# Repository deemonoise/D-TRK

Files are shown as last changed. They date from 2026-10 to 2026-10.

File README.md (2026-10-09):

# D-TRK

A 16-track tracker with a built-in synthesizer on the **WT32-SC01 Plus** (ESP32-S3, 480×320 touchscreen).
16 patterns, song mode, Fill (every Nth / Euclid / random) for notes, volume and FX, saving to microSD, MIDI file import.
Built-in sound: FM, 808 / 909 drum machines, the SYNTH synthesizer (saw / square / triangle and wavetable), a sampler and chiptune, played through the board's built-in amplifier — each track plays either the internal synth or external MIDI.

User manual: [docs/manual.md](docs/manual.md). Русская версия: [README_ru.md](README_ru.md).
3D-printable enclosure and battery power circuit: [enclosure/](enclosure/README.md).

## Wiring

The built-in display, touch panel and microSD slot are already routed on the board. You only need to connect the controls and the MIDI output — to the board's expansion connector (Extended IO); the track buttons go to the Debug connector. Full soldering diagram (power, MIDI, buttons, headphones): [docs/wiring.md](docs/wiring.md).

| GPIO | What to connect | How |
|---|---|---|
| 10 | MIDI OUT | through a 10 Ω resistor to the Tip of the TRS jack (see diagram below) |
| 11 | Encoder, pin A | the other end — the encoder's common pin to GND |
| 12 | Encoder, pin B | |
| 13 | Encoder button | button between GPIO and GND |
| 14 | **Play** button | button between GPIO and GND |
| 21 | **Shift** button | button between GPIO and GND |
| 43 / 44 | Track buttons: SDA / SCL of the PCF8575 module | Debug connector (TXD0 / RXD0), optional, see below |
| 3.3V | MIDI OUT | through a 33 Ω resistor to the Ring of the TRS jack |
| GND | Common | encoder common pin, the other pins of the buttons, Sleeve of the TRS jack |

The inputs use the internal pull-up to 3.3 V (`INPUT_PULLUP`), so no external resistors are needed. The buttons short the pin to GND.

### Encoder

A regular mechanical EC11 with a push button (4 pulses per detent). The middle pin of the A–C–B row goes to GND, the outer ones to GPIO 11 and 12. If the value moves the wrong way when turning, swap A and B.

It is a good idea to add 10 nF capacitors from A and B to GND — they reduce contact bounce. The firmware has the PCNT hardware filter and a 5 ms software debounce for the buttons.

### Track buttons (optional)

8 MX buttons and 8 3 mm LEDs in the switch windows, via a PCF8575 expander on I2C (port 0; port 1 is used by the touch panel). There are 16 tracks; the buttons work on the visible half (1–8 or 9–16, see below). If the module does not respond at startup, the firmware runs without it.

| PCF8575 | Connection |
|---|---|
| SDA / SCL | GPIO 43 / 44 (TXD0 / RXD0 of the Debug connector) |
| VCC / GND | 3.3 V / GND (from the same connector) |
| INT | leave unconnected |
| A0–A2 | any: the firmware looks for the module at 0x20–0x27 |
| P00–P07 | buttons 1–8, other pin to GND |
| P10–P17 | LED 1–8 cathodes |

The pin mapping is set in `src/hw/pins.h` (`kTrackBtnBit`, `kTrackLedBit`): if a pin is damaged, a button can be moved to the pin of an unfitted LED (number 8–15 = P10–P17), and that LED marked as `0xFF`.

```
+3.3V ──[330 Ω]──|>|── P1x     (LED is lit when P1x = 0)
```

- 330 Ω — for red/yellow/green LEDs (≈ 4 mA). White and blue ones don't have enough headroom at 3.3 V: use 47–68 Ω, and brightness will vary from unit to unit.
- The PCF8575 pulls a pin down (up to 25 mA) but up only with a weak pull-up, so the LEDs are switched only on the cathode, as in the diagram.
- 4.7 kΩ SDA/SCL pull-ups to 3.3 V are usually already on the module — check.
- INT is not needed: the firmware polls the module every 5 ms. The detected address is printed to the USB log (`trackio: PCF8575 at 0x..`).
- If the A0–A2 pads are not bridged anywhere and the module has no resistors to GND, the address floats and may "wander" — in that case bridge the pads to GND.
- GPIO 43/44 are free because the log and flashing go through the native USB (`ARDUINO_USB_CDC_ON_BOOT=1`). At startup the ESP32 bootloader prints to TXD0 (GPIO 43) — this does not bother the module.
- The buttons and LEDs work on the visible half of the tracks — 1–8 or 9–16; the half is chosen by the cursor (move past track 8 and the second half is shown; the GRID header shows `1-8` / `9-16`). Button N selects track N of that half, Shift + N mutes the same track (the toast shows the real number, 1–16), and in GRID edit mode the buttons enter scale degrees. LED N is the same track: lit for the selected one, flashes on notes; activity in the other half is not shown. Details in the [manual](docs/manual.md#trackkeys).

### MIDI OUT (TRS type A, 3.3 V)

```
+3.3V  ──[33 Ω]── Ring   (MIDI DIN pin 4)
GPIO10 ──[10 Ω]── Tip    (MIDI DIN pin 5)
GND    ────────── Sleeve (MIDI DIN pin 2, shield)
```

- TRS **type A** pinout (MMA standard): Tip = pin 5, Ring = pin 4. Type B devices (some Arturia, Novation) need an A→B adapter, or swap Tip and Ring.
- For a 5-pin DIN jack: the same resistors on pin 4 and pin 5, GND on pin 2.
- Non-inverted UART, 31250 baud. Optionally, a 74HC14 buffer (two inverters in series) can be placed between GPIO10 and the 10 Ω resistor.
- There is no MIDI input: the device is always the master and sends clock, Start/Stop/Continue.

### Built-in peripherals (for reference)

| Block | Pins |
|---|---|
| microSD (SPI) | CS 41, MOSI 40, CLK 39, MISO 38 |
| FT6336U touch (I2C) | SDA 6, SCL 5, INT 7, RST 4 (shared with LCD) |
| ST7796 display | 8080 bus, 8-bit (internal board routing) |

GPIO 1, 2, 42 go to the built-in RS485 transceiver; only the A/B lines reach the connector. GPIO 35, 36, 37 are I2S to the built-in NS4168 amplifier (built-in sound, see below). GPIO 43/44 (Debug connector) are used by the track buttons.

## Sound

Built-in synthesizer: 32 instruments (FM — 8 machines; DRUM — 16 machines in the spirit of the TR-808 / TR-909; SYNTH — 2 oscillators BL saw / square / tri or wavetable, sub, noise, sync; SAMPLE — project samples, played from flash; CHIP — pulse, triangle, saw, noise, metal, 16 wavetables; see below), each with a filter and LFO, 16 voices, 32 kHz, mono. A track is switched in TRACK → Out: INT (default in a new project) or MIDI. Sound goes to the built-in NS4168 amplifier — the **SPK** connector on the board, no soldering needed. Master volume: MIX tab → MAIN, 0–200 % (above 100 % — up to +6 dB, peaks of loud chords are softly clipped); saved with the project and included in Render WAV. Output level of the device (headphones / speaker): PROJ → SYS → Phones, 0–100 %, a device setting stored in the board's memory.

> **WARNING: the SPK output is bridged (BTL).** Both pins of the connector carry signal, **neither of them is ground**.
> - Speaker (4–8 Ω) — directly across the two SPK pins.
> - Headphones — only through an **isolated** jack (the jack body does not touch the device enclosure or GND), with **100–220 Ω resistors in series**. Start at minimum volume.
> - **Never** connect the SPK pins to the board's GND, to the ground of other devices, or to line inputs (mixer, audio interface, amplifier, recorder) — this shorts the amplifier output and risks burning it or the connected device. A line output needs a separate DAC (see [plans](docs/plans/future-audio.md)).

### Headphone jack (optional)

A 3.5 mm stereo jack (TRS), mono signal to both ears. Connects to the SPK connector in parallel with the speaker or instead of it.

```
SPK+ ──[150 Ω]──┬── Tip    (left)
SPK+ ──[150 Ω]──┴── Ring   (right)       each ear through its own resistor
SPK− ────────────── Sleeve (common)      NOT GND! jack is isolated
```

Speaker and headphones play together. To be able to switch the speaker off, put a switch in its wire:

```
SPK+ ──[switch]── Speaker (+)
SPK− ──────────── Speaker (−)
```

- 100–220 Ω, 0.25 W resistors, one each on Tip and Ring. Below 100 Ω — loud, with high current through the headphones; higher — quieter. 150 Ω is the middle ground.
- Sleeve goes to **SPK−**, not to GND. The jack sits in a plastic body or a plastic panel (the printed enclosure works); its contacts do not touch GND, the MIDI jack body, USB or other connectors.
- This jack is for **headphones only**. A cable from it to a mixer, audio interface or powered speakers would connect SPK− to their ground: that shorts the amplifier output.
- Before first power-up — Phones (PROJ → SYS) at minimum, headphones off your ears, then bring it up.
- The jack's built-in break contact is not suitable for disconnecting the speaker: on ordinary jacks it is connected to Tip, and Tip goes through a resistor. You need a separate switch or a jack with an isolated pair of switching contacts.

The internal sound lags behind MIDI tracks by about 14 ms (constant, no jitter). Synthesizer load is shown by `CPU NN%` in the right corner of the status bar (average over 0.5 s; yellow from 60% or if at least one block in the window took longer than 4 ms to compute — this is covered by the DMA queue; red from 85% or for 2 s after an audio dropout — an emptied DMA queue, an audible click).

### Samples

- Samples belong to the project: each project has its own list (up to **128**), and an instrument (INST → Sample) chooses only from it. On the card, a project is `/projects/NAME.mtp` plus the folder `/projects/NAME/` with its samples (`<sample>.wav`, mono, 16-bit). The folder is written by Save: missing and changed WAVs are written, files of samples removed from the project are deleted. If the folder could not be written — "SAMPLES NOT SAVED", the project stays unsaved (`*`), and the next Save completes it.
- To move a project to another card or tracker, copy the `.mtp` and its folder (with a card reader or over Wi-Fi). Load and autoload pull samples that are not in flash from the project folder (with progress); if a file is not found or has changed, the sample is marked `MISSING` (silent), toast "N SAMPLES MISSING".
- Flash (the `samples` partition, ~9.9 MB, ≈ 2.5 min mono at 32 kHz, up to 128 entries) is the cache the samples play from. Identical data in different projects is stored once. When space runs out, import and loading evict other projects' samples on their own (largest first) and compact the flash; otherwise "BANK FULL". The cache does not depend on the card, and a normal reflash (USB or OTA) does not touch it. The partition came with a new partition table — after updating from an old version, flash **once over USB** (see [Build and flash](#build-and-flash)), otherwise FILE → SAMPLES shows "NO SAMPLE BANK".
- FILE → SAMPLES: the line `FREE n / m KB  CACHE k KB` (CACHE — space taken by other projects' samples), **Import WAV…**, **Compact** (compact the flash), **Clear cache** (remove from flash everything not in the current project), then the project's samples: name, length, size, red `MISSING`. Click a sample — **Rename** (also renames it in instruments; a MISSING sample cannot be renamed) or **Delete** (remove from the project; the next Save deletes the file).
- `/samples` on the card (created automatically) is the import library, subfolders allowed up to 4 levels. Import WAV…: folders first (`name/`, click to enter, `< Up (..)` to go up), then `.wav` files; hidden files (macOS `._*`) are not shown. Play on a file previews it (first 8 s, Play again stops; in this list the Play button does not start the transport). An imported sample goes into the project folder on save.
- WAV: PCM **8 / 16 / 24-bit**, mono or stereo (stereo is mixed down to mono), any sample rate: above 32 kHz it is downsampled to 32 kHz, lower rates are stored as is. **Float and 32-bit are not supported** ("UNSUPPORTED WAV").
- Import, Rename, Delete, Compact and Clear cache work only with playback stopped (writing to flash stops the sound).
- Old projects (from when samples were shared): on load the list is built from the instruments, and samples are taken from flash by their old names. Save such a project once and its folder will appear.
- `.wav` files can be uploaded over Wi-Fi to `/samples` (and subfolders, up to 4 MB) or straight into the project folder (up to 10 MB).

### FM

**FM** — 8 machines in the style of the Model:Cycles: KICK, SNARE, METAL, PERC, TONE, CHORD, CLAP, HAT. Instead of operators there are 5 macros: DECAY (length), COLOR (brightness / index), SHAPE (timbre variant; for CHORD — chord type), SWEEP and CONTOUR (pitch or index envelope). Percussion plays one-shot (note length and ADSR don't matter, a new note cuts off the previous one); TONE and CHORD hold the note (attack / sustain / release from the ADSR). TONE can be POLY; the other machines are mono per track.

P-lock: fx `DEC`, `COL`, `SHP`, `SWP`, `CON` (0–127) set a macro for the note on their step; on a step without a note — for the playing note until the next one. They work on FM, DRUM and SYNTH.

### KIT (drum track)

The **KIT** instrument type has 8 lanes: each is either its own mini-sampler (a project sample, Volume, Pitch, Decay) or a reference to any of the 32 instruments. A track with a KIT becomes a drum track: in GRID, instead of notes there are 8 squares per step; in edit mode, a pad of 8 buttons (and track buttons 1–8) toggles the lanes. Each lane is mono with choke; lanes sound together. On a MIDI track, the lanes are sent as their own notes (the lane's Note) — for an external drum machine. Fx `ACC` is a mask of lanes at full volume, the rest at 60 %. Fill (NOTE) writes to the selected lane. More in the [manual](docs/manual.md#drumtrack).

### DRUM (808 / 909)

**DRUM** — 16 "analog" machines: BD8, SD8, TOM8, CP8, RS8, CL8, CB8, HH8, CY8 (808) and BD9, SD9, TOM9, CP9, RS9, HH9, CY9 (909). The same 5 macro slots and `DEC…CON` locks, but each machine names them differently (TONE, SNAPPY, DRIVE, N.DEC, HP…); an empty slot is a grey "-". Every machine has DECAY. All machines are one-shot and mono per track: a new note cuts off the previous one (choke), note-off doesn't matter; Attack, Decay, Sustain, Release, Mode, Glide are greyed out. Note C4 is the machine's base pitch. Closed / open hat — short and long DECAY. The timbres approximate the originals (the 909 hats and cymbals are samples there, synthesis here). FM, DRUM and SYNTH with a WT oscillator together — no more than 8 voices at once (an extra one steals the oldest).

### SYNTH (oscillators and wavetable)

**SYNTH** — an "analog" synthesizer: 2 oscillators, each in **SAW**, **SQR**, **TRI** mode (alias-free, PolyBLEP) or **WT** (a wavetable of 64 frames × 256 points with mipmaps, frame position = SHAPE), plus sub (a square −1 / −2 octaves below osc 1), white noise, hard sync of osc 2 to osc 1, osc 2 semitones (±24) and its own AD envelope on SHAPE (Env>Shp ±). The volume envelope is ADSR; Mode POLY / MONO and Glide work as on CHIP. INST pages: MAIN / ENV / **OSC** / **MOD** / FILT / LFO.

- 5 macros on the same slots as FM / DRUM: **SHP1** (square PW or WT frame of osc 1), **SHP2** (the same for osc 2), **MIX** (osc 1 ↔ osc 2), **DET** (osc 2 detune, ±50 cents), **SENV** (env→SHAPE depth). Locks are fx `DEC`, `COL`, `SHP`, `SWP`, `CON` respectively; LFO dest — SHP1…SENV.
- Wavetables: 8 built-in (`*SAWSQR`, `*PWM`, `*SINSAW`, `*TRISQR`, `*FORMANT`, `*ORGAN`, `*SYNC`, `*BELL`) — built into the flash bank on first start, work without a card. Your own — **IMPORT…** in the wavetable chooser (tap / click the Table row) from `/wavetables` on the card (with subfolders up to 4 levels): WaveEdit (256-point frames, up to 64) and Serum / Vital (2048-point frames or a `clm` chunk; with more than 64 frames, they are taken evenly). One wavetable takes 96 KB of flash; up to 32 wavetables per project. A name already in use with different data gets a `-2`, `-3`… suffix.
- Save writes the project's wavetables to `/projects/NAME/wt/<name>.wav`, and Load pulls missing ones into flash from there. If a wavetable is neither in flash nor in the folder, its name in INST is red and the oscillator is silent.
- Import works only with playback stopped ("STOP PLAYBACK FIRST"). 37 factory presets (BASS, LEAD, PAD, KEYS, PLUCK, FX) on the built-in wavetables; your own go in `/presets/SYNTH/`.

### Filter and LFO

All types have these at the end of the INST list:

- **Filter** OFF / LP / BP / HP (SVF, 12 dB/oct), **Cutoff** 20 Hz…14 kHz, **Reso** 0–127, **Flt env** ±6 octaves with its own **Flt attack** / **Flt decay** (HOLD — hold), **Key track** 0–100 % (from C4). The filter comes after the whole voice; OFF is a bypass, so old projects sound as before.
- **LFO** wave / rate / depth / dest — now on all types. Targets PITCH, VOL, CUTOFF — everywhere; DECAY…CONTOUR — only FM, DRUM and SYNTH (on SYNTH — SHP1…SENV).
- Filter p-locks: fx `FLT` (cutoff) and `RES` (resonance), 0–127, on any INT instrument with the filter enabled; on a step without a note — for the track's playing voices until the next note.

### Drive, reverb, compressor

- **Drive** (INST → FILT, first row): tanh overdrive before the filter, lock `DRV`, LFO target `DRIVE`.
- **Reverb**: the instrument's Rvb send (lock `RVB`), size / decay / level in PROJ. 23 KB buffer in PSRAM.
- **Compressor** on all built-in sound (PROJ → Comp, Comp rel) with **sidechain** from a track (SC track, SC depth): set SC track to the kick and the mix "pumps".
- **ARP**: fx `ARM` sets the order (up, down, up-down, random) and the number of notes per step (1–8); ARP + CHD on the same step arpeggiates the chord.
- **4 LFOs** per instrument (INST → LFO), each with a free Hz rate or tempo sync (1/32 … 8 bars) and the phase retriggered on every note or free-running (Retrig ON / OFF).
- **Lo-fi**: fx `BIT` (bit depth) and `SRR` (sample rate) per note; **DJ filter** on the master (PROJ → FX).
- Pattern **groove** (PROJ → SONG → Groove: MPC 54–66, SHUFFLE, PUSH, LAID BACK, DRUNK, BOOM BAP, HOUSE) and track **Humanize** (TRACK → NOTE); conditions `CND PRE / NEI`, volume ramp up/down on `RAT` (`4^`, `4v`).
- **Step arp** `ARS` (INT and MIDI): the CHD notes (or ARP 0/x/y, or the note itself) across a range of 1–4 octaves play as separate notes on the track's following empty steps — every step or every N; until the next note, OFF or a pattern change. The fx list in GRID is grouped: notes and arp, timing, randomness, pitch and volume, sound, sample, sends, MIDI.
- **Velocity**: Vel>Cut (filter cutoff) and Vel>Dec (DECAY macro) in INST → ENV.

Everything is off by default: old projects and presets sound as before. Presets with the new fields are version 4; old firmware cannot open them.

### Presets

The **PRESET** button in the INST header (or Shift + long press of the encoder) → **Load** / **Save**.

- **Load:** a list for the instrument type (arrows in the header or Shift + turn — another type). At the root — `[FACTORY]` (145 factory presets: 33 CHIP, 37 FM, 38 DRUM, 37 SYNTH, by category; up to 63 rows are visible in one category or folder), then your own folders and files. The selected preset is applied to the instrument immediately and plays C4. **OK** — keep it, **CANCEL** (or a long press) — revert, **DEL** — delete your own preset.
- **Save:** **SAVE** — name on the keyboard (if it already exists, asks whether to overwrite), **+DIR** — new folder, click a file — overwrite it. The file name also becomes the instrument name.
- On the card: `/presets/CHIP|SAMPLE|FM|DRUM|SYNTH/…/NAME.mti` (204 bytes, format v3; old v1 / v2 are readable), up to 4 folder levels inside a type. A SAMPLE preset applies its sample only if it is in the project; otherwise the sample and Root stay as they were. A SYNTH preset stores wavetable names: if a wavetable is not in the project, it is imported from `/wavetables/<name>.wav` (with playback stopped); otherwise the name is red.

Details (INST tab, preset browser, DRUM machine table, SYNTH and wavetables, fx SLD/VIB/ARP/VSL/OFS/CUT, DEC/COL/SHP/SWP/CON, FLT/RES) are in the [manual](docs/manual.md#sound).

## Song and live performance

- **Song mode** (BANK): each chain entry has a pattern, a transposition of melodic tracks (±24), a number of passes (x1–x16) and a mute scene (S1–S8) that is applied when the entry starts. The chain row reads `P05 +3 x2 S1`; Shift + turn in row edit mode selects the field.
- **Mute scenes**: 8 tiles under the chain — tap recalls, long tap stores the current mutes, Shift + tap clears.
- **Per-track length** (TRACK → Pat len): the track loops its first N steps within the pattern (polymeter); in GRID the steps beyond are grey, and the boundary is marked with a line.
- **Fill**: hold Shift + Play while playing — steps with `CND FIL` play, those with `NFL` are silent; a short press is pause, as before.
- **REC** (GRID menu): while playing, the track buttons write scale degrees into the playing step of the current track (on a drum track — lanes); Shift + N erases.
- **PERF** (GRID menu): an effect while the button is held — 1 RAT 2, 2 RAT 4, 3 filter closed, 4 open, 5 delay, 6 short DECAY, 7 fade, 8 mute.

More in the [manual](docs/manual.md#song).

## Mixer and render

- **MIX** is a separate tab at the bottom, next to TRACK: 8 strips for the half of the tracks under the cursor (volume fader, delay / reverb sends, M / S) and the MAIN strip — overall volume 0–200 % (moved here from PROJ).
- Track volume from any screen: hold its button and turn the encoder (Shift ×10); not in GRID edit mode, REC or PERF.
- **FILE → Render WAV…**: a pattern or the whole song (ALL, solo tracks only, or STEMS — each track to its own file) to `/samples/render/<project>_P01.wav` / `_SONG.wav`, mono 16-bit 32 kHz, with delay / reverb / compressor and a 2 s tail. The file can be downloaded over Wi-Fi or imported back as a sample.
- **GRID → Resample track / pattern**: a pattern (the current track or all audible ones) into a new project sample `RS1`, `RS2`… — normalized to −1 dBFS, trailing silence trimmed, up to 60 s.
- Render and resampling work only when stopped, roughly in real time; cancel with a long press of the encoder or Play.

More in the [manual](docs/manual.md#render).

## Interface

- **Themes**: PROJ → SYS → Theme, 17 built-in themes (CLASSIC, AMBER, PHOSPHOR, NORD, DRACULA, SOLARIZED, GRUVBOX, MONOKAI, TOKYO, MOCHA, ROSE PINE, GAMEBOY, C64, SYNTHWAVE, OCEAN, CONTRAST, PAPER). A device setting: stored in the board's memory, does not change the project.
- **Pages** in TRACK (MAIN / NOTE / MIDI) and PROJ (SONG / FX / COMP / SYS): tap a page tab, or use the encoder on the page tabs and click (Shift+click — back); the list wraps around.
- **PERF**: the effect of each button is configured in PROJ → PERF (RAT 2/3/4/8, ROLL UP, FILTER LOW/HIGH, DELAY/REVERB MAX, CRUSH, DOWNSAMPLE, DRIVE, SHORT DECAY, FADE, MUTE); pressing shows a toast with its name.
- **Project templates** (FILE → New: EMPTY, 808 SET, 909 SET, FM SET, CHIPTUNE, MIDI 8 and your own from `/templates`, Save as template), **8 demo songs** (FILE → New → Demo songs: trance, chiptune, acid, lo-fi, synthwave, dub techno, IDM, house), **autosave** to `/projects/<name>.auto` (PROJ → SYS → Autosave, FILE → Restore autosave), **safe start** (hold Shift at power-on — no autoload), **crash log** `/projects/crashlog.txt` and the firmware version in PROJ → SYS.
- **Wi-Fi page**: tabs per section, scrollable lists with a filter.
- **MIX**: encoder — MAIN volume, Shift+turn — tracks A (1–8) / B (9–16); track volume — its button + encoder, mute — Shift+button, solo — tap. Each track has a level meter; at the bottom there is a scope with auto-gain and a level meter / CLIP.

## SD card

**FAT32** with an **MBR** partition scheme. exFAT (the standard for cards over 32 GB) and GPT are not readable — the screen will show "NO SD CARD".

Format it with any tool that offers FAT32 with an MBR partition table (for cards over 32 GB the system formatter often offers only exFAT: use a third-party FAT32 formatter). Formatting erases the card.

The firmware creates the folders `/projects`, `/midi`, `/samples`, `/wavetables` and `/presets` (with subfolders `FM`, `DRUM`, `SAMPLE`, `CHIP`, `SYNTH`) itself. Put MIDI files for import in `/midi`, WAVs for importing into projects in `/samples`, wavetables for SYNTH in `/wavetables`. A project's samples live in `/projects/NAME/`, its wavetables in `/projects/NAME/wt/` (written by the tracker on save), instrument presets in `/presets/<TYPE>/`.

## Wi-Fi

FILE → **Wi-Fi transfer…**: the tracker joins your home network (network and password are entered on screen and stored in flash) and serves the page `http://d-trk.local` (or by the IP shown on screen). On the page:

- MIDI (`/midi`, `.mid` only, up to 512 KB), projects (`/projects`, `.mtp`/`.bak`) and samples (`/samples`, `.wav` only, up to 4 MB): upload, download, rename, delete; samples from `/samples` are then imported into a project on the tracker (FILE → SAMPLES);
- in the projects section, each project has a `name/` row (marked "samples") with its WAVs (up to 10 MB, name up to 16 characters): enter, upload, download, rename, delete. To move a project, upload the `.mtp`, open its "samples" row and upload the WAVs; if the folder does not exist yet, the first WAV creates it. Renaming a `.mtp` moves the folder, deleting a project (both `.mtp` and `.bak`) deletes it — except for the project open on the tracker: its folder stays (files in it can be changed; the next Save rewrites them from flash);
- wavetables (`/wavetables`, `.wav` only, up to ~3 MB, subfolders as for samples): imported into a project on the tracker (INST → SYNTH → Table → IMPORT…). The project's wavetables are in the project folder, subfolder `wt/` (marked "wavetables");
- in the samples section — subfolders: breadcrumb navigation, "New folder", deleting an empty folder; folder name up to 32 characters (Latin letters, digits, space, `.` `_` `-`, not starting with a dot), no deeper than 4 levels. MIDI has no subfolders;
- presets (`/presets`, `.mti` only, up to 1 KB, name up to 16 characters): at the root — type folders CHIP, SAMPLE, FM, DRUM, SYNTH (cannot be deleted), files only inside them, your own subfolders up to 4 levels. An uploaded preset is checked (CRC, version) and must be in the folder of its type, otherwise it is rejected;
- firmware update with the file `.pio/build/wt32/firmware.bin`.

While this mode is open, playback is stopped. Exit with EXIT, a long press of the encoder or another tab; Wi-Fi is turned off.

**Security:** the page has no password. While the mode is open, anyone on the same network can change files on the card and flash the tracker. Do not enable it on other people's or public networks.

More in the [manual](docs/manual.md#wifi).

## Build and flash

You need [PlatformIO](https://platformio.org/).

```
pio run -e wt32 -t upload     # build and flash over USB
pio run -e wt32-ota -t upload # over Wi-Fi: FILE → Wi-Fi transfer open on the tracker
pio test -e native            # core tests on the computer
```

The partition table is custom (`partitions.csv`): two 3 MB firmware slots and a `samples` partition (~9.9 MB) for the sample flash cache. After switching to it, flash once over USB (`pio run -e wt32 -t upload`): OTA does not change the partition table. Wi-Fi settings (NVS) are kept — `nvs` and `otadata` are at the same addresses.

## Structure

| Folder | Contents |
|---|---|
| `lib/core` | hardware-independent core: model, sequencer, fx, scales, Euclid and Fill, file format, MIDI parser, synthesizer (CHIP, SAMPLE, FM, DRUM, filter), WAV parser, sample bank, project sample list, presets |
| `src/engine` | sequencer task on core 0 (timer, MIDI output) |
| `src/audio` | built-in sound: I2S to the NS4168 amplifier, audio task, sample bank in flash, WAV import |
| `src/hw` | input (encoder, buttons), MIDI UART, SD, display configuration |
| `src/ui` | UI screens |
| `src/storage` | saving and loading projects and presets |
| `src/net` | Wi-Fi, file transfer web page, OTA |
| `test` | Unity tests of the core |
| `docs` | manual and development plans |
| `enclosure` | enclosure: OpenSCAD model and STL |

## License

Copyright © 2026 deemonoise.

- **Firmware, tests, scripts and documentation** — [GNU GPL v3](LICENSE) (GPL-3.0-only). You may use, change and share them, sell devices with them included, as long as the source of the firmware you ship (with your changes) is published under the same license.
- **Hardware** — the enclosure ([enclosure/](enclosure/): OpenSCAD sources and STL) and the wiring diagrams ([docs/img](docs/img)) — [CERN-OHL-S v2](enclosure/LICENSE) (CERN-OHL-S-2.0): products made from them must make their modified design sources available under the same license.

The name **D-TRK** and its logo are not covered by these licenses: a modified firmware or a device built from this project may say it is based on D-TRK, but must not be called or sold as D-TRK without permission.

Full texts: [LICENSES/](LICENSES/). Third-party libraries (ESP-IDF, Arduino-ESP32, LovyanGFX, Unity) keep their own licenses.

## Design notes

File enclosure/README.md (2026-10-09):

# D-TRK enclosure

Русская версия: [README_ru.md](README_ru.md)

Parametric model for 3D printing: [case.scad](case.scad) (OpenSCAD 2021.01). Ready-made STLs are in [stl/](stl/).

Overall size ~98.4 × 105.4 × 31 mm. On top: the whole WT32-SC01 Plus module (glass with bezel), with Shift, Play (MX) and the EC11 encoder below it. At the back: the charging Type-C (IP5306), the MIDI OUT mini jack and the power switch.

| File | Qty | How to print |
|---|---|---|
| `stl/case_top.stl` | 1 | face down on the bed, no supports |
| `stl/case_bottom.stl` | 1 | bottom down on the bed, no supports |
| `stl/clamp2.stl` | 1 plate (4 clamps) | flat, pins up |
| `stl/knob.stl` or `stl/knob8.stl` (case with track buttons) | 1 | top down on the bed, no supports ([knob.scad](knob.scad)) |

**Version with 8 track buttons** (Shift, Play and the encoder under the screen, 2 rows × 4 MX below them, PCF8575 expander; see the [plan](../docs/plans/future-track-buttons.md)): overall size 98.4 × 145.4 × 31 mm; print `stl/case8_top.stl` and `stl/case8_bottom.stl` instead of `case_*`, the clamps are the same. The 3 mm LEDs go into the standard windows of the MX switches (you need clear keycaps or keycaps with a window); the case does not change for them. Wiring is in the [README](../README.md#track-buttons-optional).

PLA/PETG, 3 wall perimeters, 20–30 % infill.

The bottom part is a tray 4.5 mm deep (`tray_h`) with a 3 mm floor: the battery sits 4.5 mm below the joint with the top, with 6 mm clearance to the module. Along the edge runs a 1.2 × 1.5 mm centring lip (`guide_t`, `guide_h`, clearance `guide_clr` = 0.2) that fits inside the top. If the fit is tight, reduce `guide_t` or increase `guide_clr`. The top does not depend on `tray_h`: you can change the tray depth without reprinting the top.

## Measure before printing

All dimensions are variables at the start of `case.scad`. Check with calipers:

| What | Variables | Default |
|---|---|---|
| Module: width, depth, thickness | `mod_w`, `mod_d`, `mod_h` | 92 × 60 × 10.8 |
| Lip over the bezel: overlap and thickness | `lip`, `lip_t` | 1.0 and 1.2 |
| 103450 battery | `bat_w`, `bat_d`, `bat_h` | 50 × 34 × 10 |
| IP5306: board (along the wall × inwards), thickness, Type-C jack | `ip_w`, `ip_d`, `ip_pcb`, `usbc_w`, `usbc_h` | 20 × 26 × 1.2, 9.2 × 3.4 |
| Jack and switch thread | `jack_d`, `sw_d` | 6.3 (M6) |
| Bosses on the module's back: centres from the left/right edge (looking at the screen), from the long edges | `boss_x0`, `boss_x1`, `boss_y` | 10.34, 6.52, 4.3 |
| Bosses: outer ⌀ and hole ⌀ | `boss_d`, `boss_hole` | 6 and 2.5 (not measured) |

`lip` is how far the lip overlaps the module's bezel. Increase it if the bezel is wider and the window shows too much; decrease it if the lip covers the active area of the screen.

The clamps press the module by its 4 corner bosses; the `pin_d` pin (2 mm) goes into the boss hole and keeps the clamp from turning around its screw — `pin_d` must be smaller than `boss_hole`. The 10.34 offset is from the right edge looking at the board, i.e. from the left edge looking at the screen; if the module sits in the case rotated 180°, set `boss_flip = true`. The old bars (v1, 2 pcs. with tape) are `part="clamp"`.

After editing, rebuild the STLs:

```
OS=openscad   # OpenSCAD 2021.01 or newer; give the full path if it is not on PATH
$OS -o stl/case_top.stl    -D 'part="top"'    case.scad
$OS -o stl/case_bottom.stl -D 'part="bottom"' case.scad
$OS -o stl/clamp2.stl      -D 'part="clamp2"' case.scad
```

For the track-button version, add `-D trk=true` and write to `stl/case8_*.stl`. Measure the PCF8575 module: `pcf_w`, `pcf_d` (default 32 × 20).

`part="assembly"` (the default) is an assembly with component mock-ups for checking in OpenSCAD.

The most critical part is the top: print `case_top.stl` first and test-fit the module, then the rest.

## Encoder knob

[knob.scad](knob.scad): ⌀30 × 18 mm, flat top, diamond knurling (two opposing helical grooves, pitch ~2.6 mm — 36 of them on ⌀30, 30° to the axis), fits a D-shaft. The underside is recessed for the nut and threaded bushing, so the knob floats 1 mm above the panel (0.5 mm with the encoder button pressed). The shaft goes 12.5 mm into the knob.

Case with track buttons: the encoder sits on the MX grid (19 mm pitch), and a ⌀30 knob would overlap the keycap below it. For this case use `knob8.stl` — ⌀17 × 18 mm, 21 grooves: 1.5 mm clearance to the 18 mm keycap, more than 10 mm to the screen window and the right wall. The wall around the nut is ~1.4 mm (2.2 without a groove); print with 3–4 perimeters.

Measure the encoder:

| What | Variable | Default |
|---|---|---|
| Shaft from the encoder body's seating plane to the tip | `shaft_l` | 20 |
| Shaft ⌀ and size across the flat | `shaft_d`, `shaft_dd` | 6 and 4.5 |
| Flat length | `flat_l` | 10 |
| Bushing: ⌀ and height | `bush_d`, `bush_l` | 7 and 7 |
| Nut: across flats and height, washer | `nut_af`, `nut_h`, `washer_t` | 10, 2, 0.5 |
| Button travel | `push` | 0.5 |

The knob height depends on `shaft_l`. If it is tight on the shaft, increase `shaft_clr` (0.15); if it wobbles, decrease it. `part="view"` shows the knob on the panel with an encoder mock-up.

```
$OS -o stl/knob.stl knob.scad
$OS -o stl/knob8.stl -D knob_d=17 knob.scad
```

## Hardware and materials

- M3 heat-set inserts (5–6 mm long, outer ⌀ ~4.5) — 8 pcs.
- M3 × 10 DIN 912 screws (socket head cap) — 4 pcs. (bottom part, heads sunk flush).
- M3 × 6 screws — 4 pcs. (clamps).
- ~1 mm foam double-sided tape — under the battery.
- PJ-392 panel-mount mini jack (TRS 3.5 mm, M6 nut).
- MTS-102 toggle switch (M6 nut).
- IP5306 charger/power-bank module with Type-C and USB-A (desolder the USB-A).
- LiPo 103450 battery (~2000 mAh).
- 2 MX switches (10 for the track-button version), EC11 encoder with push button, keycaps.
- Track-button version: PCF8575 module, 8 × 3 mm LEDs, 8 × 330 Ω resistors.

## Power

The IP5306 module charges the LiPo from Type-C by itself and puts out a stable 5 V. Desolder the USB-A socket (otherwise it won't fit height-wise) and solder the output wires to its VBUS and GND pads.

```
LiPo + ── IP5306 B+ (BAT+)
LiPo − ── IP5306 B− (BAT−)
IP5306 VOUT (VBUS USB-A) ── switch ── board 5V
IP5306 GND               ───────────── board GND
```

The switch is on the output, not on the battery: this way charging works even with the device switched off.

IP5306 quirks:
- The output turns on by itself when a load appears (the switch is closed). If it does not, briefly press the module's button or short its pads (KEY) to GND. If there is no button and auto-start is unreliable, move the switch into the battery line, but then charge only with the switch on.
- Below ~50 mA the output shuts off after ~30 s. The board draws ~175 mA, so this is not a problem.
- The output stays on while charging (power comes from Type-C). At the moment charging is connected or disconnected the output may drop briefly and the board will reboot. Connect the charger with the device off, or after saving.
- The charge-level LEDs are on the board inside the case and are not visible from outside.

Do not connect the battery directly to the board's 3.3V or 5V.

The board's own Type-C (flashing) and the microSD slot are accessible only with the lid off. Do not flash with the switch closed: two 5 V sources on the same line.

## Assembly

1. Melt the inserts in with a soldering iron: 4 into the corner posts, 4 into the clamp posts (all in the top part).
2. Insert the module screen-down into the pocket of the top part, until it rests against the lip.
3. Put the clamps' pins into the holes of the module's corner bosses and screw the clamps to the posts with M3 screws.
4. Snap the MX switches into the panel from above. The encoder goes in from below, secured with its nut from above.
5. Fit the jack and the switch into the back-wall holes and tighten their nuts. Turn the switch so the long side of its body (7.9 mm) is vertical.
6. In the bottom part: the IP5306 into its cradle with the Type-C jack towards the back wall, the battery on tape against the ridge under the module.
7. Solder the power (see above); the controls and MIDI OUT per the table in the [root README](../README.md#wiring).
8. Check for ~5 V at the IP5306 output before connecting it to the board, then close the bottom part with 4 M3 × 10 screws.

## License

The enclosure (OpenSCAD sources and STL): © 2026 deemonoise, [CERN-OHL-S v2](LICENSE).

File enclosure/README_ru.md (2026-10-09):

# Корпус D-TRK

Параметрическая модель для 3D-печати: [case.scad](case.scad) (OpenSCAD 2021.01). Готовые STL — в [stl/](stl/).

English: [README.md](README.md)

Габарит ~98,4 × 105,4 × 31 мм. Сверху — модуль WT32-SC01 Plus целиком (стекло с рамкой), под ним Shift, Play (MX) и энкодер EC11. Сзади — Type-C зарядки (IP5306), mini jack MIDI OUT, тумблер питания.

| Файл | Кол-во | Как печатать |
|---|---|---|
| `stl/case_top.stl` | 1 | лицом на стол, без поддержек |
| `stl/case_bottom.stl` | 1 | дном на стол, без поддержек |
| `stl/clamp2.stl` | 1 стол (4 лапки) | плашмя, штырьками вверх |
| `stl/knob.stl` или `stl/knob8.stl` (корпус с кнопками дорожек) | 1 | верхом на стол, без поддержек ([knob.scad](knob.scad)) |

**Вариант с 8 кнопками дорожек** (Shift, Play, энкодер под экраном, под ними 2 ряда × 4 MX, расширитель PCF8575; см. [план](../docs/plans/future-track-buttons.md)): габарит 98,4 × 145,4 × 31 мм, вместо `case_*` печатать `stl/case8_top.stl` и `stl/case8_bottom.stl`, лапки те же. Светодиоды 3 мм ставятся в штатные окна свичей MX (нужны прозрачные колпачки или колпачки с окном), корпус под них не меняется. Схема — в [README](../README_ru.md#кнопки-дорожек-необязательно).

PLA/PETG, стенки 3 периметра, заполнение 20–30 %.

Нижняя часть — корыто глубиной 4,5 мм (`tray_h`) с дном 3 мм: аккумулятор лежит на 4,5 мм ниже стыка с верхом, зазор до модуля 6 мм. По кромке — центрирующая губа 1,2 × 1,5 мм (`guide_t`, `guide_h`, зазор `guide_clr` = 0,2), заходит внутрь верха. Если туго — уменьшить `guide_t` или увеличить `guide_clr`. Верх от `tray_h` не зависит: менять глубину корыта можно без перепечатки верха.

## Замерить перед печатью

Все размеры — переменные в начале `case.scad`. Штангенциркулем проверить:

| Что | Переменные | По умолчанию |
|---|---|---|
| Модуль: ширина, глубина, толщина | `mod_w`, `mod_d`, `mod_h` | 92 × 60 × 10,8 |
| Бортик над рамкой: нахлёст и толщина | `lip`, `lip_t` | 1,0 и 1,2 |
| Аккумулятор 103450 | `bat_w`, `bat_d`, `bat_h` | 50 × 34 × 10 |
| IP5306: плата (вдоль стенки × вглубь), толщина, гнездо Type-C | `ip_w`, `ip_d`, `ip_pcb`, `usbc_w`, `usbc_h` | 20 × 26 × 1,2, 9,2 × 3,4 |
| Резьба jack и тумблера | `jack_d`, `sw_d` | 6,3 (M6) |
| Бобышки на задней стороне модуля: центры от левого/правого края (смотря на экран), от длинных краёв | `boss_x0`, `boss_x1`, `boss_y` | 10,34, 6,52, 4,3 |
| Бобышки: наружный ⌀ и ⌀ отверстия | `boss_d`, `boss_hole` | 6 и 2,5 (не замерены) |

`lip` — насколько бортик заходит на рамку модуля. Увеличить, если рамка шире и окно открывает лишнее; уменьшить, если бортик наезжает на активную область экрана.

Лапки прижимают модуль за 4 угловые бобышки; штырёк `pin_d` (2 мм) входит в отверстие бобышки и не даёт лапке провернуться вокруг винта — `pin_d` должен быть меньше `boss_hole`. Отступ 10,34 — от правого края, смотря на плату, то есть от левого, смотря на экран; если модуль в корпусе развёрнут на 180°, поставить `boss_flip = true`. Старые планки (v1, 2 шт. со скотчем) — `part="clamp"`.

После правки — пересобрать STL:

```
OS=openscad   # OpenSCAD 2021.01 или новее; полный путь, если его нет в PATH
$OS -o stl/case_top.stl    -D 'part="top"'    case.scad
$OS -o stl/case_bottom.stl -D 'part="bottom"' case.scad
$OS -o stl/clamp2.stl      -D 'part="clamp2"' case.scad
```

Вариант с кнопками дорожек — добавить `-D trk=true` и писать в `stl/case8_*.stl`. Модуль PCF8575 замерить: `pcf_w`, `pcf_d` (по умолчанию 32 × 20).

`part="assembly"` (по умолчанию) — сборка с макетами компонентов для проверки в OpenSCAD.

Самая критичная деталь — верх: сначала напечатать `case_top.stl` и примерить модуль, потом остальное.

## Кноб энкодера

[knob.scad](knob.scad): ⌀30 × 18 мм, верх плоский, алмазная накатка (две встречные винтовые канавки, шаг ~2,6 мм — 36 шт. на ⌀30, 30° к оси), посадка на D-вал. Снизу выборка под гайку и резьбовую втулку, поэтому кноб висит над панелью на 1 мм (при нажатии на кнопку энкодера — 0,5 мм). Вал заходит в кноб на 12,5 мм.

Корпус с кнопками дорожек: энкодер стоит в сетке MX (шаг 19), ⌀30 наезжает на колпачок под ним. Для него `knob8.stl` — ⌀17 × 18 мм, 21 канавка: до колпачка 18 мм остаётся 1,5 мм, до окна экрана и правой стенки — больше 10 мм. Стенка вокруг гайки ~1,4 мм (без канавки 2,2), печатать с 3–4 периметрами.

Замерить энкодер:

| Что | Переменная | По умолчанию |
|---|---|---|
| Вал от опорной плоскости корпуса энкодера до конца | `shaft_l` | 20 |
| ⌀ вала и размер по лыске | `shaft_d`, `shaft_dd` | 6 и 4,5 |
| Длина лыски | `flat_l` | 10 |
| Втулка: ⌀ и высота | `bush_d`, `bush_l` | 7 и 7 |
| Гайка: под ключ и высота, шайба | `nut_af`, `nut_h`, `washer_t` | 10, 2, 0,5 |
| Ход кнопки | `push` | 0,5 |

От `shaft_l` зависит высота кноба. Туго садится на вал — увеличить `shaft_clr` (0,15), болтается — уменьшить. `part="view"` — кноб на панели с макетом энкодера.

```
$OS -o stl/knob.stl knob.scad
$OS -o stl/knob8.stl -D knob_d=17 knob.scad
```

## Крепёж и материалы

- Вплавляемые гайки M3 (длина 5–6 мм, внешний ⌀ ~4,5) — 8 шт.
- Винты M3 × 10 DIN 912 (цилиндрическая голова под шестигранник) — 4 шт. (нижняя часть, головы утоплены заподлицо).
- Винты M3 × 6 — 4 шт. (лапки).
- Пористый двусторонний скотч ~1 мм — под аккумулятор.
- Mini jack панельный PJ-392 (TRS 3,5 мм, гайка M6).
- Тумблер MTS-102 (гайка M6).
- Модуль зарядки/повербанка на IP5306 с Type-C и USB-A (USB-A выпаять).
- Аккумулятор LiPo 103450 (~2000 мАч).
- 2 переключателя MX (вариант с кнопками дорожек — 10), энкодер EC11 с кнопкой, колпачки.
- Вариант с кнопками дорожек: модуль PCF8575, 8 светодиодов 3 мм, 8 резисторов 330 Ом.

## Питание

Модуль IP5306 сам заряжает LiPo от Type-C и выдаёт стабильные 5 В. Гнездо USB-A выпаять (иначе не влезет по высоте), провода выхода паять на его площадки VBUS и GND.

```
LiPo + ── IP5306 B+ (BAT+)
LiPo − ── IP5306 B− (BAT−)
IP5306 VOUT (VBUS USB-A) ── тумблер ── 5V платы
IP5306 GND               ───────────── GND платы
```

Тумблер стоит на выходе, а не на аккумуляторе: так зарядка работает и при выключенном устройстве.

Особенности IP5306:
- Выход включается сам, когда появляется нагрузка (замкнули тумблер). Если не включился — коротко нажать кнопку модуля или замкнуть её площадки (KEY) на GND. Если кнопки нет, а автостарт капризничает — перенести тумблер в цепь аккумулятора, но тогда заряжать только во включённом положении.
- При токе меньше ~50 мА выход отключается через ~30 с. Плата берёт ~175 мА, это не мешает.
- Во время зарядки выход работает (питание идёт от Type-C). В момент подключения или отключения зарядки выход может кратко пропасть — плата перезагрузится. Подключать зарядку лучше на выключенном устройстве или после сохранения.
- Светодиоды уровня заряда — на плате внутри корпуса, снаружи не видны.

Аккумулятор напрямую на 3.3V или 5V платы не подключать.

Type-C самой платы (прошивка) и слот microSD доступны только со снятой крышкой. Не прошивать с замкнутым тумблером: два источника 5 В на одной линии.

## Сборка

1. Вплавить гайки паяльником: 4 в угловые стойки, 4 в стойки лапок (все в верхней части).
2. Вставить модуль экраном вниз в карман верхней части, до упора в бортик.
3. Поставить лапки штырьками в отверстия угловых бобышек модуля и прикрутить винтами M3 к стойкам.
4. Защёлкнуть MX-переключатели в панель сверху. Энкодер — снизу, закрепить гайкой сверху.
5. Jack и тумблер — в отверстия задней стенки, затянуть гайками. Тумблер повернуть длинной стороной корпуса (7,9 мм) вертикально.
6. В нижнюю часть: IP5306 в ложемент гнездом Type-C к задней стенке, аккумулятор на скотч в бортик под модулем.
7. Распаять питание (см. выше), органы управления и MIDI OUT — по таблице в [корневом README](../README_ru.md#подключение).
8. Проверить ~5 В на выходе IP5306 до подключения к плате, затем закрыть нижнюю часть 4 винтами M3 × 10.

## Лицензия

Корпус (исходники OpenSCAD и STL): © 2026 deemonoise, [CERN-OHL-S v2](LICENSE).

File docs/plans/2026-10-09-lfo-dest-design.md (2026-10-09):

# Больше LFO dest + LFO на LFO — дизайн

Сейчас у 4 LFO 9 целей: PITCH, 5 макро (DECAY..CONTOUR / SHP1..SENV), VOL, CUTOFF, DRIVE. Нужно —
почти любой параметр синта и модуляция одного LFO другим (rate, depth, retrig).

## Подход
Расширяем `LfoDest`: новые цели дописываются в конец enum (перед Count), диспетчер в `Synth::control`
растёт. Формат файлов не меняется (dest — байт, кодек отсекает `>= Count`; старая прошивка прочтёт
новые dest как PITCH — только при откате). Универсальная матрица (смещение поля + диапазон) отвергнута:
параметры читаются во многих местах с учётом locks, понадобилась бы копия `Instrument` на голос.

Модулируются только непрерывные параметры, слышимые посреди ноты. ADSR-времена, sample start, glide —
нет (читаются на note-on).

## Цели (после DRIVE, по порядку)
| Dest | Типы | Полная глубина (depth ±63 ≈ ±1) |
|---|---|---|
| RESO | все | ±64 к 0..127 (после RES lock), clamp |
| FENV | все | ±64 к fenv (-64..63), clamp |
| DLY | все | ±64 к delay send (после DLY lock) |
| RVB | все | ±64 к reverb send (после RVB lock) |
| BIT | все | ±64 к crush bits (после BIT lock) |
| SRR | все | ±64 к crush rate (после SRR lock) |
| FINE | все | ±1 полутон |
| DUTY | CHIP | ±49 % ширины импульса |
| SUB | SYNTH | ±64 к synSub |
| NOISE | SYNTH | ±64 к synNoise |
| SEMI2 | SYNTH | ±24 полутона к osc 2 |
| L1..L4 RATE | все | частота цели × 2^(±4) (FREE и TEMPO) |
| L1..L4 DEPTH | все | глубина цели × clamp(1 + l, 0, 2), как VOL |
| L1..L4 RTRG | все | цикл источника (фаза через 1) сбрасывает фазу цели в 0 и даёт новое RND; важно лишь depth ≠ 0 |

Чужие типу цели энкодер Dest пропускает: `lfoDestStep(dest, d, type)` вместо флага `macros`
(DECAY..CONTOUR — FM / DRUM / SYNTH, DUTY — CHIP, SUB / NOISE / SEMI2 — SYNTH). LFO не выбирает
L-цели самого себя для RTRG (бессмысленно); RATE / DEPTH на себя — можно. `instrSetType` переводит
невалидный для нового типа dest в PITCH (обобщение нынешнего правила для макро).

## LFO на LFO
Голос хранит выходы своих LFO с прошлого control tick (`lfoOut[kLfos]`, -1..1 × depth/64). Rate- и
depth-модуляции считаются из них: задержка 1 мс, зато порядок не важен — циклы и самомодуляция по RATE
работают. Несколько источников на одну цель суммируются (RATE — сумма в октавах, DEPTH — сумма в
множителе до clamp). RTRG: флаги wrap источников этого tick применяются к целям.

Retrig OFF (общая фаза инструмента, `instLfoPhase_`):
- DEPTH-модуляция применяется к выходу — работает всегда.
- RATE и RTRG общей цели — только от общих (Retrig OFF) источников; считаются в `advanceInstLfos` по
  хранимым выходам инструмента (`instLfoOut_`). Per-voice источники для общей цели игнорируются (у
  голосов разные фазы).

## UI
Строка Dest та же. Имена: `RESO FENV DLY RVB BIT SRR FINE DUTY SUB NOISE SEMI2 L1 RATE .. L4 RATE
L1 DEPTH .. L4 DEPTH L1 RTRG .. L4 RTRG`; у SYNTH макро-имена свои (SHP1..SENV).

## Проверка
native: каждая новая цель двигает своё значение; L RATE меняет скорость цели; L DEPTH при -1 глушит
цель; RTRG сбрасывает фазу на wrap источника; общая цель игнорирует per-voice RATE / RTRG и принимает
общий; `lfoDestStep` пропускает чужие типу цели; `instrSetType` сбрасывает невалидный dest в PITCH;
кодек — round-trip новых dest. Мануал: таблица целей LFO, абзац про LFO на LFO. Железо: L2 RTRG от
медленного SAW, L1 RATE от второго LFO, DLY / RVB «качаются».

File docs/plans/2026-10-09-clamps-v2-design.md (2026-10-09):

# Клэмпы v2 — дизайн

## Цель
Заменить 2 длинные планки на 4 лапки, которые прижимают модуль WT32-SC01 Plus
за угловые цилиндрические бобышки на задней стороне. Верх корпуса не перепечатывать.

## Геометрия бобышек
- Центры: 6,52 мм от одного короткого края, 10,34 мм от другого (шаг 75,14),
  4,3 мм от длинных краёв (шаг 51,39).
- Торец бобышки — задняя плоскость модуля целиком: z = `mod_zb`.
- Диаметры не измерены: `boss_d = 6`, `boss_hole = 2.5` (переменные).
- Сторона 10,34 (Type-C модуля) в корпусе не задана: флаг `boss_flip` меняет отступы местами.

## Решение
- 4 лапки на существующих стойках (`clamp_xs × clamp_ys`), один винт M3 на лапку.
- Лапка = `hull` круга `post_r` вокруг винта и круга `boss_d/2` над бобышкой, толщина `clamp_t`.
- Сверху над бобышкой площадка высотой `foam_t` (вместо скотча) и штырёк `pin_d = 2`,
  `pin_h = 1.5` в отверстие бобышки — центрирует и не даёт лапке провернуться.
- `part = "clamp2"` — 4 лапки на одном столе, штырём вверх. Assembly показывает лапки
  вместо планок. Старый `part = "clamp"` остаётся.

## Документация
`stl/clamp2.stl`; README.md / README_ru.md — таблица печати, крепёж (скотч не нужен),
шаг сборки, команда рендера.

## Проверка
Рендер assembly и STL без ошибок; лапки не пересекаются с модулем и стенками.

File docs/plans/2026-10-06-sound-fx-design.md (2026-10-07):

# Sound fx: drive, reverb, master compressor, ARP modes, velocity — design

Block 4 of the roadmap agreed on 2026-10-06 (after 16 tracks, KIT drum track, song + live). Executed
**after** the SYNTH / wavetable work lands: it touches `synth.cpp`, `synth_voice.h`, `model.h`,
`inst_screen.cpp`, which that agent edits now.

## Goal

Make the INT mix sound finished without external gear: saturation per instrument, a reverb send next
to the delay, a master compressor that can duck to a drum track, a real arpeggiator and velocity that
shapes the sound, not only the level. Old projects and presets sound exactly as before.

## Model

- `LockBit`: `kLockFlt = 5, kLockRes, kLockDly, kLockDrv, kLockRvb, kLocks = 10`; `lockMask` in
  `Voice` and `Synth::TrackRt` becomes `uint16_t` (`static_assert(kLocks <= 16)`).
- `Fx`: `DRV` (drive lock 0..127), `RVB` (reverb send lock 0..127), `ARM` (arp mode, see below)
  appended before `Count`. All three synth-only (`fxSynthOnly`).
- `Instrument`: `drive` 0..127 (0 = bypass), `rsend` 0..127 (reverb send, 0 = none), `velCut`
  -64..63 (velocity → cutoff), `velMac` -64..63 (velocity → DECAY macro, FM / DRUM / SYNTH). All
  default 0.
- `LfoDest::Drive` appended before `Count`; UI name "DRIVE", available on every type.
- `Project`: `rvbSize = 60`, `rvbDamp = 70`, `rvbLevel = 80`; `compAmt = 0` (bypass), `compRel = 50`,
  `scTrack = 0` (off, 1..16 = track), `scDepth = 64`. All 0..127 except `scTrack` 0..kTracks.

## File format

- Instruments: the `FMIN` record (16 bytes, written for every instrument) has bytes 10..15 reserved
  (0): `b[10] = drive`, `b[11] = rsend`, `b[12] = velCut`, `b[13] = velMac` (signed as uint8). Old
  files read 0 = the new defaults; nothing else moves. Presets share the record (`inst_codec`):
  `kPresetVersion` 3 → 4 (newer readers accept older files, older firmware refuses the new ones).
- `AUDI`: 6 → 13 bytes, appended `rvbSize, rvbDamp, rvbLevel, compAmt, compRel, scTrack, scDepth`.
  `readAudi` reads what the chunk holds (6 = old file → defaults for the rest), clamps every value.
  `storage.cpp` snapshot copies the new fields.

## DSP

All at `kSynthRate` = 32 kHz, blocks of 128, control every 32 samples. Signal chain of a voice:
engine → **drive** → filter → (mix, delay send, reverb send, sidechain bus). Block end: delay return,
reverb return, **compressor**, master volume, soft clip.

### Drive (per voice, `synth_drive.h`)

`y = tanh(g x) / tanh(g)`, `g = 1 + drive / 127 * 7` (1..8). A 257-entry table of `tanh` over
[-8, 8] (`kDriveTab[i] = tanh(-8 + i / 16)`), linear interpolation, input clamped to ±8; `1 / tanh(g)`
is computed per control update, not per sample. Drive 0 (after lock and LFO) skips the stage: output
bit-exact to today. Cost ≈ 8 flops / sample / driven voice (~2 % with 16 voices all driven).
Applied in `renderVoice` to `dst` before the filter (the filtered path already renders into `flt[]`;
the unfiltered path renders into a scratch too when driven).

### Reverb (`synth_reverb.h/.cpp`, `mt::Reverb`)

Freeverb-lite, mono. 4 parallel feedback combs, base lengths 1116, 1188, 1277, 1356, actual length
`base * (0.5 + 0.5 * size / 127)` (clamped ≥ 1), feedback `0.70 + 0.28 * size / 127`, one-pole damping
in the loop `d = damp / 127 * 0.4` (`store = out * (1 - d) + store * d`); then 2 series allpasses 556,
441 with g = 0.5. Buffers: **float**, handed in by the caller (`setBuffer(float*, n)`), needed
`1116 + 1188 + 1277 + 1356 + 556 + 441 = 5934` floats = 23.2 KB (PSRAM on the device; no buffer =
silent). Float over int16: no scaling / conversion per tap, same memory traffic class, well under
64 KB. Rendered once per block from the `rsend_` bus: `mix += wet * (rvbLevel / 127 * 0.5)`. Cost per
sample ≈ 4 × 7 + 2 × 5 = 38 flops + 12 buffer accesses ≈ 3–5 % on one core (PSRAM latency dominates;
rings are read sequentially, the 32 KB cache holds them). Delay output does not feed the reverb.
`Synth::reset()` clears the buffer; a size change moves the write index (no glide).

### Compressor (`synth_comp.h`, `mt::Compressor`)

Peak detector on `|key|` with one-pole attack (1 ms) / release (`20 ms × 50^(compRel / 127)` =
20..1000 ms). Key = mix, plus `sc * scDepth / 127 * 4` when `scTrack` is set (`sc_` bus = the summed
voices of that track; the sidechain signal is weighted 4× so a drum track at normal level ducks hard
at depth 127). Threshold `T = -6 dB - 24 dB × compAmt / 127` (linear `exp2(dB / 6.02)`), ratio 4:1,
makeup `+(6 + 24 × compAmt / 127) / 2 / 2 dB` (half the threshold drop, then halved again for
headroom). Gain in dB `= -(envdB - TdB) × 0.75` above threshold, 0 below; computed **once per 8
samples** with `log2f` / `exp2f` and applied per sample (held, no ramp: 8 samples = 0.25 ms, inaudible
at these release times). `compAmt == 0` bypasses the stage bit-exactly. Cost < 1 %.

## Fx

- `DRV` 0..127, default 64: like FLT — on a step with a note the drive of its note-ons, else of the
  track's sounding voices. `RVB` 0..127, default 64: same for the reverb send.
- `ARM` "ARP MODE": `val = mode << 4 | rate`, mode 0 UP, 1 DOWN, 2 UPDOWN, 3 RANDOM, rate 1..8 notes
  per step; default `0x03` (UP, 3 = today's behaviour). Shown `U3`, `D4`, `B2`, `R8`. `fxStep` cycles
  the rate 1..8 then the mode. ARM alone does nothing; it shapes the next `ARP` of the step (same step
  or later steps while the ARP holds: ARM is stored in `TrackRt::arm` and reset with the ARP on a new
  step with a note).
- ARP today (`synth.cpp:516`): three pitches per step, offsets `0, x, y`, each a third of the step.
  With ARM: `n = rate` slots per step, offsets taken from the list `{0, x, y}` (or the chord, below):
  UP cycles forward, DOWN backward, UPDOWN forward then backward without repeating the ends, RANDOM
  picks per slot with the voice RNG. `ARP 00` keeps meaning off.
- **ARP + CHD** on the same step: the sequencer (`step_expand`) emits only the root note-on and a
  synth fx `kSynthArpChord = 0xF1 chord` before it (INT tracks only; MIDI tracks keep playing the full
  chord, they have no ARP). The synth stores the chord's intervals (`chordNotes` from `scale.h`, up to
  4 notes) in `TrackRt::arpNotes[4]` / `arpN` and the ARP cycles those instead of `{0, x, y}`; the
  ARP value is ignored except `00` = off (then the step is expanded as a normal chord).

## Velocity

- `velCut`: cutoff offset in octaves `= velCut / 64 × (vel - 64) / 64 × 6` (vel 64 = no change;
  +63 at vel 127 ≈ +6 octaves, like `fenv` at full depth). Added in `controlFilter` from
  `v.gain × 127` (the note's velocity, VSL excluded: use the velocity stored at note-on, `v.vel`).
- `velMac`: DECAY macro offset `= velMac × (vel - 64) / 64` in macro units (±63), clamped 0..127,
  applied where the macro value is read (`macros()` / the lock fallback) for FM, DRUM, SYNTH voices.
  Both 0 by default, so old projects are unchanged.

## UI

- INST MAIN (9 rows, fills `kListRows`): `… Glide, Send, Rvb send`. FILT page gets `Drive` as its
  first row (pre-filter in the chain; 8 rows). ENV page: `Attack, Decay, Sustain, Release, Vel>Cut,
  Vel>Dec` (`Vel>Dec` grey on CHIP / SAMPLE). LFO Dest gains `DRIVE` for every type.
- PROJ after `Dly level`: `Reverb` (size), `Rvb damp`, `Rvb level`, `Comp` (0 = OFF), `Comp rel`,
  `SC track` (OFF, T1..T16), `SC depth`.
- `fx_info`: `DRV "DRIVE"`, `RVB "REVERB SEND"`, `ARM "ARP MODE"`; `fxFormat(ARM)` = letter + rate.

## CPU

Estimates above: drive ≤ 2 % (all 16 voices driven), reverb 3–5 %, compressor < 1 %. The plan ends
with a bench (`AUDIO_BENCH_FX`) that reads the status-bar CPU figure with and without reverb /
compressor on the 16-voice DRUM bench; the executor writes the measured numbers here.

Measured: **not yet** (2026-10-06, no device in that session). Build `pio run -e wt32-fxbench -t upload`
(drive 100 + reverb send 100 on every bench instrument, reverb level 100, compressor 100 keyed by
track 1), read the status-bar CPU after 10 s, then set PROJ -> Rvb level 0 and Comp OFF and read it
again; fill in: DRUM bench baseline __ %, + drive + reverb __ %, + compressor __ %. Host-side, the
unit tests show drive 0 / Rvb send 0 / Comp OFF are bit-exact bypasses.

## Tests (native)

- Drive: table monotonic, `drive(x, 0) == x` bit-exact, drive 127 saturates (|y| ≤ 1, y(1) ≈ 1).
- Reverb: impulse → non-zero tail that decays below -60 dB within 3 s at size 60; silent without a
  buffer; size 127 tail longer than size 0; level 0 leaves the mix bit-exact.
- Compressor: gain 1 for a -20 dB sine at `compAmt 64`; a 0 dB sine reduced by the expected dB ± 1 dB
  after 50 ms; a loud `scTrack` voice ducks a quiet voice on another track; `compAmt 0` bit-exact.
- ARM: UP / DOWN / UPDOWN orders over one step at rate 4; RANDOM stays within the set; `ARP` without
  `ARM` unchanged (existing `test_synth` ARP tests pass untouched); ARP + CHD cycles the chord
  intervals and the sequencer emits one note-on; MIDI tracks still get the full chord.
- Velocity: vel 127 vs 64 moves the cutoff by `velCut / 64 × 6` octaves (check `flt` cutoff via a
  test hook or the rendered spectrum peak); velMac shifts the DECAY macro.
- Formats: project and preset round trips for every new field; a 6-byte AUDI and an old FMIN record
  give the defaults; out-of-range values clamp; `fxNextCmd` wraps `ARM → None`.

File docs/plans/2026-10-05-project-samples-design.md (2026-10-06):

# Сэмплы как часть проекта

## Задача

Сейчас флеш-банк — общий пул устройства: при загрузке любого проекта видны все когда-либо
импортированные сэмплы, а проект на SD не самодостаточен. Нужно: проект владеет своими сэмплами,
его можно перенести (SD / Wi-Fi) на другое устройство, и сэмплы подтянутся сами.

## Модель

- Флеш-банк — анонимный кэш по содержимому. Имя записи банка = CRC32 данных (int16 после
  конвертации), 8 hex-символов в существующем `name[16]`. Формат таблицы не меняется (v1, 128
  слотов). Одинаковые данные в разных проектах — одна запись; одноимённые разные сэмплы разных
  проектов не конфликтуют.
- `Project::samples[128]`: `{name[17], crc, frames}` + счётчик. `name` — видимое имя, на него
  ссылается `Instrument.sample`; уникально без учёта регистра в пределах проекта.
- `.mtp`: новый chunk `SMPL`. Файл без него читается (миграция ниже).
- Резолв: `SampleSource::find(name)` → элемент `live.samples` → `bank.find(hex crc)`, frames
  сверяются (см. «Конкурентность»).
- SD: `/projects/NAME.mtp` + `/projects/NAME/<sample>.wav` — mono, 16 bit, частота банка (на
  устройстве заливается без даунсемплинга). В WAV свой chunk `mtcr` с CRC данных; без него (файл с
  ПК) CRC считается по содержимому.
- `/samples/` остаётся библиотекой для импорта.

## Потоки

**Импорт WAV** (FILE → SAMPLES → Import): конвертация в банк как сейчас, CRC на лету. Если запись
с таким CRC уже есть — новая удаляется, берётся существующая. Запись переименовывается в hex CRC,
в `live.samples` добавляется элемент. SD не трогается — всё пишет save (работает и для нового
проекта без имени).

**Нехватка места** (импорт и загрузка): удалять записи банка, которых нет в `live.samples`, от
больших к меньшим, пока не влезет; если мешает фрагментация — `compact()`; иначе `BANK FULL`.

**Сохранение** (`storage::save`): `.mtp` как сейчас (tmp → проверка → .bak), затем синхронизация
`/projects/NAME/`: для каждого сэмпла списка без файла или с файлом другого CRC — записать WAV из
флеша (`data()`, mmap); файлы не из списка — удалить. Save as в новое имя пишет папку целиком.
Сэмпл missing (нет в банке) файл не перезаписывает и не удаляет.

**Загрузка** (`storage::load`, autoload): прочитать `.mtp`, остановить движок; для каждого сэмпла
— есть запись `crc` в банке → готово, иначе импорт из `/projects/NAME/<name>.wav` (с проверкой CRC).
Прогресс-бар: файл, байты. Нет файла / битый / CRC не совпал → missing (тишина), в конце тост
`N SAMPLES MISSING`; элемент остаётся в списке.

**Удаление сэмпла** — из списка проекта; банк не трогается, файл удалит следующий save.

**Rename** — только в проекте (+ ссылки инструментов), флеш не трогается.

## UI

- FILE → SAMPLES: список `live.samples` (имя, длина, метка `MISSING`); Import, Rename, Delete;
  строка `BANK: X KB free / cache Y`; Compact; `Clear cache` — удалить из банка всё, что не в
  текущем проекте.
- INST: выбор сэмпла только из `live.samples`.
- Импорт / rename / delete ставят dirty.

## Wi-Fi

Разрешены пути `/projects/<name>/<file>.wav` (upload / download / delete); на странице папка
проекта раскрывается рядом с `.mtp`. Перенос проекта — `.mtp` + WAV по одному. Zip не делаем.

## Миграция

`.mtp` без `SMPL`: список строится из `Instrument.sample` всех инструментов. Имя ищется сначала в
банке по старому имени — найденная запись переименовывается в hex CRC (CRC по данным во флеше), а
пара `имя crc frames` дописывается в `/projects/legacy.idx`; затем в `legacy.idx` (сэмпл уже
мигрировал из другого старого проекта). Не найдено — missing. Первый save пишет папку. Старые
записи, ни на что не сославшиеся, — обычный кэш (уйдут при вытеснении или `Clear cache`).

## Конкурентность

Синт ищет сэмпл только на note-on: имя → линейный поиск в `live.samples` → `bank.find(key)`.
Список меняется (импорт, rename, delete, загрузка) только при остановленном движке, как и банк
сейчас, — гонок нет, отдельная таблица резолва не нужна.

## Тесты (native, lib/core)

- `project_io`: round-trip `SMPL`; старый файл без chunk.
- Синхронизация списка с банком на RAM-флеше: попадание в кэш, импорт, вытеснение, дедуп по CRC,
  missing.
- CRC32 по кускам = CRC целиком.
- Резолв имя → индекс после rename / remove / compact.

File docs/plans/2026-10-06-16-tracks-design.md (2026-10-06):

# 16 tracks — design

## Goal

Double the track count from 8 to 16: one track per MIDI channel and per instrument, room for drums
without starving the melodic parts. Everything else (patterns, chain, fx, undo) keeps working; old
project files load as tracks 1–8 with tracks 9–16 at their defaults.

This is block 1 of the roadmap agreed on 2026-10-06 (blocks: 16 tracks; drum track / KIT; song + live;
sound; mixer + render). The drum track (block 2) builds on it.

## Model

- `kTracks = 16`. `Project::reset()`: track i gets channel i and instrument i (`model.cpp:51`) — the 16
  tracks, 16 MIDI channels and 16 instruments map one to one.
- `Pattern::steps[kTracks][kMaxSteps]`: 16 x 128 x 14 bytes = 28 KB, the project ≈ 460 KB (PSRAM,
  `main.cpp:36`).
- `Undo::kDepth` 32 → 8: snapshots are whole patterns, 8 x 28 KB ≈ 230 KB. Measure free PSRAM after the
  SYNTH / wavetable work lands (its mip tables may live there) before implementing; if short, drop to 4.

## File format

- `TRKS`, `TOUT` already carry a count byte: an 8-track file fills tracks 1–8, 9–16 keep the defaults
  (`readRecords` loops to `count`). Written files carry 16.
- `PATN`: the header stays 4 bytes (pattern, length, resolution, swing). Today the step size is derived
  from the body size assuming `kTracks` tracks (`project_io.cpp:241`); with 16 tracks an 8-track body no
  longer matches. The reader tries, in order, (tracks, step bytes) = (16, 14), (8, 14), (8, 6): the
  body sizes differ for any length (8 x 14 = 16 x 7 and 7 is not a step size), so the match is unique.
  Tracks beyond the file's count stay cleared. Writer: 16 tracks, 14-byte steps, as now.
- Files written by this firmware do not load on older firmware (PATN size mismatch → BadValue), same as
  earlier format bumps.
- MIDI import maps up to 16 MIDI tracks / channels (was 8); `import_dialog` lists 16 target tracks.

## Sequencer and synth

- All per-track loops and arrays are sized by `kTracks`. `kSynthTracks = kTracks + 1` (preview track
  = 16). Lookahead and tick cost double on core 0; it was far from the limit.
- Voices stay 16 (FM + DRUM ≤ 8), oldest-voice stealing as now. After measuring `CPU %` with 16 INT
  tracks decide separately whether to go to 24.

## GRID

- Overview shows 8 track columns (`kColW` 56 px). New state `half_` (0 = tracks 1–8, 1 = 9–16).
  The cursor moving to a track in the other half (encoder with Shift, track button, track name tap,
  `App` track change) switches `half_` and redraws. No other way to switch halves.
- Column headers show `T9…T16`; the status bar track field is two digits (`T12`).
- Detail view: one track, unchanged.
- Selection and Paste: the "not past track 8" clamps become 16 (`edit_ops`). A selection may span the
  halves; only the visible columns are drawn, the model is the full 16 columns.
- Track name tap: mute, Shift — solo, for the visible half.

## Track buttons

- Button N acts on track `half_ * 8 + N`: select (cursor), Shift + N mute, note entry in edit mode as
  now. The LED mask is built from the visible half (selected / mute). Switching the half (by scrolling)
  refreshes the LEDs. `trackio` stays an 8-button driver; the mapping lives in `App`.

## Other screens

- TRACK, INST (instrument assignment), BANK (Copy-to / Clear / Length act on whole patterns), Euclid and
  Transpose dialogs: track number is `kTracks`-bounded and printed with two digits where needed.

## Tests (native)

- `test_model`: `kTracks == 16`, reset defaults (channel i, instrument i for all 16).
- `test_project_io`: an 8-track file (both 6- and 14-byte steps) loads into tracks 1–8 with 9–16 at
  defaults; a 16-track round trip is bit-exact; a PATN body of a wrong size is `BadValue`.
- `test_midi_import` (or the existing import test): 12 channels land on 12 tracks.
- `test_expand` / `edit_ops`: paste reaching track 16, clamped at 16; selection spanning tracks 6–11.
- `test_sequencer`: notes on track 15 are scheduled; `test_synth`: preview track index 16.
- Euclid on track 15.

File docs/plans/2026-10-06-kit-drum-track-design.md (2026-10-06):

# KIT drum track — design

## Goal

A drum track: one track, eight lanes (kick, snare, hats…), an x-o-x grid instead of notes. Variant A of
the roadmap (block 2, after 16 tracks): a new instrument type **KIT** holds eight lanes; each lane is its
own mini sampler (a project sample, volume, pitch, decay) or, optionally, points at one of the 16
instruments. A track whose instrument is a KIT stores lane masks in its steps with no change to the
`Step` layout, so copy / paste / clear / selection / undo work unchanged. On MIDI tracks the lanes go
out as fixed notes (external drum machines); on INT tracks each lane plays mono with choke.

## Model

- `InstrType::Kit` appended before `Count`; `kTypeOrder` (UI order) gets Kit last.
- `constexpr int kKitLanes = 8;`

```cpp
// A KIT lane. instr == kNoInstr: a mini sampler on the project sample `sample` (empty / missing name =
// silent) played at its original pitch (root = note) + pitch semitones, vol, decay (0 = whole sample,
// else envTimeMs(decay) then silence). instr < kInstruments: the lane plays that instrument at `note`.
struct KitLane {
  char sample[kSampleNameMax + 1] = {0};
  uint8_t instr = kNoInstr;  // 0xFF
  uint8_t vol = 100;         // 0..127
  int8_t pitch = 0;          // -24..24 semitones
  uint8_t decay = 0;         // envTimeMs, 0 = play to the end
  uint8_t note = 60;         // MIDI note of the lane: unique in the kit, sent on MIDI tracks
};
```

  `constexpr uint8_t kNoInstr = 0xFF;` moves to `model.h` (it is `Synth::kNoInstr` today; keep the alias).
  `Instrument::kit[kKitLanes]` (8 x 22 = 176 bytes; `Instrument` grows from ~150 to ~330 bytes, x16 ≈ 5
  KB in the project — fine). `kitSetDefaults(m)`: every lane `KitLane()` with `note = 60 + k`. A KIT does
  not sound by itself: its Vol / ADSR / filter / LFO are unused; its `send` (and the reverb send once
  block 4 adds one) is the whole kit's delay send.
- `Project::trackIsDrum(t)`: `instruments[tracks[t].instr].type == Kit`, any `TrackOut`; `kitOf(t)`
  returns that instrument or `nullptr`.
- Drum-track step encoding, `Step` unchanged:
  - `note`: `kNoteEmpty` = empty step, `kNoteOff` = note off (releases every lane), else 0..127 = the
    step's velocity for all its lanes (0 = the track's `defVel`). `hasNote()` is still `note < 128`.
  - `vel`: 8-bit lane mask, bit k = lane k+1 hits. A note step with mask 0 plays nothing (fx still run).
  - A melodic track's steps never carry bit 7 in `vel`. Changing a track's instrument between KIT and
    non-KIT reinterprets its steps; accepted (the manual says so).
- `Fx::ACC` ("ACCENT") appended before `Count`, value 0..255 = lane mask: lanes in the mask play at
  the step velocity, the others at 60 %. Drum tracks only: `fxDrumOnly(Fx)`; elsewhere the slot is kept
  but ignored (drawn dim, like synth fx on MIDI tracks). `fxFormat` prints two hex digits.
- Every other fx applies to the step as a whole, i.e. to all its lanes' notes (RAT ratchets every lane,
  NDG nudges them, DEC / FLT / DLY lock every lane's voice, CND / PRB gate the step). CHD, NRN, STR, TIE,
  ARP, SLD, VIB, SLC are meaningless on a drum track and ignored by `expandStep` there.
- Lane note uniqueness: the UI step functions skip notes other lanes hold. Assigning a SAMPLE-type
  instrument to a lane sets the lane's `note` to that instrument's `root` (the sample keeps its pitch; if
  taken, the next free note up); other types leave `note` alone.
- Project sample rename (`projSampleRename`) renames the name in every KIT lane too, as it does in
  instruments' `sample`. Sample delete leaves the lane name (silent, like a MISSING instrument sample).

## File format

- `KITS` chunk: count byte, then 16 records of `kKitRecSize = kKitLanes * 22 = 176` bytes: per lane
  `sample[17]`, `instr`, `vol`, `pitch`, `decay`, `note`. Reader clamps: `instr` ≥ 16 → `kNoInstr`, `vol`
  → 0..127, `pitch` → -24..24, `note` ≥ 128 → 60 + k, the name NUL-terminated and validated like
  instrument sample names (`fixInstrument`). Older files: no chunk → `Instrument()` defaults (no
  instrument is Kit in them). Written after `SYNI`.
- `INST`: `type` byte already stored; `inst_codec` accepts the new value (`< InstrType::Count`).
- `PATN`: `readPatn` keeps the `vel` byte as is (no 0..127 clamp). Where the CRC chunk ends the file
  (after `fixInstrument`), `loadProject` masks `vel &= 0x7F` on every step of every non-drum track: the
  track's type is known only after `INST` / `TRKS` / `KITS`. Writer unchanged.
- Presets: no KIT presets in this block. `preset_browser` skips the Kit type when cycling types; Save
  on a KIT instrument toasts `NO KIT PRESETS`; `inst_codec` never packs a Kit.

## Expansion / sequencer

- `ExpandCtx` gets `const Instrument* kit = nullptr` (the track's KIT, or null). `Sequencer::expand`
  fills it from `p_.kitOf(track)`.
- `expandStep`, after the control events, on `kit != nullptr`: skips the melodic path. Lanes =
  `s.vel`; accent mask = `ACC` slot value or 0xFF. Base velocity = `s.note ? s.note : t.defVel`, plus
  VRN, clamped 1..127. For every set lane k: a NoteOn with `note = kit->kit[k].note`, `vel = accent ?
  base : base * 3 / 5` (min 1) at `nudge + sub * i` per ratchet i, followed by its NoteOff after
  `gateUs` (drums ignore it; MIDI drum machines want it). Lanes with no source still go out on MIDI
  (the synth is what is silent). TIE is ignored (`out.tie = false`). OFF works as on melodic tracks.
- `kMaxStepEvents` = 8 ratchets x 8 lanes x 2 + kFxSlots = 134 (was 72 + kFxSlots); `ExpandOut` grows by
  ~370 bytes (static in the sequencer, fine).
- MIDI tracks: the NoteOns go out on the track's channel (or CHN) — a GM drum map is lane notes 36, 38,
  42, 46, … set per lane in INST.

## Synth

- A voice refers to its instrument by index (`Voice::instr`, read as `p_.instruments[v.instr]` in
  `noteOn` and `control`). A sampler lane has no instrument of its own, so `Voice` gets a scratch
  `Instrument laneInst` and a flag `lane` (true = use `laneInst`); `Synth::instrOf(const Voice&)` returns
  `v.lane ? v.laneInst : p_.instruments[v.instr]` and replaces the two lookups. 16 voices x ~330 bytes
  ≈ 5.3 KB more internal RAM for `Synth` (it already holds the 16 voices; check the heap log).
- `Synth::noteOn(track, note, vel)`: `ii = trackInstr(track)`; if `instruments[ii].type == Kit`: find
  lane k with `kit[k].note == note` (first match); none → return. Then:
  - INST mode (`kit[k].instr < kInstruments`): `ii = kit[k].instr`, `m = instruments[ii]`; a Kit there
    → return (no nesting). Heavy (FM / DRUM) lanes count against `kFmVoiceMax` as usual.
  - SAMPLE mode: `laneInst = Instrument()` with `type = Sample`, `sample = lane.sample`, `root =
    lane.note`, `transpose = lane.pitch`, `start 0`, `end 0xFFFF`, `loop Off`, `sliceCount 0`, `reverse
    false`, `attack 0`, `decay = lane.decay ? lane.decay : 0`, `sustain = lane.decay ? 0 : 127`,
    `release` = the value whose `envTimeMs` ≈ 10 ms, `fltMode Off`, `lfoDepth 0`, `vol = lane.vol`,
    `send = kit.send`, `mono = true`. Built in a local, then the chosen voice's `laneInst` is copied from
    it and `v.lane = true`, `v.instr = ii` (the KIT's index, for the lock / p-lock lookups that key on
    the track). The sample is looked up by name in the bank as for a SAMPLE instrument; not found (empty
    or missing) → return (silent lane). Live lane edits apply on the next hit.
  - Voice choice (both modes): the lane is mono with choke regardless of `m.mono`: a sounding voice
    with `x.track == track && x.note == note` is reused (`legato = true`; the drum / FM / DRUM choke
    paths retrigger click-free; for sample / CHIP lanes `overlap` is forced false so the sample
    restarts), else `allocVoice(voices_, track, false, …, heavy, kKitLanes)` — a new last parameter
    `polyMax` (default `kPolyPerTrack`) so eight lanes can sound on one track. Sampler lanes count as
    SAMPLE voices (no heavy cap). The "a sample chokes the track's earlier samples" rule is skipped for
    lanes (they are independent).
  - `v.note = note` (the lane note) so note-offs and the next hit find the voice.
- `noteOff(track, note)` and `releaseTrack` work unchanged. Voices started from a lane keep playing
  from `laneInst` even if the lane is edited meanwhile.
- Preview (`audio::preview(instr, kPreviewNote = 60)`) on a KIT: the lane whose note is 60 — lane 1 by
  default. GRID lane toggles preview the toggled lane's note.

## GRID

- `GridScreen` helpers `drumAt(tr)` / `drum()` (= `trackIsDrum`), `padShown()`.
- Overview cell of a drum track (56 px column): no note name; 8 squares of 5 x 5 px at `x + 2 + k * 6`,
  `y + 5`, filled `kText` when bit k is set (dim when the track is not audible), outlined `kDim`
  otherwise; no velocity bar on drum tracks; `kNoteOff` draws `OFF` as now; the fx dot moves to `y + 1`.
- Detail view, drum track: the NOTE field draws the squares the same way with a `kEditCursor` frame on
  `lane_` while editing; the VEL field shows the step velocity from `note` (`...` for 0) and editing VEL
  edits `note` 1..127 (Shift x10); encoder turn on NOTE moves `lane_` 0..7, Shift + turn toggles the
  lane under the cursor.
- Lane pad replaces the mini keyboard on drum tracks (`edit_ && curField_ == kNote && drum()`): 8
  buttons `kScreenW / 8 = 60` px wide, `kKbH` high, label = first 4 chars of the lane's sample name
  (SAMPLE mode) or instrument name (INST mode), `-` when the lane has no sample; lit (`kPlayBg`) when the
  step has the lane. Tap toggles the lane: `vel ^= 1 << k`; an empty step gets `note = 0`; a mask that
  becomes 0 stays a note step (Clear step removes it). Writes through `writeStep` (undo), previews.
- Track buttons 1–8 in edit mode on a drum track toggle lanes 1–8 (no `enterDegree`); the cursor does
  not advance. Outside edit: select / mute as now.
- "Note OFF" menu items write `kNoteOff` as now. Copy / Paste between drum and melodic tracks is
  byte-wise and allowed (the manual warns).
- `editTurn` on NOTE for an empty drum step: creates `note = 0`, `vel = 1 << lane_`.

## INST

- Type list: `… / KIT` (last). KIT pages: MAIN (Name, Type, Send) and one scrolling LANES list
  (`ParamList` scrolls with `setVisibleRows(kListRows)`): per lane a header-like row `L<k> Src`
  (`SAMPLE` / `INST`), then in SAMPLE mode `Sample` (project sample picker — the same `Sample` row the
  SAMPLE type uses, with its `warn` for a missing name), `Vol`, `Pitch`, `Decay`, `Note`; in INST mode
  `Instr` (INS1..16, red when it is a KIT), `Note`. Rows of the other mode are hidden by rebuilding the
  list on a `Src` change (the `Param` array holds every row; a `dim`/skip set rebuilds via
  `syncParams`-like refresh). ENV, FILT, LFO pages are not shown for KIT.
- Choosing a SAMPLE-type instrument in `Instr` sets the lane's `Note` to that instrument's `root` (or
  the next free note up).
- PRESET button on a KIT: toast `NO KIT PRESETS`, the browser does not open; in the Load browser the
  type arrows skip KIT.

## Euclid / Transpose / Import

- Euclid dialog on a drum track: a `Lane` row (1–8) replaces Fill / Range / Seed; `applyEuclid` with
  `lane >= 0` writes hits as `vel |= 1 << lane`, `note = 0` when the step was empty (replace mode first
  clears the lane bit on every step of the track, not the other lanes); accents set `note = accentVel`
  only when `note` is still 0. `EuclidParams::lane` (int8, -1 = melodic).
- Transpose (dialog and menu): drum tracks are skipped; a selection spanning both kinds transposes
  the melodic tracks only; a drum-only selection or track toasts `DRUM TRACK` and does nothing.
- MIDI import onto a drum track: a note maps to the lane with that `note`; no lane → dropped (counted
  in `notesDropped`); several notes on one step OR into the mask; the step velocity is the first note's.
  The import dialog marks drum targets `T5*`.

## Tests (native)

- `test_model`: Kit defaults from `kitSetDefaults` (all lanes SAMPLE mode, empty name, vol 100, notes
  60..67); `trackIsDrum` / `kitOf`; `kTypeOrder` covers Kit; `sizeof(KitLane) == 22`.
- `test_project_io`: `KITS` round trip with a SAMPLE-mode lane (name, vol, pitch, decay) and an
  INST-mode lane; an older file (no `KITS`) loads defaults; garbage `instr` / `pitch` / `note` clamped;
  a drum track's `vel` 0xA5 survives the load, a melodic track's becomes 0x25.
- `test_sample_set`: `projSampleRename` renames the name in KIT lanes as well as instruments.
- `test_fx_info`: `ACC` name, range 0..255, hex format, `fxDrumOnly`.
- `test_expand`: mask → NoteOns with lane notes (every set lane, source or not), default / step
  velocity, `ACC` 60 %, RAT x 8 lanes = 128 events ≤ `kMaxStepEvents`, TIE ignored, OFF cuts.
- `test_synth`: a SAMPLE-mode lane builds the expected scratch instrument (`root = note`, `transpose =
  pitch`, `vol`, decay 0 → sustain 127, decay n → decay n / sustain 0, `send` = the kit's) and plays
  from the bank; a lane whose sample is missing is silent; an INST-mode lane plays the referenced
  instrument (voice `instr` = it); a second hit on a lane reuses its voice (choke); 8 lanes sound at once
  on one track; an unknown note is silent.
- `test_euclid`: lane writes only its bit; replace clears only its bit.
- `test_edit`: copy / paste of a drum step is byte-exact (`vel` 0xA5 kept); transpose skips drum tracks.
- `test_import`: notes → lanes by lane note, unknown note dropped.

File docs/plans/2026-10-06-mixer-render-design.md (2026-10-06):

# Mixer view, offline render (Render WAV, Resample) — design

## Goal

See and mix all tracks on one screen, and bounce the internal synth offline: a pattern or the whole
song to a WAV on the card, or a pattern straight into a project sample (resampling). Block 5 of the
roadmap of 2026-10-06; assumes blocks 1–4: `kTracks = 16`, KIT drum tracks, chain repeats /
transpose, master compressor / reverb / delay inside `Synth::render`.

## MIXER

Block 5 also adds the hold-button-and-turn volume gesture (below). A second view of the TRACK screen (as GRID has Overview / Detail): `TrackScreen::mixer_`.
Toggle: Shift + encoder click on TRACK (GRID toggles its view the same way, `grid_screen.cpp:257`),
Shift + tap on the TRACK tab (`App::onTouch`, tab row: a Shift-tap on the active TRACK tab calls
`track_.toggleMixer()` instead of `setTab`), and a `Mixer` / `Settings` item in a TRACK context menu
(long press). Settled by `mixer_` only; the parameter list is untouched.

Eight strips of the half holding the cursor (`firstTrack() = curTrack / 8 * 8`, exactly GRID's
rule; moving the cursor to the other half switches the strips) and a master strip at the right.
Strip = 52 px (`kStripW`, 8 x 52 = 416, left margin 8), master = 48 px (`kMasterW`) at x = 432,
separated by a 1 px `kDim` line. Top to bottom:

- name (8 chars), colours as GRID: solo = `kCursor`, audible = `kText`, muted = `kDim`; the selected
  strip has a `kCursor` frame;
- fader: `kFaderH` = 120 px tall, 12 px wide, filled from the bottom to `vol / 127`; value printed
  under it (`vol`); on a MIDI track the fader is drawn in `kDim`, the value field says `MIDI`, edits
  are ignored (velocity scaling is out of scope);
- `S nn` / `R nn`: delay send and reverb send (`Instrument::send`, `Instrument::rsend`) of the
  track's instrument, read-only here (edit in INST);
- `M` and `S` buttons (24 x 16), filled when on.

Master strip: label `MAIN`, the same fader for `Project::masterVol` 0..200 % (the device setting:
written to NVS by `App::saveVolumeIdle` as today; above 100 the fill turns `kCursor`), value `nn%`
under it, no sends, no M / S. The strip is "selected" when the cursor is on it: the master is
position 8 of the mixer cursor (`mixSel_` 0..7 = strips, 8 = master; track buttons and `setCurTrack`
land on 0..7). PROJ loses its `Volume` row (`proj_screen.cpp`): the mixer is the only place to set it;
the manual's PROJ / Volume text moves to the MIXER section.

Touch: Tap on the name selects the track (`App::setCurTrack`); Tap on `M` / `S` toggles
`TrackCfg::mute` / `solo`; `Drag` on a fader sets `vol` from the touch y (top = 127, bottom = 0;
`TouchEvent::y` of the current point, not dy, so the fader follows the finger; on the master the
drag sets `masterVol` 0..200). Encoder: turn = vol ±1 of the selected strip (Shift ±10; on the master
±1 / ±10 %), Shift + turn moves the mixer cursor across the 9 positions, Shift + click toggles the
view, click toggles mute (nothing on the master), long press = the context menu. Every write under `engine::lockProject()` + `markDirty()`; `vol` changes go to the
synth the same way the TRACK list does today (check how `kVol` edits are published — mirror it).
`wantsRedraw`: on mute / solo / vol / curTrack change (compare a small signature), not on play
position.

## Hold a track button + turn: track volume anywhere

Holding track button N (of the visible half) and turning the encoder changes that track's `vol`
±1 (Shift ±10) on every screen, with a toast `TRK5 VOL 100`; the turn is consumed (the screen under
it does not see it). The press itself still selects the track (Shift: mute) as before, so the gesture
adds to the existing behaviour. Not active while GRID is in edit mode (buttons enter notes / lanes)
or PERF is on (block 3); on a MIDI track the toast says `TRK5 MIDI` and nothing changes. Needs the
`TrackRelease` input event that block 3 adds (`trackio.cpp`); `App` keeps `heldTrackBtn_` (-1 = none)
and a `heldTurned_` flag so a press-and-release without a turn behaves exactly as today. Writes under
the project lock, published to the synth like the TRACK list's `kVol` edit, `markDirty()`.

## Offline render (core)

`lib/core/src/render.h/.cpp`, `mt::OfflineRender`. Works on the live `Project` (no copy: 460 KB) with
a `Sequencer` of its own (the live one runs on core 0 under the project mutex) and the live `Synth`
object handed in by the caller (see Memory).

```cpp
struct RenderSpec {
  enum class Mode : uint8_t { Pattern, Song } mode = Mode::Pattern;
  uint8_t pattern = 0;          // Mode::Pattern
  uint16_t tracksMask = 0xFFFF; // bit = track sounds (others muted for the render)
  uint32_t tailBlocks = 0;      // blocks after the end (delay / reverb ring-out), 2 s = 500
};
class OfflineRender {
 public:
  OfflineRender(Project& p, Synth& synth, const RenderSpec& spec);  // start() at t = 0
  bool renderBlock(int16_t out[Synth::kBlock]);  // false when done (nothing written)
  uint32_t blocksTotal() const;  // body + tail, known up front (progress)
  uint32_t blocksDone() const;
  int16_t peak() const;          // |max| so far
  uint32_t clips() const;        // samples at +-32767
};
```

- Time: block n starts at `blockT = n * kBlockUs` (4000 µs, 128 samples at 32 kHz); virtual clock, no
  `nowUs()`. The sequencer is driven with `seq.process(blockT + kBlockUs, sink)` once per block before
  the synth renders it — the live engine calls `process` at least `kLagUs` (6 ms) ahead of the block
  it renders, so every event of the block is scheduled by then. The sink drops MIDI (`send` = no-op);
  `synth(t, track, b, len)` calls `synth.event(eventOffset(t, blockT), track, b, len)` — the same
  `eventOffset` as `audio.cpp::drain` (late = 0, future = kept in a small FIFO for the next blocks; the
  FIFO is drained at the start of each block exactly like `drain`). Result: playback timing, minus the
  14 ms output latency.
- Length: analytic. `passUs(p, idx) = len * ticksPerStep(res) * 625000 / bpm`.
  `Mode::Pattern`: body = `passUs(pattern)`. `Mode::Song`: Σ over the chain of
  `passUs(chain[i]) * repeats(i)` (block 3's repeat count; 1 if the field is absent). `bodyBlocks =
  ceil(bodyUs / kBlockUs)`. After `bodyUs` the sink lets only note-offs / `OFF`-type messages through
  (held notes release, the next pass's lookahead note-ons never sound); notes nudged / swung past the
  pass end are cut — the same thing a live pattern switch does.
- Project mode flags: `Mode::Pattern` needs `songMode = false` and the pattern selected,
  `Mode::Song` needs `songMode = true`. The caller sets them on the live project before constructing
  the render and restores them afterwards (playback is stopped, the project is locked, the dirty flag
  is not touched: `OfflineRender::Guard` RAII in `render.h` does save / set / restore).
- `tracksMask`: new `Sequencer::setTrackMask(uint16_t)` (default `0xFFFF`) and a private
  `audible(tr) = p_.trackAudible(tr) && (mask_ >> tr & 1)` replacing the three `p_.trackAudible(tr)`
  calls in `sequencer.cpp` (`:378, :385, :498`). Per instance: the live sequencer is unaffected, no
  project copy, no mute flags written.
- Determinism: `seq.seed(0x5EED)` so two passes of the same render (resample measures first, writes
  second) are identical.
- CND first-pass rules: `start()` resets `loop_`, the pattern plays once as pass 1 — as live.

## Render WAV (FILE)

FILE menu gets `Render WAV...` (after `Import MIDI...`). Dialog (a `ParamList`, like the Euclid
dialog): `Source` = `PATTERN nn` (turn through 1..16, default = the current pattern) / `SONG` (only if
`chainLen > 0`); `Tracks` = `ALL` / `SOLOED` (`SOLOED` only if a solo is on: mask = the solo tracks);
`OK` / `CANCEL`. Needs playback stopped (`STOP FIRST` toast otherwise) and the card mounted.

Output: `/projects/<name>/render.wav` (SONG) or `/projects/<name>/pNN.wav` (NN = pattern 01..16),
mono 16-bit 32 kHz; the folder is the project's sample folder (created if absent, the project need not
be saved). If the file exists: confirm menu `OVERWRITE render.wav?`. Written via `.tmp` + rename like
`exportWav` (`bank.cpp`); the header (`wavHeader`, with the `mtcr` crc) is written last: the file is
opened, `kWavHeaderBytes` zeros written, blocks appended (`sampleCrc` running), then `seek(0)` and the
real header. Progress `RENDER nn%` through `App::showProgress`, cancel by long press (file deleted).
Done: toast `12.3s  PEAK -2.1dB` (peak = `20*log10(peak/32767)`; `CLIP n` appended when clips > 0).

## Resample (GRID)

Context menu items `Resample track` and `Resample pattern` (after `Euclid...`). Playback must be
stopped (`STOP FIRST`). Render = current pattern, `tailBlocks = 0`, `tracksMask` = the current
track, or the pattern's audible tracks (`trackAudible`), `Mode::Pattern`.

Two passes over the same deterministic render:
1. measure: peak, `lastLoud` = index of the last sample with |x| > -60 dBFS (33), frames = max(lastLoud
   + 1 rounded up to a block, 1 block);
2. write: `bankMakeRoom(frames)`, `bank.begin(kImportName, frames, 32000, 60)`, render again, each
   block scaled by `gain = 0.891 * 32767 / peak` (−1 dBFS; silence → gain 1) and written with
   `bank.write`, crc running; then the same rename-to-key / duplicate handling as `importToCache`
   (`bank.cpp:448-470`) — factor that tail into `finishImport(crc, frames)` and call it from both.

Project list: `projSampleSet(p, name, crc, frames)` with `name = nextResampleName(p)` = `RS1`, `RS2`…
(first n whose name is not in the list, case-insensitive). Toast `RS3 2.1s`. Cap:
`kResampleMaxFrames = 60 * 32000` — a pattern longer than 60 s stops there (`SAMPLE CAP` toast,
the sample is still added). The sample goes into the project's folder on the next Save like any
import. The user assigns it in INST → Sample.

## Memory & audio task

- The live `Synth` is reused: `audio::pauseForFlash()` parks the audio task (it already
  `synth->reset()`s and flushes the queues, `audio.cpp:park`), `audio::liveSynth()` (new accessor,
  valid only while parked) is passed to `OfflineRender`; afterwards `synth->reset()` again and
  `resumeAfterFlash()`. The delay line (256 KB PSRAM), the reverb and the compressor state are the
  live ones — reset clears them. `bank.cpp::FlashWork` already pairs pause / resume: expose it as
  `audio::Paused` (RAII) in `audio.h` and use it for both renders and the bank write.
- The render's `Sequencer` (`sizeof` ≈ heap of scheduled events + 32-step history; print it once in
  the boot log) lives in PSRAM, allocated for the render and freed after.
- Rendering runs on the UI core inside the FILE / GRID action, with the project locked
  (`engine::lockProject()`); the UI redraws only the progress. Speed: the synth at 50 % CPU renders
  2x realtime; a 60 s resample ≈ 60 s wall time for two passes — the progress bar covers both
  (`blocksTotal * 2`).
- The sequencer / synth `Project` references are the live project: nothing is copied.

## Errors

- Not stopped: `STOP FIRST`. No card: `NO SD CARD`. Folder / file open fails: `WRITE FAILED`; write
  short (card full): `DISK FULL`; the `.tmp` is removed in both cases.
- Resample: `BANK FULL` (`bankMakeRoom` false), `WRITE FAILED` (bank write), `SAMPLE CAP` (60 s cut).
- `pauseForFlash()` false (audio task did not park in 500 ms): `AUDIO BUSY`, nothing rendered.
- Cancel (long press during progress): file / bank entry removed, toast `CANCELLED`.

## Tests (native)

- `test_render`: pattern of 16 steps, one note at step 4 on track 0, INT CHIP: the first non-zero
  sample lands in the block of `4 * stepUs` (± 1 block), zero before; `tailBlocks = 0` →
  `blocksTotal == ceil(passUs / 4000)`; a note on track 1 with `tracksMask = 1` renders silence;
  `Mode::Song` with chain {0, 1, 0} (lengths 16 / 32, repeats 1 / 2 / 1) → `blocksTotal` = the sum;
  two renders are sample-identical (determinism); `peak()` and `clips()` on a loud block.
- `test_render` helpers: `normalizePeak(buf, n, peak)` → max |x| = 29204 (−1 dBFS), `trimTail` → last
  index above the threshold, never below one block; `nextResampleName` → `RS1`, then `RS2` when `rs1`
  exists.
- `test_wav`: a header written by `wavHeader(frames = 1000)` then 1000 int16 frames parses back with
  `wavParse` (frames, rate, root, crc).
- `test_sequencer`: `setTrackMask(1 << 3)` — only track 3's notes are scheduled; the default mask is
  all ones.

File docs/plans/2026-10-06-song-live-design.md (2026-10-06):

# Song structure and live performance — design

## Goal

Block 3 of the roadmap (after 16 tracks and the drum track). Two halves:

- **Song (A):** chain items carry transpose, repeat count and a mute scene; a track may have its own
  length inside a pattern (polymeter).
- **Live (B):** fill (conditional steps while a button is held), mute scenes, live recording from the
  track buttons, punch-in effects held on the track buttons.

Assumes block 1 (`kTracks = 16`, `App::trackKey(n)` maps button n onto the visible half) and block 2
(`Project::trackIsDrum(t)`; drum tracks are never transposed).

## Model

- `Project::chainTr[kChainMax]` int8 −24..24 (default 0), `chainRep[kChainMax]` uint8 1..16 (default 1),
  `chainScene[kChainMax]` uint8 0 = none, 1..8 (default 0). Parallel to `chain[]`; insert / delete rows
  move all four arrays together (`edit_ops` helper `chainInsert` / `chainDelete`).
- `Project::scenes[8]` uint16: bit t = track t muted; `kSceneEmpty = 0xFFFF` (all 16 muted is not a
  useful scene, so it marks "empty").
- `Pattern::trackLen[kTracks]` uint8: 0 = the pattern length, else 1..`length`. `sizeof(Pattern)` grows by
  16 (storage.cpp static_assert). Copied with the pattern (undo, Copy-to); `Clipboard` and Copy track
  ignore it. `Pattern::clear()` zeroes it; `isEmpty()` ignores it.
- CND gains two values: `kCndFill = 0x01` (FIL: only while fill is held) and `kCndNoFill = 0x02` (NFL:
  only while it is not). Both have a low nibble < 2, which no A:B value has (b = 2..8), and 0 stays FST.
- `ExpandCtx::fill` bool.
- Transient perf fx (not saved): `enum class PerfFx : uint8_t { None, Rat2, Rat4, FltLow, FltHigh,
  DlyMax, DecShort, Fade, Mute }` = buttons 1..8.

## File format

- `CHN2`: count, then per item `pattern, transpose (int8), repeat, scene` (4 bytes). Written instead of
  relying on the chain bytes inside `PROJ` (those are still written for old firmware; the loader applies
  `CHN2` after `PROJ` when present, else tr 0 / rep 1 / scene 0). Values clamped on load.
- `TLEN`: pattern index + 16 bytes, one chunk per stored pattern, written after its `PATN`; values
  clamped to 0..length. Old files: all 0.
- `SCNS`: 8 × uint16 LE. Old files: all `kSceneEmpty`.

## Sequencer

- Steps are expanded from a **working copy** of the step: `Step s = pat.steps[tr][idx]` then
  `adjustStep(s, tr)` adds the chain transpose to the note of a melodic track (clamped 0..127, `kNoteOff`
  / empty untouched) and writes the perf fx of the track into a slot (the first `None` slot, else slot
  `kFxSlots - 1`). `expandStep` is unchanged apart from the fill flag.
- Polymeter: `idx = pat.trackLen[tr] ? pos_ % pat.trackLen[tr] : pos_`. The pass counter (`loop_`, CND,
  the status bar) keeps following the pattern length.
- Repeat: `rep_` counts passes of the current item. `endOfPass()` in song mode: `if (++rep_ <
  chainRep[songPos_])` stay (like a repeated entry: ties and CND continue); else `rep_ = 0`, advance.
  `Sched` stores `rep` / `prevRep` so `rewind()` restores it. `chainEdited()` clamps `rep_`.
- Scene: when an item starts (`endOfPass` picks `next`, and `start()` at chain[0]) and `chainScene` is
  set, `applyScene()` writes `tracks[t].mute` from `scenes[scene - 1]` (skipped for an empty scene). Muted
  tracks get `pushOff` at that step so nothing hangs.
- Fill: `setFill(bool)`; `ExpandCtx::fill = fill_`. Steps already scheduled are not re-decided (≤ lookahead,
  ~1 step late at most).
- Perf: `perfOn(track, fx)` / `perfOff(track)` set `perf_[track]`. `Mute` makes the track inaudible in
  `scheduleStep` (and `pushOff` once); the others map to fx: Rat2 → `RAT 2`, Rat4 → `RAT 4`, FltLow →
  `FLT 30`, FltHigh → `FLT 120`, DlyMax → `DLY 127`, DecShort → `DEC 20`, Fade → `VSL -16`. On MIDI tracks
  only Rat2 / Rat4 / Fade (velocity) / Mute act; the synth-only fx are skipped (`fxSynthOnly`).
- Record position: `uint8_t phase256(uint64_t now) const` = position inside the heard step; `Status`
  carries it. `recordStepFor(pos, phase, len)` (pure, `lib/core/src/record.h`) = `phase < 128 ? pos :
  (pos + 1) % len`.

## UI

**BANK (chain).** Row text `P05 +3 x2 S1` (fields omitted when default). Encoder: click toggles row
edit as now; in row edit, **Shift + turn** moves between the fields pattern / transpose / repeat /
scene (the active field is drawn in `kCursor`), turn edits the field. Touch: tap the field. Row menu
unchanged. Under the chain list a row of 8 scene tiles `S1..S8` (filled = stored): tap = recall, long
press = store the current mutes, Shift + tap = clear. Recall / store go under the project lock and mark
dirty.

**GRID.** Context menu gains `Rec: ON/OFF` and `Perf: ON/OFF` (mutually exclusive with each other and
with edit mode: turning one on turns the others off). The title bar shows `REC` (red) or `PERF`
(yellow). Overview cells past a track's `trackLen` are drawn in `kDim` with a 1-px line at the boundary;
Detail draws the same line.

**TRACK.** New param `Pat len` (OFF / 1..length) editing `trackLen[curTrack]` of the edit pattern,
under the lock, with an undo snapshot. BANK `Length` clamps every `trackLen` to the new length.

**Status bar.** `FILL` while fill is held (replaces the `L` counter field while held).

## Controls

- **Fill:** Shift + Play is taken (pause / resume, `app.cpp:74`), so fill = **hold Shift + Play while
  playing**: fill starts on the press; on release, a hold shorter than `kLongPressMs` is a normal
  Shift + Play (pause), a longer one just ends the fill. `input` gains `PlayRelease`.
- **Track buttons** gain `TrackRelease` events (`trackio` already debounces a state mask; emit on 1→0).
- **REC armed and playing:** button N (no Shift) writes degree N (edit-mode octave logic) into the
  current track at `recordStepFor(...)`; Shift + N clears that step's note. One undo snapshot per pass
  (taken when `loopCount()` changes). Track selection while armed: tap the track name.
- **PERF on and playing:** `TrackPress` N → `perfOn(curTrack, N)`, `TrackRelease` N → `perfOff`. Shift +
  N keeps muting.

## Tests (native)

- `test_project_io`: `CHN2` / `TLEN` / `SCNS` round trips; old file → tr 0, rep 1, scene 0, trackLen 0,
  scenes empty; garbage clamped.
- `test_sequencer`: transpose applies to a melodic MIDI and INT track and not to a drum track; an item
  with rep 3 plays 3 passes before the next; `rewind` across the advance restores `rep_`; polymeter: a
  track with trackLen 3 in a 16-step pattern plays its step 0 at positions 0, 3, 6…; a scene item sets
  the mutes; fill on/off with FIL / NFL steps; perf Rat2 doubles the NoteOns, Mute silences, perfOff
  restores; `phase256` at the step start = 0, mid-step = 128.
- `test_expand`: `cndPasses` for FIL / NFL / FST / A:B; `fx_info` CND order and names.
- `test_edit`: `chainInsert` / `chainDelete` move all four arrays.
- `test_record`: `recordStepFor` rounding and wrap.

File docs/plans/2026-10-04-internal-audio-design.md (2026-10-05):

# Встроенный звук: chiptune и сэмплер — дизайн

Дата: 2026-10-04. Основа — [future-audio.md](future-audio.md) (вариант 1: звук на самом S3). Здесь — принятые решения.

## Решения

| Вопрос | Решение |
|---|---|
| Вывод | только встроенный усилитель NS4168 (разъём SPK), моно, без пайки |
| Движки v1 | chiptune + сэмплер |
| Привязка инструмента | на дорожку (`TrackCfg`), смена посреди паттерна — PGM |
| Полифония | общий пул 16 голосов; режим MONO / POLY (до 4) в инструменте |
| Сэмплы | банк в отдельном разделе flash (~9,9 МБ), импорт WAV с SD |
| Частота | 32 000 Гц; сэмплы хранятся с родной частотой ≤ 32 кГц |
| Эффекты | SLD, VIB, ARP, VSL, OFS, CUT |
| Волны chip | pulse, triangle, saw, noise, metal + 16 wavetable в прошивке |

## 1. Путь звука

- NS4168 на I2S0, GPIO 35/36/37 (BCLK / LRCK / DOUT — сверить со схемой платы на этапе 1). 32 кГц, 16 бит, одинаковый сигнал в L и R.
- Мост: оба вывода SPK под сигналом, ни один не GND. Наушники — только изолированное гнездо, через 100–220 Ом последовательно; не соединять с GND платы и с входами других устройств.
- Аудио-задача на ядре 0, приоритет ниже движка секвенсора. Блок 128 сэмплов (4 мс), DMA, буферы во внутренней RAM.
- Микшер: голоса × громкость инструмента × громкость дорожки × общая громкость, soft clip, моно.
- Громкость по умолчанию 40 %.

### Связь с секвенсором

- `Sequencer` отдаёт события в `MidiSink`. Маршрутизатор в `engine`: дорожка `Out::Midi` — в UART как сейчас; `Out::Int` — событие голоса с меткой времени (мкс таймера движка) в очередь синта.
- Секвенсор для INT-дорожек вместо MIDI-байтов шлёт `SynthEvent` (note on/off, параметры эффектов, PBN, PGM). Номер дорожки уже есть в `SchedEvent::track`.
- Синт ставит событие в блок с точностью до сэмпла: `offset = (t − tBlockStart) · 32000 / 1e6 + 1 блок`. Задержка постоянная ~8 мс, без джиттера. MIDI-дорожки её не имеют (компенсация — позже, если понадобится).

### Ядро (`lib/core`, native-тесты) и железо (`src/audio`)

- `lib/core`: генераторы, сэмплерный голос (линейная интерполяция, фиксированная точка 16.16 или 32.32), ADSR, распределитель голосов, эффекты, рендер блока, парсер WAV, аллокатор банка (над абстрактным интерфейсом flash).
- `src/audio`: I2S, задача, `esp_partition_mmap` банка, импорт с SD.

## 2. Инструменты и проект

16 инструментов в проекте.

Общие поля: имя (8), тип CHIP / SAMPLE, громкость, транспонирование (±24), подстройка (±50 центов), ADSR, MONO / POLY, время SLD по умолчанию (портаменто в MONO).

- CHIP: волна (pulse, triangle, saw, noise, metal, wt1–wt16), скважность pulse, PWM-свип (скорость, глубина).
- SAMPLE: имя сэмпла (16), корневая нота, start, end, loop (off / forward / ping-pong), loop start, reverse.

`TrackCfg`: `out` (MIDI / INT), `instr` 0..15, `vol` 0..127. Для INT: PGM меняет инструмент дорожки, CHN игнорируется.

`Project`: `masterVol`, `preview` (предпрослушка в GRID).

Файл: формат уже чанковый, неизвестные чанки пропускаются. Новые чанки `INST` (инструменты), `TOUT` (out/instr/vol дорожек), `AUDI` (masterVol, preview). Версия остаётся 1. Старые проекты — все дорожки MIDI.

Сэмпл не найден в банке: голос молчит, имя в INST красное. Ссылка по имени — после повторного импорта снова работает.

## 3. Банк сэмплов

Разделы (16 МБ): nvs, otadata — на прежних адресах (настройки Wi-Fi сохраняются); app0 / app1 по 3 МБ (OTA работает); `samples` ~9,9 МБ (~2,5 мин при 32 кГц). Новую таблицу заливать один раз по USB.

Формат раздела:
- сектор 0–1: заголовок (magic, версия) + таблица 128 записей: имя (16), смещение, длина в сэмплах, частота, корневая нота, loop по умолчанию, флаг занятости;
- данные: моно int16, начало каждого сэмпла выровнено по 4 КБ;
- выделение — первая подходящая дыра; удаление освобождает; «уплотнить» сдвигает данные к началу.

Чтение — `esp_partition_mmap` всего раздела (лимит окна MMU на S3 проверить на этапе 1).

Импорт WAV: PCM 8/16/24 бит, моно/стерео (сведение), любая частота; выше 32 кГц — понижение до 32 кГц, ниже — как есть. Только при остановленном воспроизведении (запись во flash останавливает кэш). Источник — `/samples` на SD; Wi-Fi-страница получает загрузку `.wav` до 4 МБ в `/samples`.

UI: вкладка FILE, раздел SAMPLES — список (имя, длительность, размер), полоса свободного места, «импорт из /samples», «удалить» (с подтверждением, если сэмпл используется), «уплотнить».

## 4. Интерфейс и эффекты

- Вкладки: GRID, TRACK, BANK, INST, PROJ, FILE (по 80 px).
- INST: выбор инструмента 1–16 и типа, список параметров (`ParamList`), для SAMPLE — вид волны с маркерами start / end / loop (двигаются энкодером), PREVIEW (C4).
- TRACK: поля OUT, INSTR, VOL; CHN / PRG / CCA / CCB серые на INT.
- GRID: на INT-дорожке ввод ноты (энкодер, кнопки дорожек) сразу звучит, если `preview` включён.
- PROJ: общая громкость, предпрослушка.

| fx | Значение | Действие |
|---|---|---|
| `SLD` | 1–255 | глайд от прошлой ноты дорожки к ноте шага (без ноты — к последней); время ≈ значение × 4 мс |
| `VIB` | `xy` | вибрато: x — скорость, y — глубина до ±1 тона |
| `ARP` | `xy` | нота, +x, +y по кругу, 3 переключения на шаг |
| `VSL` | −64…63 | изменение громкости за шаг, плавно |
| `OFS` | 0–255 | старт сэмпла с доли `value/256` длины (только SAMPLE) |
| `CUT` | 1–N | оборвать ноту через N тиков, без release |

На MIDI-дорожках новые fx игнорируются и показываются серыми. RAT, GAT, CHD, PRB, TIE, NDG, STR, CND — на обоих выходах; PBN — питч голоса (±2 полутона); PGM — инструмент; CCA, CCB, VRN, NRN, CHN — только MIDI. LED дорожек вспыхивают и на INT.

## 5. Этапы

1. Аудио-путь: таблица разделов, I2S, задача, тон, замер тактов, `mmap`, проверка щелчков при перерисовке.
2. Chiptune: голоса, ADSR, распределитель, wavetable, маршрутизатор, TRACK, чанки, вкладка INST (CHIP).
3. Эффекты на INT, предпрослушка.
4. Банк: формат, импорт WAV, FILE → SAMPLES.
5. Сэмплер: голос SAMPLE, loop, reverse, OFS, вид волны; загрузка `.wav` через Wi-Fi.
6. Документация: README, руководство, предупреждение про мост SPK.

## Тесты

Native (Unity): частота и форма генераторов, ADSR, распределитель (кража, mono legato), каждый fx, маршрутизатор (MIDI-дорожка не попадает в синт), чанки и совместимость со старыми файлами, парсер WAV (8/16/24 бит, стерео, лишние чанки), аллокатор банка (дыры, уплотнение — flash в RAM), рендер блока (событие на нужном сэмпле).

## Риски

- Реальная стоимость голоса: при нехватке CPU — меньше голосов или ниже частота. Решается замером на этапе 1.
  - Этап 1: замер ещё не сделан — нужен прибор. Как снять: добавить `-DAUDIO_BENCH` в `build_flags` `[env:wt32]`, прошить, в Serial раз в секунду `audio bench: render N us (peak M) / 4000 us` (16 голосов: float-фаза, линейная интерполяция из раздела `samples`, огибающая). Если 16 голосов > 60 % — пул 12 (`kVoices`). Без бенча нагрузка видна в PROJ (`CPU NN%`).
  - `mmap` всего раздела `samples` (~9,9 МБ): результат (`audio: samples mmap ok` / ошибка) печатается в Serial при старте — тоже ждёт прибора. При ошибке — окна по 4 МБ по требованию.
- Внутренний звук отстаёт от MIDI на ~8 мс.
- Во время импорта звука и воспроизведения нет.

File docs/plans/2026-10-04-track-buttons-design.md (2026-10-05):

# Кнопки дорожек со светодиодами — дизайн

Дата: 2026-10-04. Основа — [future-track-buttons.md](future-track-buttons.md); здесь — что добавлено и уточнено.

## Железо

- PCF8575 на `Wire` (I2C-порт 0; порт 1 занят тачем LovyanGFX): SDA GPIO 43, SCL GPIO 44 (TXD0/RXD0 разъёма Debug; GPIO 1/2/42 оказались заняты встроенным RS485), без INT — опрос каждые 5 мс, 400 кГц, адрес — первый ответивший из 0x20–0x27.
- P00–P07 — кнопки 1–8 на GND, читаются как 0.
- P10–P17 — светодиоды 1–8: 3,3 В → 330 Ом → анод, катод → P1x. Активный низкий: 0 = горит. PCF уверенно тянет вниз (до 25 мА), вверх — только слабая подтяжка, поэтому включение только по катоду. ~4 мА × 8 = 32 мА — в пределах чипа.
- LED 3 мм в штатном окне корпуса свича MX, колпачки прозрачные или с окном. Корпус не меняется.

## Прошивка

### Драйвер `src/hw/trackio.{h,cpp}`

- Задача FreeRTOS — единственный владелец `Wire`. Цикл 5 мс: при флаге INT или каждые 20 мс читает 2 байта; антидребезг 5 мс; на нажатие кладёт `InputEvent{TrackPress, delta = N, shift}` в очередь ввода `src/hw/input.cpp`.
- `hw::trackLeds(uint8_t mask)` (бит = горит) — атомарно; задача пишет порт при изменении: младший байт всегда 0xFF (кнопки остаются входами), старший — `~mask`.
- Нет ответа по I2C при старте — задача не запускается, остальное работает.

### Логика в `lib/core` (native-тесты)

- `scale.h`: `degreeNote(button, root, type, octave)` — кнопка 0..7 → MIDI-нота. Кнопки 1–7 — ступени I–VII, 8 — I + октава; лады короче 7 ступеней продолжаются в следующую октаву; Chromatic → мажор от тоники. Октава 4 = C4 = 60. Клип 0..127.
- `track_leds.h`: `trackLedMask(selected, flash)`. Активность — `Sequencer::takeActivity()` (дорожка в `SchedEvent::track`).

### Поведение

- Вне edit: N — выбрать дорожку N (общий курсор GRID/TRACK); Shift + N — mute дорожки N (на любом экране).
- В edit: N — ступень, Shift + N — ступень октавой выше. Запись в шаг под курсором с undo (как у энкодера), курсор на шаг вниз. Октава: нота под курсором → последняя введённая на этой дорожке → 4.
- OFF — как раньше, через контекстное меню.

### Светодиоды

- Движок на каждом note-on звучащей дорожки ставит бит в атомарной маске активности; UI забирает её (`engine::takeActivity()`) и держит вспышку 50 мс.
- Обычная дорожка: горит во время вспышки.
- Выбранная (курсор): горит постоянно, на вспышке гаснет (инверсия вместо тусклого ШИМ — ШИМ через I2C требует ~1 кГц записей).
- Заглушённая: не вспыхивает; выбранная заглушённая просто горит.

## Документация

README — пины и схема LED; `docs/manual.html` — раздел про кнопки; `enclosure/README.md` — LED в свичах; `future-track-buttons.md` — пометка «реализовано».

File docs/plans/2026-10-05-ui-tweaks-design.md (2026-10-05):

# UI tweaks: wrap-around, encoder selection, Transpose dialog, FX repeat

## 1. Wrap-around navigation
Selection in lists wraps (values still clamp):
- `Menu::move` — past the last item to the first, skipping disabled items.
- `ParamList` row selection (TRACK, INST, PROJ, Euclid, Import).
- `FileScreen` file list (`listSel_`) and sample list (`sampleMove`).
Name-edit text cursor stays clamped. GRID / BANK / keyboard / Wi-Fi / track & instrument switch already wrap.

## 2. Encoder selection (GRID)
- Step menu gets "Select": anchor = current cell.
- While a selection is on, every cursor move (turn, Shift+turn over tracks/fields) moves the selection end.
  Shift+tap uses the same state.
- Click while a selection is on drops it (no edit mode).
- Long press: selection menu — Copy sel, Paste, Clear sel, Note OFF sel, Transpose..., Undo, Clear selection.
- Copy drops the selection (move the cursor, Paste at the cursor). Clear / Note OFF / Transpose keep it.

## 3. Transpose dialog
`TransposeDialog` modelled on `EuclidDialog`: header CANCEL / OK, rows Amount, Mode, OK, Cancel.
- Scale: Amount ±2 octaves in degrees (`2 * scaleDegrees`), Shift = one octave of degrees.
- Chromatic: ±24 semitones, Shift = 12.
- Mode switch clamps Amount. OK applies to the selection, else the whole track, one undo step.
  Cancel / long press close without changes. Amount and Mode kept in RAM.
- Transpose +1 / -1 / +12 / -12 menu items removed.
- core: `scaleDegrees(ScaleType)` (notes per octave) with a unit test.

## 4. FX repeat
`lastFx_[track][slot]` (cmd + val) updated on every FX / VAL edit with cmd != None.
On an empty slot the first FX or VAL turn writes the remembered FX with its value; nothing remembered = old behaviour.

## Verification
`pio test -e native`, `pio run`. Manual updated.

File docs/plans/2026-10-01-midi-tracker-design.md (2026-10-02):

# MIDI-трекер на WT32-SC01 Plus — дизайн

Дата: 2026-10-01

## Цель

MIDI-секвенсор с трекерным интерфейсом на WT32-SC01 Plus: 8 MIDI-дорожек, длина паттерна 4–128 шагов (по умолчанию 16, общая для всех дорожек), MIDI OUT (миниджек TRS type A), энкодер, кнопки Play/Stop и Shift, тач. Сохранение/загрузка проектов на SD, импорт MIDI-файлов, генератор Euclidean-ритмов с ладом.

Решения, принятые на брейншторме:

- синхронизация: только мастер (внутренний темп, MIDI Clock + Start/Stop/Continue на выход), MIDI IN нет;
- банк из 16 паттернов с квантованным переключением, формат файла с заделом под song mode (chain);
- разрешение шага и swing задаются на паттерн; nudge — модификатор шага;
- дорожки монофонические, аккорды через модификатор `CHD`;
- импорт MIDI с полным экраном маппинга;
- глобальный лад проекта со scale lock;
- UI: LovyanGFX + собственный рендер (без LVGL).

## 1. Железо и распиновка

Плата: ESP32-S3 (WT32-S3-WROVER-N16R2: 16MB flash, 2MB PSRAM), дисплей 3.5" 480×320 ST7796 (шина 8080, 8 бит), тач FT6336U (I2C), microSD (SPI).

Разъём Extended IO (5V, GND, IO10–14, IO21):

| GPIO | Функция | Реализация |
|---|---|---|
| 10 | MIDI OUT | UART1 TX, 31250 бод |
| 11 | Энкодер A | PCNT (аппаратная квадратура) |
| 12 | Энкодер B | PCNT |
| 13 | Кнопка энкодера | вход, pull-up, дебаунс 5 мс |
| 14 | Play/Stop | вход, pull-up |
| 21 | Shift | вход, pull-up |

Кнопки замыкают на GND. Энкодер EC11, желательны конденсаторы 10 нФ на A/B.

MIDI OUT, TRS type A, 3.3 В:

```
+3.3V  ──[33 Ω]── Ring   (MIDI pin 4, source)
GPIO10 ──[10 Ω]── Tip    (MIDI pin 5, sink)
GND    ────────── Sleeve (MIDI pin 2, экран)
```

UART без инверсии. Опционально буфер 74HC14 (два инвертора последовательно).

Встроенная периферия: SD — CS 41, MOSI 40, CLK 39, MISO 38; тач — SDA 6, SCL 5, INT 7, RST 4 (общий с LCD).

Резерв: RS485 (GPIO 1, 2, 42), I2S-усилитель (GPIO 35, 36, 37) — например, под метроном.

## 2. Модель данных

**Шаг** (6 байт):
- `note`: 0–127, пусто, или `OFF` (явный note-off, обрывает `TIE`);
- `vel`: 1–127 или пусто (дефолт дорожки);
- `fx1`, `fx2`: команда (1 байт) + значение (1 байт).

**Паттерн** (×16): длина 4–128 (по умолчанию 16), разрешение (1/4, 1/8, 1/16, 1/32, 1/8T, 1/16T), swing 50–75%, 8 дорожек × 128 шагов. Весь банк ≈ 96 КБ в PSRAM.

**Дорожка** (на проект): имя, MIDI-канал 1–16, дефолтные velocity и gate, номера CC для слотов A/B, опциональный Program Change при старте, mute/solo (сохраняются).

**Проект**: имя, BPM 20–300, лад (тоника + тип: major, minor, dorian, phrygian, lydian, mixolydian, locrian, harmonic minor, melodic minor, pentatonic major/minor, blues, chromatic), 16 паттернов, chain[64] (зарезервировано под song mode).

**Модификаторы шага** (2 слота):

| Код | Значение | Действие |
|---|---|---|
| `CHN` | 1–16 | канал только для этого шага |
| `RAT` | 2–8 | ratchet: N повторов внутри шага |
| `PRB` | 0–100% | вероятность срабатывания |
| `GAT` | 1–800% | длина ноты в % шага |
| `TIE` | — | легато до следующей ноты, без ретригера |
| `NDG` | −50..+50% | микросдвиг во времени |
| `CHD` | тип | аккорд от ноты в ладу (triad, 7th, sus2, sus4, power, octave…) |
| `STR` | 1–50% | strum: разнос нот аккорда во времени |
| `CND` | A:B, `FST` | условие: играть на A-м проходе из B; `FST` — только первый проход |
| `VRN` | 0–64 | случайный разброс velocity ± |
| `NRN` | 1–7 | случайная нота ± N ступеней лада |
| `CCA`/`CCB` | 0–127 | CC (номер задан в дорожке) |
| `PBN` | −64..+63 | pitch bend |
| `PGM` | 0–127 | program change |

## 3. Движок секвенсора (ядро 0)

**Тайминг** — планировщик событий с абсолютным временем в мкс:
- в начале шага N просчитывается шаг N+1 целиком (lookahead нужен для отрицательного `NDG`): ноты, ratchet, strum, аккорды, note-off по gate, CC/PB/PGM;
- события кладутся в min-heap по времени;
- `gptimer` ставит alarm на ближайшее событие, ISR будит задачу с наивысшим приоритетом, она пишет байты в UART1;
- целевой джиттер < 100 мкс независимо от UI и SD.

**MIDI Clock** 24 PPQN — отдельный поток событий в том же планировщике.

**Транспорт:**
- Play: старт/стоп. Старт — `Start` (0xFA), clock с начала паттерна; стоп — `Stop` (0xFC), note-off всех нот, сброс в начало;
- Shift+Play: пауза/продолжение. Пауза — `Stop` + note-off; продолжение — `Song Position Pointer` + `Continue` (0xFB).

**Swing**: каждый чётный шаг задерживается на `(swing − 50) / 50 × длина шага`.

**Note-off**: таблица активных нот [канал][нота]; повтор той же ноты закрывает предыдущую; на стоп и смену паттерна закрываются все (`TIE` не переживает смену паттерна).

**Смена паттерна**: в очередь, применяется в конце прохода. Счётчик проходов на паттерн — для `CND`.

**Live-правки**: BPM, длина, swing применяются сразу (уменьшение длины заворачивает плейхед). Запись шага из UI — под коротким spinlock.

**Mute/solo** проверяются при просчёте шага; звучащие ноты не обрываются.

Running status не используется.

## 4. Интерфейс и управление

Экран 480×320, горизонтально.
- Верхняя строка: проект (`*` если не сохранён), паттерн (`P03→P05` при очереди), BPM, длина/разрешение, состояние транспорта, счётчик проходов.
- Нижняя строка: вкладки `GRID | TRACK | BANK | PROJ | FILE`, индикатор Shift.
- Сетка: 17 строк по 16 px, номера шагов, подсветка плейхеда, режим follow.

Виды сетки:
- **Overview** — 8 дорожек: нота, полоска velocity, маркеры наличия fx;
- **Detail** — 2 дорожки: `нота vel fx1 fx2`.

Энкодер:
- навигация: поворот — вверх/вниз; Shift+поворот — влево/вправо;
- нажатие — правка поля: поворот меняет значение (нота по ладу), Shift+поворот — грубо (октава / ×10); нажатие — выход;
- долгое нажатие (0.5 с) — контекстное меню (copy/paste/clear шага или дорожки, Euclid, транспонирование, настройки дорожки);
- Shift+нажатие — Overview ↔ Detail;
- Shift+долгое нажатие — undo (кольцевой буфер ~32 правок).

Тач:
- тап по ячейке — курсор; повторный тап — правка (значение энкодером);
- при правке ноты — мини-клавиатура на октаву с подсветкой нот лада;
- свайп — прокрутка;
- тап по заголовку дорожки — mute, Shift+тап — solo;
- Shift+тап по ячейке — выделение диапазона для блочных copy/paste/clear/transpose;
- тап по BPM/длине/swing в верхней строке — правка энкодером.

BANK: сетка 4×4. Тап — в очередь, Shift+тап — сразу, долгий тап — меню (copy в…, clear, длина/разрешение).

Play/Stop срабатывает по нажатию.

Остальные экраны — списки параметров: TRACK, PROJ, FILE, диалоги Euclid и импорта MIDI.

## 5. Хранение, импорт MIDI, Euclid

Структура SD:

```
/projects/*.mtp   проекты
/midi/*.mid       файлы для импорта
/last.txt         последний проект (грузится при старте)
```

Формат `.mtp` — бинарный чанковый: заголовок `MTRK` + версия; чанки `PROJ`, `TRKS`, `PATN` (только непустые паттерны, только `length` шагов), `CHAN`. Неизвестные чанки пропускаются. CRC32 в конце.

Запись: снапшот в PSRAM → `name.tmp` → проверка CRC → старый в `name.bak` → rename. Сохранение работает во время воспроизведения. Автосейва нет.

FILE: Save, Save As (экранная клавиатура), Load (подтверждение при несохранённом), New, Import MIDI.

Импорт MIDI (SMF 0/1, PPQ-деление; SMPTE → ошибка):
1. парсинг в PSRAM (лимит ~1 МБ), группировка нот по источнику (трек + канал);
2. экран маппинга: источник (имя, канал, число нот, диапазон) → дорожка 1–8 или skip; транспонирование ±24; смещение начала в тактах; разрешение квантования; моно-редукция (верхняя / нижняя / первая); опции «канал источника», «темп из файла», «сохранять микротайминг» (→ `NDG`);
3. длительность → `GAT`, если отличается от дефолта дорожки;
4. длинный материал режется на паттерны подряд от выбранного (до P16).

Euclid (на дорожку): hits, length (≤ длины паттерна, повторяется), rotation; заполнение нот root / up / down / up-down / random в ладу; базовая октава, диапазон; velocity + акцент; seed; replace или merge (только пустые шаги). Превью в сетке до OK, undo.

## 6. Структура кода, ошибки, тесты

Платформа: pioarduino (Arduino-ESP32 3.x / ESP-IDF 5, нужен `gptimer`). Плата `esp32-s3-devkitc-1` с переопределением под 16MB flash и PSRAM `qio_qspi`. Библиотеки: LovyanGFX, SD (SPI), PCNT из IDF.

```
lib/core/      model, scale, euclid, step_expand, project_io, smf_parser  (без железа)
src/hw/        display, touch, input, midi_uart, sdcard
src/engine/    scheduler, transport, clock
src/ui/        экраны и виджеты
src/main.cpp   инициализация, задачи по ядрам
```

Ядро 0 — движок; ядро 1 — UI, тач, энкодер, SD. Обмен: очередь команд UI → движок, снапшот состояния движок → UI.

Ошибки:
- нет SD — сообщение, секвенсор работает, FILE недоступен;
- битый CRC — ошибка и предложение загрузить `.bak`;
- ошибка записи — старый файл цел (запись через `.tmp`);
- неподдерживаемый/слишком большой MIDI-файл — сообщение, проект не меняется;
- лимит событий на шаг; лишние note-on отбрасываются, note-off — никогда;
- all notes off на стоп и смену паттерна;
- watchdog задач.

Тесты:
- `env:native` + Unity для `lib/core`: Euclid против эталонов (E(3,8), E(5,8)…), привязка к ладу, развёртка шага (ratchet, swing, nudge, strum, `PRB`/`NRN` с фиксированным seed, `CND`), round-trip и forward-compat формата, парсер SMF;
- на железе: MIDI-монитор на Mac через USB-MIDI, проверка джиттера; debug-режим дублирует MIDI-байты в USB-serial.

## Этапы

1. Железо: экран, тач, энкодер, кнопки, MIDI out «hello note».
2. Модель, движок, транспорт, MIDI clock, простая сетка.
3. Полный редактор: Overview/Detail, правка, модификаторы, undo, copy/paste.
4. Сохранение/загрузка.
5. Euclid и лад.
6. Импорт MIDI.
7. Song mode (позже).

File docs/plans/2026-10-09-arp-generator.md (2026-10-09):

# FILL: генератор арпеджио (ARP) — план реализации

> **For Claude:** REQUIRED SUB-SKILL: Use superpowers:executing-plans to implement this plan task-by-task.

**Goal:** В Fill-диалоге режим ARP: арп в духе Access Virus записывается нотами (note/vel + GAT,
TIE, SLD, NDG, RAT, PRB, CHD) на дорожку Dest; ~40 factory-паттернов, свои паттерны через Capture.

**Architecture:** Чистое ядро `lib/core/src/arp_gen.{h,cpp}` (паттерн, текстовый формат, factory,
`applyArp`, `captureArp`) с native-тестами `test/test_arp`. Хранение user-паттернов — текстовые
файлы `/presets/ARP/NAME.arp` (`src/storage/arp_store.*`). UI — первая строка `Type: FILL / ARP`
в `FillDialog`, общий preview/OK/Cancel/undo. Дизайн: `docs/plans/2026-10-09-arp-generator-design.md`.

**Tech Stack:** C++17, PlatformIO (`native` для тестов, `wt32` прошивка), Unity, LovyanGFX.

Команды:
- тесты ядра: `pio test -e native -f test_arp` (все: `pio test -e native`)
- прошивка: `pio run -e wt32`

---

## Формат паттерна (справка для всех задач)

Токены через пробел/перевод строки, один токен = шаг (до 32):
- первый символ: `x` нота, `X` акцент, `o` ghost, `.` пауза, `-` продление (tie)
- модификаторы ноты (любой порядок): `s` short, `l` long, `~` slide, `r` repeat (та же высота),
  `p` root (нижняя нота аккорда), `^` +12, `v` −12 (`r^` = та же нота октавой выше)
- неизвестный первый символ — токен пропускается.

Запись в Dest: GHOST = Vel Lo, NORM = середина, ACC = Vel Hi; GAT: NORM = Gate %, SHORT = Gate/2
(не меньше 5), LONG = 100 %, всё × Rate; slide: SLD на ноте + GAT 100×Rate+10 % у предыдущей
ноты; tie: TIE на предыдущей ноте, OFF на первой паузе после; свинг: NDG = Swing/2 на нечётных
шагах арпа; Ghost PRB < 100 — PRB на ghost-нотах; Roll % — RAT 2..4.

---

### Task 1: Паттерн и текстовый формат

**Files:**
- Create: `lib/core/src/arp_gen.h`
- Create: `lib/core/src/arp_gen.cpp`
- Test: `test/test_arp/test_arp.cpp`

**Step 1: Failing test**

```cpp
#include <string.h>
#include <unity.h>
#include "arp_gen.h"
#include "model.h"

using namespace mt;

void setUp() {}
void tearDown() {}

void test_parse_tokens() {
  ArpPattern p;
  TEST_ASSERT_TRUE(parseArpPattern("Xs~ xl o xr^ xpv . - ?z x", p));
  TEST_ASSERT_EQUAL(8, p.len);  // "?z" skipped
  TEST_ASSERT_EQUAL(ArpKind::Note, p.steps[0].kind);
  TEST_ASSERT_EQUAL(ArpAcc::Accent, p.steps[0].acc);
  TEST_ASSERT_EQUAL(ArpLen::Short, p.steps[0].len);
  TEST_ASSERT_TRUE(p.steps[0].slide);
  TEST_ASSERT_EQUAL(ArpLen::Long, p.steps[1].len);
  TEST_ASSERT_EQUAL(ArpAcc::Ghost, p.steps[2].acc);
  TEST_ASSERT_EQUAL(ArpPitch::Repeat, p.steps[3].pitch);
  TEST_ASSERT_EQUAL(1, p.steps[3].oct);
  TEST_ASSERT_EQUAL(ArpPitch::Root, p.steps[4].pitch);
  TEST_ASSERT_EQUAL(-1, p.steps[4].oct);
  TEST_ASSERT_EQUAL(ArpKind::Rest, p.steps[5].kind);
  TEST_ASSERT_EQUAL(ArpKind::Tie, p.steps[6].kind);
  TEST_ASSERT_FALSE(parseArpPattern("  ", p));
}

void test_format_round_trip() {
  ArpPattern p, q;
  TEST_ASSERT_TRUE(parseArpPattern("Xs~ xl o xr^ xpv . -", p));
  char buf[256];
  TEST_ASSERT_TRUE(formatArpPattern(p, buf, sizeof(buf)));
  TEST_ASSERT_EQUAL_STRING("Xs~ xl o xr^ xpv . -", buf);
  TEST_ASSERT_TRUE(parseArpPattern(buf, q));
  TEST_ASSERT_EQUAL(0, memcmp(&p, &q, sizeof(p)));
  TEST_ASSERT_FALSE(formatArpPattern(p, buf, 4));
}

void test_parse_caps_at_32() {
  char text[200] = "";
  for (int i = 0; i < 40; ++i) strcat(text, "x ");
  ArpPattern p;
  TEST_ASSERT_TRUE(parseArpPattern(text, p));
  TEST_ASSERT_EQUAL(kArpPatMax, p.len);
}

int main() {
  UNITY_BEGIN();
  RUN_TEST(test_parse_tokens);
  RUN_TEST(test_format_round_trip);
  RUN_TEST(test_parse_caps_at_32);
  return UNITY_END();
}
```

`memcmp` по `ArpPattern` требует, чтобы `ArpStep` не имел мусора в паддинге и неиспользуемые шаги
были одинаковы: `parseArpPattern` сначала делает `out = ArpPattern{}`.

**Step 2:** `pio test -e native -f test_arp` — FAIL (нет `arp_gen.h`).

**Step 3: Implementation**

`lib/core/src/arp_gen.h`:

```cpp
#pragma once
#include <stdint.h>
#include "edit_ops.h"
#include "model.h"
#include "scale.h"

namespace mt {

// Arp generator of FILL: a rhythm pattern (factory or user) run over held notes, written as notes
// and fx on one track. Text form of a pattern, one token per step: 'x' note, 'X' accent, 'o' ghost,
// '.' rest, '-' tie (the previous note holds); after a note: 's' short, 'l' long, '~' slide,
// 'r' repeat the previous note, 'p' the lowest held note, '^' +12, 'v' -12.
constexpr int kArpPatMax = 32;

enum class ArpKind : uint8_t { Rest, Note, Tie };
enum class ArpAcc : uint8_t { Ghost, Norm, Accent };
enum class ArpLen : uint8_t { Short, Norm, Long };
enum class ArpPitch : uint8_t { Next, Repeat, Root };

struct ArpStep {
  ArpKind kind = ArpKind::Rest;
  ArpAcc acc = ArpAcc::Norm;
  ArpLen len = ArpLen::Norm;
  ArpPitch pitch = ArpPitch::Next;
  int8_t oct = 0;  // -1, 0, +1
  bool slide = false;
};

struct ArpPattern {
  uint8_t len = 0;
  ArpStep steps[kArpPatMax];
};

// False when the text has no step. Steps past kArpPatMax are ignored.
bool parseArpPattern(const char* text, ArpPattern& out);
// Canonical text (tokens joined by ' '). False when cap is too small.
bool formatArpPattern(const ArpPattern& p, char* out, int cap);

}  // namespace mt
```

`lib/core/src/arp_gen.cpp`:

```cpp
#include "arp_gen.h"

namespace mt {
namespace {

bool blank(char c) { return c == ' ' || c == '\t' || c == '\n' || c == '\r' || c == ','; }

}  // namespace

bool parseArpPattern(const char* text, ArpPattern& out) {
  out = ArpPattern{};
  const char* p = text;
  while (*p && out.len < kArpPatMax) {
    while (*p && blank(*p)) ++p;
    if (!*p) break;
    ArpStep a;
    const char c = *p++;
    switch (c) {
      case 'x': a.kind = ArpKind::Note; break;
      case 'X': a.kind = ArpKind::Note; a.acc = ArpAcc::Accent; break;
      case 'o': a.kind = ArpKind::Note; a.acc = ArpAcc::Ghost; break;
      case '.': break;
      case '-': a.kind = ArpKind::Tie; break;
      default:
        while (*p && !blank(*p)) ++p;
        continue;
    }
    for (; *p && !blank(*p); ++p) {
      switch (*p) {
        case 's': a.len = ArpLen::Short; break;
        case 'l': a.len = ArpLen::Long; break;
        case '~': a.slide = true; break;
        case 'r': a.pitch = ArpPitch::Repeat; break;
        case 'p': a.pitch = ArpPitch::Root; break;
        case '^': a.oct = 1; break;
        case 'v': a.oct = -1; break;
        default: break;
      }
    }
    out.steps[out.len++] = a;
  }
  return out.len > 0;
}

bool formatArpPattern(const ArpPattern& p, char* out, int cap) {
  int n = 0;
  auto put = [&](char c) {
    if (n + 1 >= cap) return false;
    out[n++] = c;
    return true;
  };
  for (int i = 0; i < p.len && i < kArpPatMax; ++i) {
    const ArpStep& a = p.steps[i];
    if (i > 0 && !put(' ')) return false;
    if (a.kind == ArpKind::Rest) {
      if (!put('.')) return false;
      continue;
    }
    if (a.kind == ArpKind::Tie) {
      if (!put('-')) return false;
      continue;
    }
    if (!put(a.acc == ArpAcc::Accent ? 'X' : (a.acc == ArpAcc::Ghost ? 'o' : 'x'))) return false;
    if (a.len == ArpLen::Short && !put('s')) return false;
    if (a.len == ArpLen::Long && !put('l')) return false;
    if (a.slide && !put('~')) return false;
    if (a.pitch == ArpPitch::Repeat && !put('r')) return false;
    if (a.pitch == ArpPitch::Root && !put('p')) return false;
    if (a.oct > 0 && !put('^')) return false;
    if (a.oct < 0 && !put('v')) return false;
  }
  if (cap < 1) return false;
  out[n] = '\0';
  return true;
}

}  // namespace mt
```

Порядок модификаторов при форматировании: длина, slide, высота, октава — тест ждёт `Xs~`,
`xr^`, `xpv`.

**Step 4:** `pio test -e native -f test_arp` — PASS.

**Step 5:**
```bash
git add lib/core/src/arp_gen.h lib/core/src/arp_gen.cpp test/test_arp/test_arp.cpp
git commit -m "feat(arp): arp pattern model and text format"
```

---
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

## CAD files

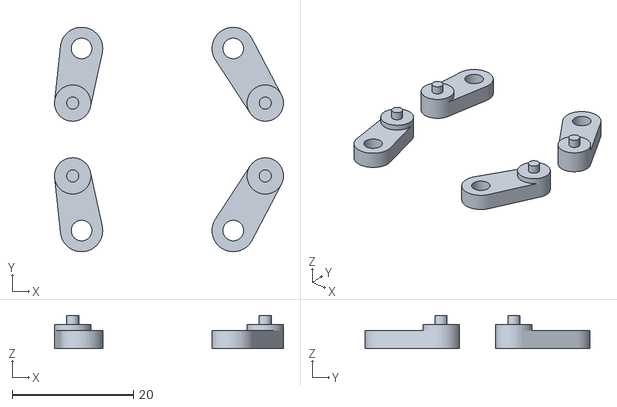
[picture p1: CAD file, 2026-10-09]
enclosure/stl/clamp2.stl
37.7 x 37.0 x 5.50

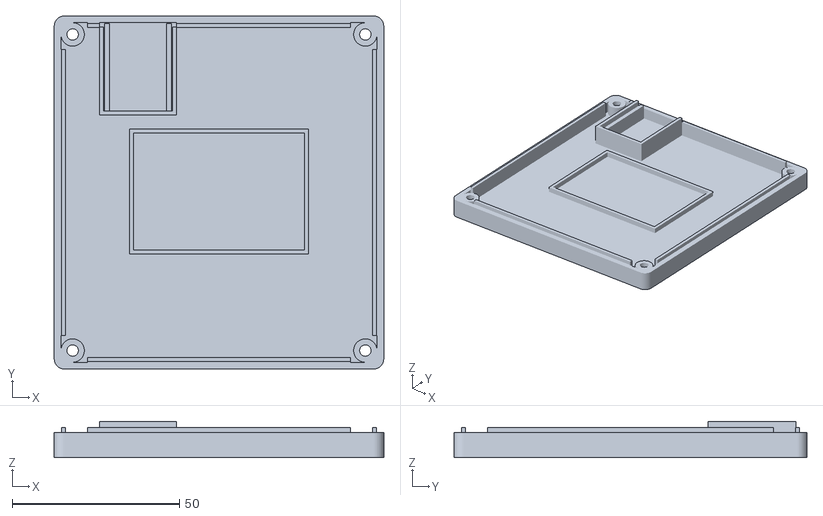
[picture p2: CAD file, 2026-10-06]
enclosure/stl/case_bottom.stl
98.4 x 105.4 x 10.8

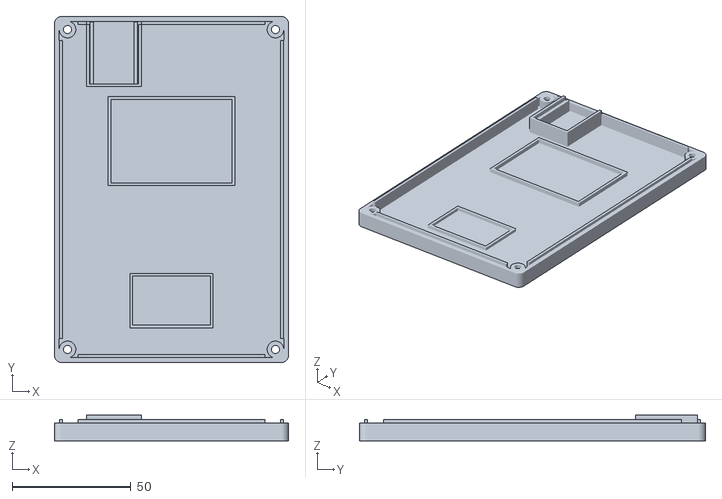
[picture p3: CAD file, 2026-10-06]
enclosure/stl/case8_bottom.stl
98.4 x 145.4 x 10.8

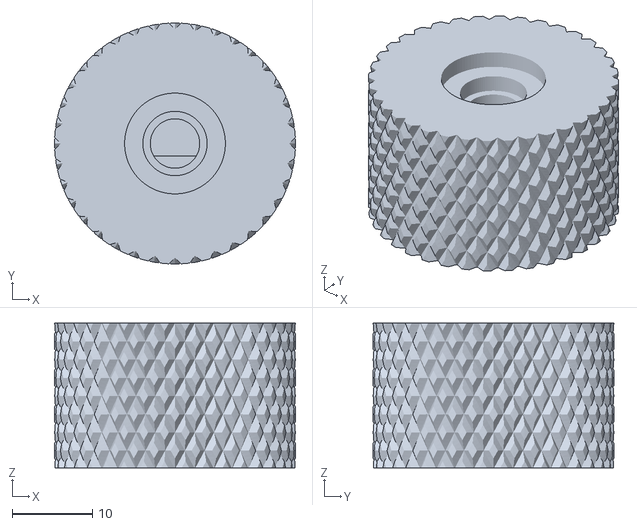
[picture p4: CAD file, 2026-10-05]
enclosure/stl/knob.stl
30.0 x 30.0 x 18.0

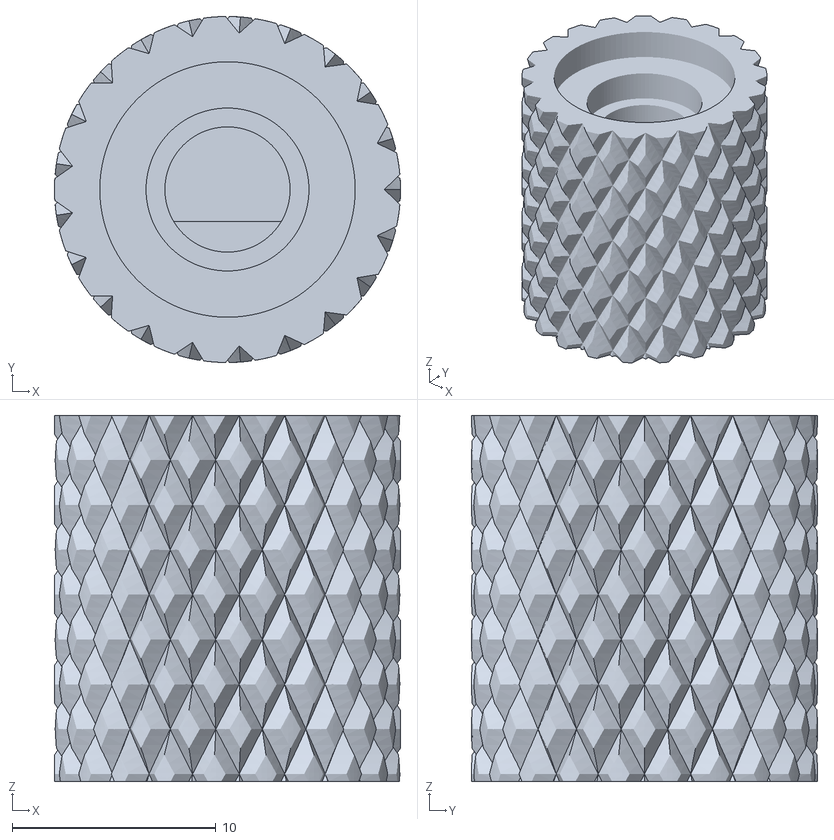
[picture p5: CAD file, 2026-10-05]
enclosure/stl/knob8.stl
17.0 x 17.0 x 18.0

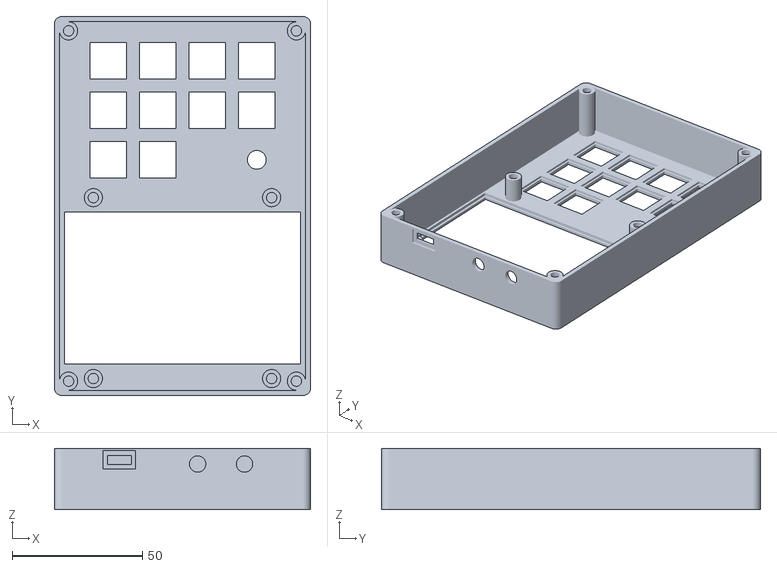
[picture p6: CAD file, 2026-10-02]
enclosure/stl/case8_top.stl
98.4 x 145.4 x 23.5

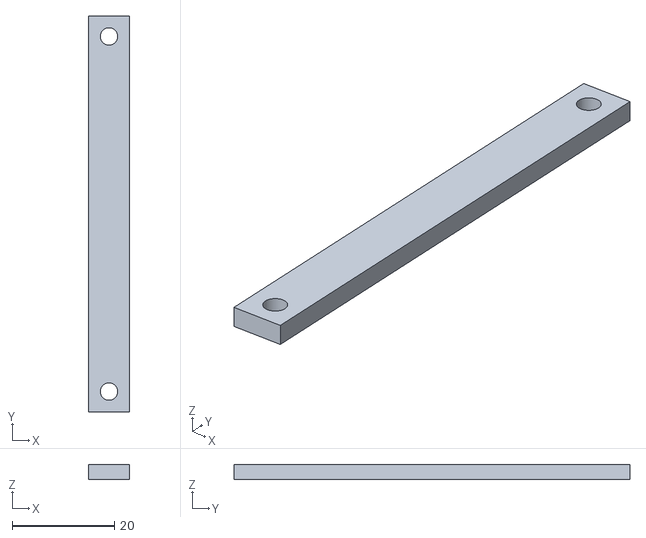
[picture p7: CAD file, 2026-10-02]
enclosure/stl/clamp.stl
8.00 x 77.4 x 3.00

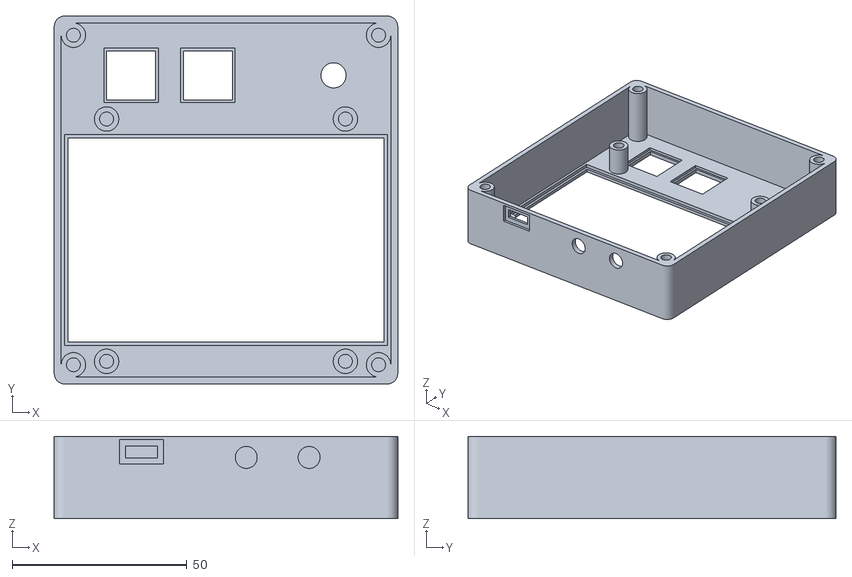
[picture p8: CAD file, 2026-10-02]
enclosure/stl/case_top.stl
98.4 x 105.4 x 23.5

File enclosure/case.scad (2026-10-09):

// SPDX-FileCopyrightText: 2026 deemonoise
// SPDX-License-Identifier: CERN-OHL-S-2.0
// Source location: https://github.com/deemonoise/D-TRK
// Корпус D-TRK (WT32-SC01 Plus). Все размеры в мм.
// Деталь: part = "top" | "bottom" | "clamp" | "clamp2" | "assembly"
// Рендер: openscad -o case_top.stl -D 'part="top"' case.scad
// Вариант с 8 кнопками дорожек: -D 'trk=true'

part = "assembly";
trk  = false;     // блок 8 кнопок дорожек (2 ряда × 4 MX) + расширитель PCF8575

$fn = 48;

// ---------- Замерить перед печатью ----------
// Модуль WT32-SC01 Plus (стекло + рамка + плата)
mod_w   = 92.0;   // по X (длинная сторона)
mod_d   = 60.0;   // по Y
mod_h   = 10.8;   // полная толщина
mod_clr = 0.2;    // зазор кармана на сторону

// Бортик над краем рамки
lip   = 1.0;      // ширина нахлёста на рамку
lip_t = 1.2;      // толщина бортика (глубина утопления модуля)

// Аккумулятор 103450
bat_w = 50; bat_d = 34; bat_h = 10;
bat_clr = 0.5;        // зазор в бортике
bat_gap = 1.5;        // от аккумулятора до низа модуля (скотч + запас)

// Модуль зарядки IP5306 (Type-C вход, USB-A выпаян)
ip_w = 20; ip_d = 26; ip_pcb = 1.2;  // ширина вдоль стенки, глубина внутрь
ip_rail = 1.5;        // высота подставки под платой
usbc_w = 9.2; usbc_h = 3.4;          // гнездо Type-C
usbc_plug_w = 12.5; usbc_plug_h = 7.0; usbc_plug_depth = 1.0; // раззенковка под штекер
ip_x = 25;            // центр по X

// Панельные компоненты задней стенки
jack_d   = 6.3;  jack_x = 55;   // PJ-392, резьба M6
sw_d     = 6.3;  sw_x   = 73;   // MTS-102, резьба M6
back_z   = 9;                   // высота осей jack и тумблера над низом

// Органы управления
mx_hole   = 14.0;   // вырез MX
mx_plate  = 1.5;    // толщина панели под защёлки MX
mx_pocket = 15.6;   // карман снизу вокруг выреза
ec11_d    = 7.2;    // отверстие EC11
sh_x = 22; pl_x = 44; enc_x = 80;   // центры по X (без кнопок дорожек)
ctrl_y = 17;                       // центр ряда по Y (без кнопок дорожек)
// С кнопками дорожек ряд Shift, Play, энкодер встаёт в их сетку над ними:
// Shift — колонка 1, Play — колонка 2, энкодер — колонка 4.

// Кнопки дорожек (trk = true)
trk_cols = 4; trk_rows = 2;
trk_pitch = 19;                    // шаг MX
trk_y0 = 17;                       // центр переднего ряда по Y (второй — +trk_pitch)
pcf_w = 32; pcf_d = 20;            // модуль PCF8575 (замерить)
pcf_y = 26;                        // центр модуля по Y

// Крепёж: вплавляемые гайки M3
ins_d     = 4.0;    // отверстие под гайку
ins_depth = 6.0;
post_r    = 3.5;
screw_d   = 3.4;    // проход M3
cb_d      = 6.2;    // цековка под голову M3 DIN 912 (⌀5,5 × 3)
cb_h      = 3.2;    // голова заподлицо; винты крышки M3 × 10

// Прижимные планки
clamp_w   = 8;
clamp_t   = 3;
foam_t    = 1.0;    // пористый скотч между планкой и модулем
clamp_dx  = 12;     // от края модуля по X до оси планки
// Бобышки на задней стороне модуля (клэмпы v2)
boss_x0 = 10.34;   // центр от левого края модуля, смотря на экран (правый, смотря на плату)
boss_x1 = 6.52;    // центр от правого края, смотря на экран
boss_y  = 4.3;     // центр от длинных краёв
boss_d  = 6.0;     // наружный диаметр (не замерен)
boss_hole = 2.5;   // отверстие (не замерено)
boss_flip = false; // true — модуль развёрнут на 180° в плоскости экрана
pin_d = 2.0; pin_h = 1.5;   // штырёк лапки в отверстие бобышки

// Корпус
wall   = 2.0;
top_t  = 2.5;
lid_t  = 3.0;       // дно нижней части
tray_h = 4.5;       // высота стенок корыта (аккумулятор ниже на столько же)
guide_t = 1.2;      // центрирующая губа по кромке корыта: толщина,
guide_h = 1.5;      //   высота,
guide_clr = 0.2;    //   зазор к внутренней стенке верха
corner_r = 3.0;
side_m = 1.0;       // зазор модуль — стенка по бокам
ctrl_d = trk ? 72 : 32;   // глубина переднего отсека (органы управления)
back_m = 9;         // полоса за модулем

// ---------- Производные ----------
pk_w = mod_w + 2*mod_clr;
pk_d = mod_d + 2*mod_clr;

W = pk_w + 2*side_m + 2*wall;
D = wall + ctrl_d + pk_d + back_m + wall;
H = lid_t + bat_h + bat_gap + mod_h + lip_t;

mod_x0 = wall + side_m;
mod_y0 = wall + ctrl_d;
mod_x1 = mod_x0 + pk_w;
mod_y1 = mod_y0 + pk_d;
mod_zb = H - lip_t - mod_h;           // низ модуля

clamp_zt = mod_zb - foam_t;           // верх планки = низ стоек планок
clamp_xs = [mod_x0 + clamp_dx, mod_x1 - clamp_dx];
clamp_ys = [mod_y0 - post_r - 1, mod_y1 + post_r + 1];
boss_xs = [mod_x0 + mod_clr + (boss_flip ? boss_x1 : boss_x0),
           mod_x1 - mod_clr - (boss_flip ? boss_x0 : boss_x1)];
boss_ys = [mod_y0 + mod_clr + boss_y, mod_y1 - mod_clr - boss_y];

lid_posts = [[wall + post_r, wall + post_r], [W - wall - post_r, wall + post_r],
             [wall + post_r, D - wall - post_r], [W - wall - post_r, D - wall - post_r]];

ip_zc = lid_t + ip_rail + ip_pcb + usbc_h/2;   // ось Type-C

// Нижняя часть строится вниз от z = lid_t (стык с верхом), верх не зависит от tray_h
bot_z0 = lid_t - tray_h - lid_t;      // низ дна
floor_z = lid_t - tray_h;             // верх дна

echo(str("Корпус: ", W, " x ", D, " x ", H + tray_h, " мм"));
echo(str("Под MX до дна: ", H - mx_plate - floor_z, " мм"));

// центры MX: Shift, Play и (trk) 8 кнопок дорожек; кнопка 1 — левая в ряду ближе к экрану
function trk_cx(c) = W/2 + (c - (trk_cols - 1)/2) * trk_pitch;
row_y  = trk ? trk_y0 + trk_rows * trk_pitch : ctrl_y;
shift_x = trk ? trk_cx(0) : sh_x;
play_x  = trk ? trk_cx(1) : pl_x;
encod_x = trk ? trk_cx(trk_cols - 1) : enc_x;

mx_pos = concat([[shift_x, row_y], [play_x, row_y]],
    trk ? [for (r = [trk_rows - 1 : -1 : 0], c = [0 : trk_cols - 1])
              [trk_cx(c), trk_y0 + r * trk_pitch]] : []);

// ---------- Утилиты ----------
module rbox(w, d, h, r) {
    linear_extrude(h) offset(r) offset(-r) square([w, d]);
}

// ---------- Верх ----------
module top_shell() {
    difference() {
        union() {
            difference() {
                translate([0, 0, lid_t]) rbox(W, D, H - lid_t, corner_r);
                translate([wall, wall, lid_t - 0.01])
                    rbox(W - 2*wall, D - 2*wall, H - lid_t - top_t + 0.01, max(corner_r - wall, 0.5));
            }
            // угловые стойки под винты крышки
            for (p = lid_posts) translate([p[0], p[1], lid_t]) {
                cylinder(r = post_r, h = H - lid_t - top_t + 0.01);
                // стыковка со стенками угла
                translate([p[0] < W/2 ? -post_r - 0.5 : 0, p[1] < D/2 ? -post_r - 0.5 : 0, 0])
                    cube([post_r + 0.5, post_r + 0.5, H - lid_t - top_t + 0.01]);
            }
            // стойки прижимных планок
            for (x = clamp_xs, y = clamp_ys) translate([x, y, clamp_zt])
                cylinder(r = post_r, h = H - top_t - clamp_zt + 0.01);
        }
        // окно экрана и карман модуля
        translate([mod_x0 + lip, mod_y0 + lip, H - top_t - 1])
            cube([pk_w - 2*lip, pk_d - 2*lip, top_t + 2]);
        translate([mod_x0, mod_y0, mod_zb - 1])
            cube([pk_w, pk_d, H - lip_t - mod_zb + 1]);
        // MX
        for (p = mx_pos) {
            translate([p[0] - mx_hole/2, p[1] - mx_hole/2, H - top_t - 1])
                cube([mx_hole, mx_hole, top_t + 2]);
            translate([p[0] - mx_pocket/2, p[1] - mx_pocket/2, H - top_t - 1])
                cube([mx_pocket, mx_pocket, top_t - mx_plate + 1]);
        }
        // EC11
        translate([encod_x, row_y, H - top_t - 1]) cylinder(d = ec11_d, h = top_t + 2);
        // гайки в стойках
        for (p = lid_posts) translate([p[0], p[1], lid_t - 0.01]) cylinder(d = ins_d, h = ins_depth);
        for (x = clamp_xs, y = clamp_ys) translate([x, y, clamp_zt - 0.01]) cylinder(d = ins_d, h = ins_depth);
        // задняя стенка: Type-C
        translate([ip_x, D - wall/2, ip_zc]) {
            cube([usbc_w, wall + 2, usbc_h], center = true);
            translate([0, wall/2 - usbc_plug_depth/2 + 0.01, 0])
                cube([usbc_plug_w, usbc_plug_depth + 0.02, usbc_plug_h], center = true);
        }
        // jack и тумблер
        for (h = [[jack_x, jack_d], [sw_x, sw_d]])
            translate([h[0], D + 1, back_z]) rotate([90, 0, 0]) cylinder(d = h[1], h = wall + 2);
    }
}

// ---------- Низ ----------
module fence(w, d, h, t = 1.2) {
    difference() {
        translate([-t, -t, 0]) cube([w + 2*t, d + 2*t, h]);
        translate([0, 0, -1]) cube([w, d, h + 2]);
    }
}
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

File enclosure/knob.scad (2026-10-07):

// SPDX-FileCopyrightText: 2026 deemonoise
// SPDX-License-Identifier: CERN-OHL-S-2.0
// Source location: https://github.com/deemonoise/D-TRK
// Кноб энкодера EC11 (D-вал) с накаткой. Все размеры в мм.
// Снизу выборка под гайку и резьбовую втулку — низ кноба висит над панелью на `gap`.
// Рендер: openscad -o stl/knob.stl knob.scad   (печать верхом на стол, без поддержек)
// Корпус с кнопками дорожек: openscad -o stl/knob8.stl -D knob_d=17 knob.scad
// (энкодер в сетке MX с шагом 19: до колпачка 18 мм под ним остаётся 1,5 мм)

part = "print";   // "print" — для печати, "view" — как стоит на панели

$fn = 96;

// ---------- Кноб ----------
knob_d   = 30;      // 17 — для корпуса с кнопками дорожек
knurl_n  = round(PI * knob_d / 2.6);   // канавок в каждую сторону (шаг ~2,6)
knurl_dp = 0.8;     // глубина канавки
knurl_top = 0.4;    // ширина площадки ромба / шаг
knurl_ang = 30;     // угол винтовой канавки к оси
skin     = 1.5;     // толщина крышки над концом вала

// ---------- Энкодер (замерить) ----------
shaft_d   = 6.0;    // ⌀ вала
shaft_dd  = 4.5;    // D-вал: от лыски до противоположной стороны
flat_l    = 10;     // длина лыски от конца вала
shaft_clr = 0.15;   // зазор посадки (на диаметр); туго — увеличить
shaft_l   = 20;     // от опорной плоскости корпуса энкодера до конца вала
bush_d    = 7;      // резьбовая втулка M7
bush_l    = 7;      // высота втулки от опорной плоскости
nut_af    = 10;     // гайка под ключ
nut_h     = 2.0;
washer_t  = 0.5;    // шайба (0 — без шайбы)
panel_t   = 2.5;    // толщина панели (top_t в case.scad)
push      = 0.5;    // ход кнопки энкодера

gap = push + 0.5;   // зазор низ кноба — панель (в нажатом положении остаётся 0,5)

// ---------- Производные (z от верха панели) ----------
bush_top  = bush_l - panel_t;
nut_top   = washer_t + nut_h;
shaft_top = shaft_l - panel_t;
knob_h    = shaft_top - gap + skin;

nut_cav_d  = nut_af / cos(30) + 1.0;   // по углам гайки + запас
nut_cav_h  = nut_top + 0.5 - gap;
bush_cav_d = bush_d + 1.0;
bush_cav_h = bush_top + 0.5 - gap;
bore_h     = knob_h - skin;

echo(str("Кноб: ⌀", knob_d, " x ", knob_h, " мм, зазор до панели ", gap,
         " мм, вал в кнобе ", bore_h - bush_cav_h, " мм"));
assert(bore_h - bush_cav_h >= 5, "вал заходит в кноб меньше 5 мм");
assert((knob_d - nut_cav_d) / 2 - knurl_dp >= 1.2, "стенка у гайки тоньше 1,2 мм");

// ---------- Модель ----------
module d_profile(d, dd) {
    intersection() {
        circle(d = d);
        translate([-d/2, -d/2]) square([d, dd]);   // лыска сверху по +Y
    }
}

knurl_p = PI * knob_d / knurl_n;                         // шаг по окружности
knurl_tw = knob_h * tan(knurl_ang) / (knob_d/2) * 180 / PI;  // закрутка за высоту, °

// круг с V-канавками по окружности
module knurl_2d() {
    w = knurl_p * (1 - knurl_top);     // ширина канавки на поверхности
    r = knob_d / 2;
    k = (knurl_dp + 0.5) / knurl_dp;   // продлить стенки V за пределы круга
    difference() {
        circle(d = knob_d);
        for (i = [0 : knurl_n - 1]) rotate(i * 360 / knurl_n)
            polygon([[r - knurl_dp, 0], [r + 0.5, -w/2 * k], [r + 0.5, w/2 * k]]);
    }
}

module knob() {
    difference() {
        // две встречные винтовые накатки — пересечение даёт ромбы
        intersection() {
            linear_extrude(knob_h, twist =  knurl_tw, slices = 40) knurl_2d();
            linear_extrude(knob_h, twist = -knurl_tw, slices = 40) knurl_2d();
        }
        // выборки снизу: гайка, втулка
        translate([0, 0, -0.01]) cylinder(d = nut_cav_d, h = nut_cav_h + 0.01);
        translate([0, 0, -0.01]) cylinder(d = bush_cav_d, h = bush_cav_h + 0.01);
        // вал: круглая часть, выше — D
        translate([0, 0, -0.01]) cylinder(d = shaft_d + shaft_clr, h = bore_h - flat_l + 0.01);
        translate([0, 0, bore_h - flat_l - 0.01])
            linear_extrude(flat_l + 0.01) d_profile(shaft_d + shaft_clr, shaft_dd + shaft_clr);
    }
}

if (part == "print") translate([0, 0, knob_h]) rotate([180, 0, 0]) knob();
else {
    // панель и энкодер для проверки
    color("gray") translate([-25, -25, -panel_t]) difference() {
        cube([50, 50, panel_t]);
        translate([25, 25, -1]) cylinder(d = 7.2, h = panel_t + 2);
    }
    color("silver") {
        cylinder(d = nut_af / cos(30), h = nut_top, $fn = 6);
        translate([0, 0, -panel_t]) cylinder(d = bush_d, h = bush_l);
        translate([0, 0, -panel_t]) cylinder(d = shaft_d, h = shaft_l);
    }
    color("orange", 0.6) translate([0, 0, gap]) knob();
}

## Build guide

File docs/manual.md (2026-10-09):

# D-TRK — user manual

A tracker with a built-in synthesizer on the WT32-SC01 Plus: 16 tracks, a bank of 16 patterns, a song chain, Fill with Euclid and an arpeggio generator, MIDI file import. Each track plays either the built-in synthesizer (FM, 808 / 909 drum machines, a wavetable synth, a sampler, chiptune) through the board's speaker, or external MIDI. Controls: a touchscreen, an encoder and two buttons, Play and Shift.

Русская версия: [manual_ru.md](manual_ru.md)

1. [Quick start](#start)
2. [Controls](#hw)
3. [Screen and status bar](#screen)
4. [GRID: pattern editor](#grid)
5. [Effects (fx)](#fx)
6. [Fill, Euclid and arp](#euclid)
7. [TRACK: track settings](#track)
8. [INST: instruments](#inst)
9. [PROJ: project and pattern](#proj)
10. [BANK: pattern bank](#bank)
11. [Song mode](#song)
12. [FILE: saving and loading](#file)
13. [MIDI import](#import)
14. [MIDI output](#midi)
15. [Built-in sound](#sound)
16. [Limits](#limits)

## Quick start

1.  Insert a microSD card formatted **FAT32** with an **MBR** partition scheme and power on the device. Without a card, a demo beat loads on tracks 1–3.
2.  Press <kbd>Play</kbd>. The sequencer sends MIDI Start and plays from the first step. Press again to stop.
3.  In the **GRID** tab, tap a cell, then tap it again to enter edit mode. Press keys on the mini keyboard at the bottom or turn the encoder.
4.  In the **FILE** tab, choose **Save As…**, enter a name and press OK. The project loads automatically at the next power-on.

## Controls

| Action | What it does |
|---|---|
| <kbd>Play</kbd> | Start from the first step / stop. When paused, also restarts from the beginning. |
| <kbd>Shift</kbd>+<kbd>Play</kbd> | Pause and resume: stopped → start, playing → pause, paused → resume from the same spot. During playback, pause triggers on releasing Play if it was held for less than 0.5 s. |
| <kbd>Shift</kbd>+<kbd>Play</kbd>, hold | During playback: **fill** while Play is held (steps with [CND FIL](#cnd) play, steps with NFL don't). Releasing after 0.5 s only ends the fill, without pausing. |
| <kbd>Shift</kbd> | A modifier; does nothing on its own. While held, a yellow `SHIFT` replaces the FILE tab. |
| Encoder turn | Moves the cursor or selects a row. In edit mode, changes the value. With Shift, a coarse step (usually ×10). |
| Encoder click | Enter or leave edit mode, choose a menu item. |
| Encoder long press | 0.5 s: context menu or close a dialog. |
| Tap | Select. Tapping the selected item again enters edit mode. |
| Long tap | 0.5 s: context menu. |
| Drag | Scroll. In edit mode, changes the value: up increases, down decreases. |

Play works on any screen, even over an open menu.

### Track buttons

In GRID the buttons also record notes live (REC) and hold effects (PERF) — see [REC and PERF](#live).

An optional block of 8 buttons, each with an LED. There are 16 tracks, so the buttons work on the **visible half** — 1–8 or 9–16, the same one [Overview](#grid) shows. The half is not a mode: the cursor selects it. Move past track 8 (<kbd>Shift</kbd>+turn, tapping a track name in Detail, a track button) and the buttons and LEDs switch to 9–16; move back and they return to 1–8. The GRID header shows which half is active: `1-8` or `9-16` on the left above the step numbers.

| Action | What it does |
|---|---|
| <kbd>N</kbd> | Select track N of the visible half (in 9–16, button 1 is track 9): the GRID cursor moves to it, TRACK shows it. |
| <kbd>Shift</kbd>+<kbd>N</kbd> | Mute / unmute the same track (N of the visible half), on any screen. The toast `TRACK n MUTE` / `TRACK n ON` shows the real number, 1–16. |
| Hold <kbd>N</kbd> + turn | Volume of track N (Volume, INT) on any screen, ×10 with <kbd>Shift</kbd>; toast `TRK5 VOL 100`. The turn does not reach the screen meanwhile. The press on its own works as usual (selects the track). Not active in GRID edit mode, REC or PERF — there the buttons play. On a MIDI track: `TRK5 MIDI`, nothing changes. |
| <kbd>N</kbd> in GRID edit mode | Write the project scale degree into the step under the cursor and move the cursor one step down. On an INT track the note sounds immediately if Preview is on in PROJ. Buttons 1–7 are degrees I–VII, 8 is I an octave up. In scales with fewer than 7 notes (pentatonics, blues) the extra buttons continue the scale into the next octave; Chromatic enters major-scale degrees. The octave follows the note under the cursor, or on an empty step, the track's last entered note. |
| <kbd>N</kbd> in the sample editor (INST, SMPL page) | Play a slice to the end: 1 — the selected slice (if no slice is selected, the first one), 2 — the one after it, and so on. Works with any Slices setting (OFF, NOTE, FX), at the original pitch. Toast "SLICE n"; no such slice — "NO SLICE n"; no slices at all — "NO SLICES". |
| <kbd>Shift</kbd>+<kbd>N</kbd> in GRID edit mode | The same degree an octave up. |
| <kbd>N</kbd> in GRID edit mode on a [drum track](#drumtrack) | Toggle lane N in the step under the cursor. The cursor doesn't move; no Shift needed. |

The LEDs show the same half as the buttons: LED N is track N of half 1–8 or 9–16. A track flashes on each of its notes; a muted track stays dark. The selected track is lit steadily and goes dark on its notes. Activity of tracks in the other half is not shown. Degree entry and slices in the sample editor don't depend on the half — there the button number is what counts. OFF and clearing a step work as before, through the menu.

### Wiring

| GPIO | Function |
|---|---|
| `10` | MIDI TX (UART, 31250 baud) |
| `11 / 12` | Encoder A / B (EC11) |
| `13` | Encoder button |
| `14` | Play |
| `21` | Shift |
| `43 / 44` | Track buttons: PCF8575 SDA / SCL, Debug connector (TXD0 / RXD0; optional, schematic in the README) |
| `41 / 40 / 39 / 38` | microSD: CS / MOSI / CLK / MISO (built-in slot) |

The buttons short the pin to GND; the internal pull-up is enabled. MIDI OUT is TRS type A, 3.3 V:

- +3.3 V → 33 Ω → Ring (DIN pin 4)
- GPIO10 → 10 Ω → Tip (DIN pin 5)
- GND → Sleeve (DIN pin 2)

A 74HC14 buffer (two inverters in series) is optional. There is no MIDI input; the device is always the clock master.

## Screen and status bar

    S03 P05*  >P07  120 BPM  5/16  PLAY  L3  CPU  42%
    tab work area
    GRID  TRACK  MIX  BANK  INST  PROJ  FILE

| Element | Meaning |
|---|---|
| `P05` | The pattern currently playing. In song mode — `S03 P05`: third chain entry, pattern 5. `S--` — the chain hasn't started yet. |
| `*` | There are unsaved changes. |
| `>P07` | Queued pattern: switches at the end of the pass. Not shown in song mode. |
| `120 BPM` | Tempo. A tap enters tempo editing (red): encoder ±1, ±10 with Shift, range 20–300. Leave with a click, a tap on the work area or a tab change. |
| `5/16` | Step / pattern length. |
| `PLAY` | State: PLAY, PAUSE, STOP. A tap works like the Play button; with Shift, like Shift+Play. |
| `L3` | Pattern pass counter. The CND condition uses it. While fill is held — `FILL`. |
| `CPU 42%` | Built-in synth load: the average time to compute an audio block over the last 0.5 s, as a % of the block duration (4 ms). Gray below 60%; yellow at 60–84% or if any block in those 0.5 s took longer than 4 ms (the DMA queue headroom covers that); red from 85% or for 2 s after an audio dropout (DMA ran empty — an audible click). While no audio is being computed, the last value is shown. |

Tabs switch only by tapping the bottom bar. Yellow messages (toasts) cover the right part of the status bar for 1.5 seconds.

**Menus** open in the center of the screen and show up to 12 items; long lists scroll by dragging. Encoder: turn to select (wraps around: after the last item comes the first), click to execute, long press to close. All parameter and file lists wrap around the same way. A tap outside the menu also closes it. Gray items are currently unavailable.

## GRID: pattern editor

GRID always edits the pattern that is playing. When the pattern changes (queue, chain, loading), the cursor moves to step 1, edit mode turns off and the selection is cleared.

### Two views

- **Overview** (default): 8 columns — one half of the 16 tracks, the one the cursor is in: 1–8 or 9–16. Which half is on screen is shown on the left above the step numbers: `1-8` or `9-16`. The half is not a separate mode: when the cursor moves from track 8 to track 9 (<kbd>Shift</kbd>+turn, tapping a track name in Detail, a [track button](#trackkeys)), the second half is shown; move back and the first returns. The [track buttons and LEDs](#trackkeys) follow the same half. A cell shows the note, a velocity bar and a yellow dot if the step has fx. The dot is gray if all of the step's fx are synth fx on a MIDI track (they have no effect there). Every fourth step is highlighted, and the playback row is marked.
- **Detail**: one (the current) track across the full width, 14 fields: NOTE, VEL and six pairs FX1…FX6 with their values. The track number (`T3`) is above the step numbers, the name above NOTE/VEL. <kbd>Shift</kbd>+turn past the last field moves to the next track; the track buttons switch it too. Tapping the name row mutes (with <kbd>Shift</kbd>, solos) that track. Synth fx on a MIDI track are shown in gray.

Track name color: yellow — solo, gray — not audible, white — normal.

### Encoder

| Input | Outside edit mode | In edit mode |
|---|---|---|
| Turn | Step up/down (wraps around) | Change the field value |
| <kbd>Shift</kbd>+turn | Overview: another track. Detail: another field | Coarse step |
| Click | Enter edit mode (toast with the field name) | Leave edit mode |
| <kbd>Shift</kbd>+click | Toggle Overview / Detail | |
| Long press | Context menu | |
| <kbd>Shift</kbd>+long press | Undo | |

### What a turn changes in edit mode

- **NOTE.** On an empty step, the track's last entered note is placed (C-4 at first). After that the note moves by degrees of the project scale, by octaves with Shift. The encoder cannot clear a step or set OFF; use the menu for that. On an INT track every entered note (encoder, mini keyboard, track buttons) sounds immediately with the track's instrument if Preview is on in PROJ.
- **VEL.** 0–127, ×10 with Shift. A value of 0 is shown as `...` and means "the track's default velocity".
- **FX1…FX6.** Cycles through the commands by group, related ones next to each other: `...`; notes and arp CHD, STR, ARP, ARM, ARS; time RAT, NDG, GAT, TIE, OFF, CUT; randomness PRB, CND, VRN, NRN; pitch and volume SLD, VIB, PBN, VSL, ACC; sound FLT, RES, DRV, DEC, COL, SHP, SWP, CON; sample OFS, SLC; sends DLY, RVB; MIDI only CHN, CCA, CCB, PGM (turning back from an empty slot goes straight to PGM). The order is the same as in the [table](#fx). Choosing a command sets its default value and shows its full name in the status line (for example, VIBRATO). On an empty slot, the first turn places the last fx written to this slot on this track, with the same value — handy for repeating an fx step after step; further turns cycle through the commands as usual.
- **FX VAL.** ±1, ×10 with Shift. For CND the step is the same with Shift. On an empty slot the first turn likewise inserts the track's last fx; if there was none yet, the value doesn't change.

One edit session (from entering to leaving edit mode) is one undo step.

### Mini keyboard

Appears at the bottom of the screen when editing the NOTE field. Twelve keys — the octave of the current note. A yellow bar marks scale notes, a red frame the current note. Tapping a key writes the note — any note; the scale doesn't restrict it here. <kbd>Shift</kbd>+encoder turn changes the octave.

### Drum track

A track whose TRACK → Instr is set to a [KIT](#kit) instrument is a drum track: a step holds not a note but a set of 8 lanes (kick, snare, hats…). The step stores a lane mask and one velocity for all of the step's lanes.

- **Overview:** the cell shows 8 small squares; a filled one means the lane sounds. There is no velocity bar; the fx dot is in the top corner of the cell.
- **Detail:** the NOTE field shows the same squares, the VEL field the step velocity (`...` — the track's Def vel).
- **Editing NOTE:** a turn moves the red frame across lanes, <kbd>Shift</kbd>+turn toggles the lane under the frame. Instead of the mini keyboard, the bottom shows a **pad of 8 buttons** with the lanes' sample (or instrument) names; a lit one means the lane is in the step; a tap toggles the lane. [Track buttons](#trackkeys) 1–8 do the same in edit mode. A lane sounds as soon as it's turned on (Preview in PROJ).
- **Editing VEL:** 1–127, ×10 with Shift.
- A step with all lanes turned off stays (silent, fx still work) — remove it with Clear step. OFF is set as usual through the menu and releases all lanes.
- A step's fx apply to all its lanes: RAT repeats each one, NDG shifts them, PRB and CND decide for the whole step, DEC / FLT / DLY and other locks apply per voice. CHD, NRN, STR, TIE, ARP, SLD, VIB and SLC do nothing on a drum track. The **ACC** fx is for drum tracks only.
- **Transpose** skips drum tracks (toast "DRUM TRACK" if the selection contains only them).
- Copy / Paste between drum and regular tracks copies the bytes as is: a lane mask becomes a velocity and vice versa. Likewise, switching a track's instrument between KIT and non-KIT reinterprets the steps already written.
- On a MIDI track each lane goes out as its own note (the lane's Note) on the track's channel — this way a KIT drives an external drum machine (GM map: 36 — kick, 38 — snare, 42 — closed hat…).

### Touch

| Gesture | Action |
|---|---|
| Tap a cell | Moves the cursor there. Tapping the cell under the cursor toggles edit mode. Clears the selection. |
| <kbd>Shift</kbd>+tap | Selection: the first tap sets a corner, subsequent taps move the opposite corner. |
| Long tap | Moves the cursor there and opens the context menu. |
| <kbd>Shift</kbd>+long tap | Undo. |
| Tap a track name | Mute. With Shift — solo. |
| Drag | Scrolls rows. Disables follow until the next start. |

**Follow**: during playback, if the cursor hasn't been touched for 2 seconds, the screen scrolls to the playing step by itself. Toggle it in the context menu.

### Selecting with the encoder

Menu → **Select** sets a selection corner at the cell under the cursor. While a selection exists, any cursor movement (turn — by steps, <kbd>Shift</kbd>+turn — by tracks or fields) moves the opposite corner. A long press opens the selection menu, a click clears the selection. After **Copy sel** the selection is cleared: move the cursor away and choose **Paste**. Clear, Note OFF and Transpose keep the selection.

### Context menu

| Without selection | With selection |
|---|---|
| Copy step · Paste · Clear step · Note OFF · Select · Copy track · Clear track · Transpose track… · **Fill…** · **Resample track** · **Resample pattern** · **Rec: ON/OFF** · **Perf: ON/OFF** · Detail view / Overview · Follow: ON/OFF · Undo | Copy sel · Paste · Clear sel · Note OFF sel · Transpose… · **Fill…** · Undo · Clear selection |

- **Transpose…** opens a dialog: **Amount** and **Mode** (SCALE — scale degrees, CHROMATIC — semitones), with OK / CANCEL buttons. The range is two octaves up and down (in SCALE that is 2 × the number of scale notes; ±14 for major). <kbd>Shift</kbd>+turn changes Amount by an octave. Long press — Cancel. Affects only steps with a note; without a selection, the whole track; one undo step. It is a shift, not a state: Amount starts at 0 every time the dialog opens; to restore the notes, apply the opposite shift (+12, then −12). Mode is remembered until power-off.
- Paste inserts at the cursor position or at the top-left corner of the selection. It doesn't go past track 16 or the pattern length; the selection is also clipped at track 16.
- The clipboard survives loading another project — so you can move parts between projects.
- If the pattern changed while the menu was open, the action is not performed (toast "PATTERN CHANGED").

### REC and PERF: track buttons live

Two modes from the GRID context menu. They exclude each other and edit mode: turning one on turns the others off. The header above the step numbers shows `REC` (red) or `PERF` (yellow). They work during playback; when stopped, the buttons behave as usual.

- **REC** — records from the track buttons into the current track. Button N writes scale degree N (in the octave of the track's last note) into the playing step; a press in the second half of a step lands in the next one. <kbd>Shift</kbd>+N erases that step's note. On a drum track button N sets lane N, <kbd>Shift</kbd>+N removes it. Each pattern pass is one undo step. Choose the track to record into by tapping its name (in REC this is not mute) or with <kbd>Shift</kbd>+turn. The recorded note sounds immediately if Preview is on.
- **PERF** — an effect on the current track while the button is held; the press shows its name (`PERF FILTER LOW`). Which effect is on which button is set in [PROJ → PERF](#proj) and stored in the project. Release — the effect is removed. Pressing another button replaces the effect. <kbd>Shift</kbd>+N still mutes.

| Effect | What it does | Output |
|---|---|---|
| RAT 2 / RAT 3 / RAT 4 / RAT 8 | retrigger (by default RAT 2 is button 1, RAT 4 is button 2) | both |
| ROLL UP | RAT 8 with rising velocity — a "build-up" | both |
| FILTER LOW / FILTER HIGH | FLT 30 / FLT 120 (buttons 3, 4) | INT |
| DELAY MAX / REVERB MAX | DLY 127 (button 5) / RVB 127 | INT |
| CRUSH / DOWNSAMPLE / DRIVE | BIT 100 (button 6) / SRR 90 / DRV 100 | INT |
| SHORT DECAY | DEC 20 — short DECAY macro | INT |
| FADE | fade VSL −16; on MIDI, half velocity (button 7) | both |
| MUTE | track mute (button 8) | both |
| --- | the button does nothing | |

The effect is added to steps as they play: the step's own fx stay, and the same command in the step is replaced. Steps already scheduled ahead (up to an eighth note) play as they were. Stop removes all effects; leaving GRID removes the held one.

### Resample

**Resample track** and **Resample pattern** in the GRID menu record the playing pattern with the built-in sound into a new project sample: only the current track, or all audible tracks (respecting mute / solo). The sample is named `RS1`, `RS2`… (the first free name), normalized to −1 dBFS, trailing silence is trimmed, and there is no delay / reverb tail past the end of the pattern. You can then select it in INST (SAMPLE or a KIT lane) and save it with the project.

- Only when stopped (`STOP FIRST`). The pattern is rendered twice (measuring, then recording), each pass roughly in real time — progress `RENDER nn%`; a long encoder press or Play cancels (`CANCELLED`).
- Nothing longer than 60 s is recorded: `SAMPLE CAP`, the sample is still added. No room in flash — `BANK FULL`; the same if the list already has 128 samples.
- The result: `RS3 2.1s`. The render matches playback (without the 14 ms output latency); notes pushed past the end of the pattern by NDG / swing are cut off.

### Undo

8 steps. Each step is a snapshot of the whole pattern (with 16 tracks the snapshot doubled in size, so the depth is 8 rather than 32). It undoes edits in GRID, menu operations, Fill, and also Copy-to, Clear and Length in BANK. TRACK and PROJ parameters, tempo, mute/solo and chain edits are not undone. There is no redo. Load, New and import clear the history.

### Step

- Note: `C-4` = 60, sharps are `C#4`. Octave −1 is shown as `m`.
- `---` is an empty step, `OFF` an explicit note release (ends TIE and the track's sounding note; on an INT track it releases all its voices, including samples).
- Velocity 1–127 or `...` (the track default). Six fx slots; an empty one is `...`.

## Effects (fx)

Each step has six slots. If the same command is in several slots, the first one wins. The "Output" column: MIDI — MIDI tracks only, INT — INT tracks only (built-in sound), both — everywhere.

| Code | Value | Output | What it does |
|---|---|---|---|
| **Notes and arpeggio** | | | |
| `CHD` | tri 7th su2 su4 6th ad9 pwr oct | both | Chord built from the note: up to 4 notes; notes above 127 are dropped. |
| `STR` | 1–50 | both | Strum: the k-th chord note is delayed by k×STR% of a step. |
| `ARP` | 00–FF (xy) | INT | Arpeggio: note, +x, +y semitones in a loop, three switches per step (ARM changes order and speed) — a fast "chiptune" arp inside the sounding note. With CHD in the same step it arpeggiates the chord notes — see below. For an arp on sequencer steps, use ARS. |
| `ARM` | U1…R8 | INT | ARP mode: the letter is the order (U up, D down from the top, B up-down without repeating the end notes, R random), the digit is notes per step (1–8). A turn changes the digit first, then the letter. The default U3 = plain ARP. Does nothing without ARP; holds together with ARP until the next step with a note. |
| `ARS` | U1…R84 | both | Step arp: each note is a separate hit on the sequencer grid (see [below](#ars)). The letter is the order, as in ARM; the first digit is how many steps until the next note (1 — every step, 2 — every other step …, up to 8); the second digit, if present, is the range in octaves (2–4; without it, 1 octave): `U12` — up, every step, 2 octaves. A turn changes the steps first, then the octaves, then the letter. |
| **Time and length** | | | |
| `RAT` | 2–8, 2^…8^, 2v…8v | both | Retrigger: N equal hits within a step. Gate is a fraction of the sub-step, 95% max. After 8 the turn goes to `2^…8^` — hit velocity rises up to the step velocity, then `2v…8v` — falls from it. |
| `NDG` | −50…+50 | both | Shifts the whole step by ±% of the step length. Negative shift works. |
| `GAT` | 1–800% | both | Note length in % of a step. Up to 100% in 1% steps, then 107, 114 … 800%. |
| `TIE` | — | both | The note is not released and holds through empty steps (see below). |
| `OFF` | 0–96 | both | Note off N ticks after the start of the step (NDG included). This step's notes are released no later than that (RAT hits after that moment don't sound, TIE is cancelled; on a step with a note, no earlier than 1 ms), and a hanging TIE on the track is released. On an INT track all the track's voices are released, including samples and DRUM — with the normal release (CUT — without release). On an empty step `OFF 0` = OFF in the note column. |
| `CUT` | 1–96 | INT | Cut the note after N ticks, without release. A tick is 1/96 of a quarter note: a 1/16 step = 24 ticks. |
| **Randomness and conditions** | | | |
| `PRB` | 0–100 | both | Probability that the step triggers, %. |
| `CND` | FST, A:B, FIL, NFL, PRE, !PR, NEI, !NE | both | Condition based on passes and on other conditions (see below). |
| `VRN` | 0–64 | both | Random velocity spread ±N. |
| `NRN` | 1–7 | both | Random note shift by ±N scale degrees. |
| **Pitch and volume** | | | |
| `SLD` | 1–255 | INT | Glide, time ≈ value × 4 ms (4 ms … 1.02 s). |
| `VIB` | 00–FF (xy) | INT | Vibrato: x — rate (x × 0.5 Hz), y — depth (up to ±2 semitones at F). |
| `PBN` | −64…+63 | both | Pitch bend: 8192 + v×128. Doesn't reset by itself; return to 0 with a separate step. On INT — shifts the pitch of the track's voices by up to ±2 semitones. |
| `VSL` | −64…+63 | INT | Smooth volume change over one step: ±64 spans the full range. |
| `ACC` | 00–FF | both | [Drum tracks](#drumtrack) only: a mask of lanes at full step velocity (bit 0 — lane 1); the step's other lanes sound at 60%. On other tracks it is shown in gray and has no effect. |
| **Sound (instrument locks)** | | | |
| `FLT` | 0–127 | INT | [Filter](#filter) cutoff for the step's note, any instrument type. |
| `RES` | 0–127 | INT | Filter reso for the step's note, any instrument type. |
| `DRV` | 0–127 | INT | Drive (overdrive) for the step's note, any instrument type; on a step without a note, for the sounding note. |
| `BIT` | 0–127 | INT | Bitcrusher for the step's note: bit depth from 16 bits (0 — off) down to 2 bits (127). After Drive, before the filter. The constant value is INST → FILT → Bit crush; the step lock replaces it. |
| `SRR` | 0–127 | INT | Sample-rate reduction for the step's note: 0 — off, 127 — each sample is held for ≈ 64 samples (a rough "digital" sound). Together with BIT — classic lo-fi. The constant value is INST → FILT → Downsample. |
| `DEC` | 0–127 | INT | FM, DRUM, SYNTH: the DECAY macro for the step's note (for DRUM — the machine slot with the same number, for SYNTH — SHP1). |
| `COL` | 0–127 | INT | FM, DRUM, SYNTH: the COLOR macro for the step's note (for DRUM — the machine slot with the same number, for SYNTH — SHP2). |
| `SHP` | 0–127 | INT | FM, DRUM, SYNTH: the SHAPE macro for the step's note (for DRUM — the machine slot with the same number, for SYNTH — MIX). |
| `SWP` | 0–127 | INT | FM, DRUM, SYNTH: the SWEEP macro for the step's note (for DRUM — the machine slot with the same number, for SYNTH — DET). |
| `CON` | 0–127 | INT | FM, DRUM, SYNTH: the CONTOUR macro for the step's note (for DRUM — the machine slot with the same number, for SYNTH — SENV). |
| **Sample** | | | |
| `OFS` | 0–255 | INT | Starts the sample at value/256 of the Start–End region. SAMPLE only. |
| `SLC` | 0–31 | INT | Sample slice for the step's note: 0 — the first slice, 31 — the 32nd. SAMPLE with Slices = FX only (see [slices](#slices)). |
| **Sends** | | | |
| `DLY` | 0–127 | INT | Send to [delay](#delay) for the step's note (replaces the instrument's Dly send), any instrument type. |
| `RVB` | 0–127 | INT | Send to [reverb](#reverb) for the step's note (replaces the instrument's Rvb send). |
| **MIDI only** | | | |
| `CHN` | 1–16 | MIDI | MIDI channel for this step: notes, CC, PB, PGM. |
| `CCA` | 0–127 | MIDI | CC with the track's "CC A" number (default 74). |
| `CCB` | 0–127 | MIDI | CC with the track's "CC B" number (default 71). |
| `PGM` | 0–127 | both | Program Change. On INT — the track's instrument: 0 = INS1 … 31 = INS32, above 31 — INS32. Lasts until playback ends; not written to TRACK → Instr. |

### Step arp (ARS)

ARP plays the arpeggio notes inside a single sounding note, fast and without a new attack. ARS is an arp on the sequencer grid: each arpeggio note sounds as a separate step note with its own attack, and it works on both INT and MIDI.

- **Which notes.** With CHD in the step — the chord notes; otherwise with ARP (not 00) — note, +x, +y; otherwise — the note itself. A range of 2–4 octaves repeats these notes one, two, three octaves up (C E G → C E G C' E' G' …); a single note without CHD or ARP always spans at least 2 octaves. Notes above 127 are taken an octave lower.
- **How it runs.** The step with ARS plays the first note (U — the lowest, D — the highest across the whole octave range; B goes up and back through the whole range). The track's following steps without a note play the next notes: every step with digit 1, every second step with 2, and so on. You don't need to fill the empty steps — the arp runs by itself.
- **When it stops.** On the next step with a note (a new arp or just a note), on OFF (in the note column or fx OFF), on a pattern change, on stop. Repeating the same pattern doesn't interrupt the arp.
- **Note length** — the GAT of the ARS step (or the track's Gate), relative to the interval between arp notes; a note is always released before the next one. Velocity — as on the ARS step.
- **Fx on arp steps.** The fx of an empty step that an arp note falls on apply to that note (for example, FLT or DLY). ARP, ARM, TIE and STR have no effect in a step with ARS; ARS has no effect on drum tracks.

Example: note C-4, CHD tri, ARS U1, empty steps below and OFF on step 9 — eight sixteenths C E G C E G C E.

### Synth fx on INT tracks

**ARP + CHD.** If a step has both ARP (not 00) and CHD, an INT track plays a single note and ARP cycles through the chord notes (in the project scale) instead of 0, x, y — in ARM's order and speed. On a MIDI track the chord sounds in full, as before. ARP 00 with CHD is a plain chord.

SLD, VIB, ARP, VSL, OFS, CUT, DEC, COL, SHP, SWP, CON, FLT, RES, SLC, DLY, DRV, RVB, ARM only take effect on tracks with Out = INT. On MIDI tracks they send nothing and are shown in gray. VIB and ARP values are hexadecimal: `47` = x 4, y 7.

- **Step with a note.** The fx apply to that step's note. A new step with a note resets VIB and ARP: to keep the vibrato or arpeggio going, repeat the fx.
- **Step without a note** (empty or OFF). VSL, CUT and ARP act immediately on the track's sounding voices; VIB changes the parameters of the sounding vibrato. SLD glides the sounding voice to the track's last played note. VIB and ARP hold until the next step with a note.
- **SLD on a step with a note:** if the track's voice is still sounding, it glides to the new note without a new attack (legato); otherwise the new note starts from the previous note's pitch.
- **ARP:** each of the three values lasts a third of a step. `00` turns it off.
- **VSL** is counted from the note's velocity; a full rise or fall takes exactly one step (taking the pattern resolution into account).
- **CUT:** tick length is taken from the tempo (tick = 1/96 of a quarter note) and doesn't depend on the resolution. If CUT is shorter than the gate, the note is cut earlier.
- **OFS** works only on SAMPLE and only at the start of a note; with Reverse it counts from the end. If the note plays a slice, OFS counts within the slice.
- **SLC** works only on SAMPLE with Slices = FX and only at the start of a note, like OFS: the first note-on of the step plays the chosen slice at the note's pitch (with a chord or RAT, the other notes play the whole region). Without SLC, or if the number is not less than the number of slices, the whole Start–End region plays. On a step without a note SLC does nothing.
- **DEC, COL, SHP, SWP, CON** (macro p-locks) work only on [FM](#fm), [DRUM](#drum) and [SYNTH](#synth); they are ignored on CHIP and SAMPLE. On a step with a note, the value replaces the instrument's macro for that note; on a step without a note, for the track's sounding note until the next note. The next step doesn't inherit the lock. For TONE and CHORD the envelope decay is fixed at the start of the note: DEC on a step without a note (and LFO on DECAY) doesn't change the length of a note already sounding.
- **FLT, RES** (filter p-locks) work on all types, but only when Filter is not OFF. The value replaces the instrument's Cutoff or Reso: on a step with a note — for that note; on a step without a note — for the track's sounding voices until the next note. The filter envelope, Key track and LFO CUTOFF are added to the lock value.
- **DLY** (delay send p-lock) works the same way: on a step with a note — the send of that step's notes; on a step without a note — the send of the track's sounding voices until the next note. Handy for echo "throws" on individual hits: instrument Dly send at 0, `DLY 127` on the steps you want.

Other fx on INT: RAT, GAT, PRB, TIE, NDG, CHD, STR, CND, VRN, NRN work as on MIDI; PBN and PGM — see the table; CHN, CCA, CCB are ignored.

### CHD chords

tri = 1-3-5, 7th = 1-3-5-7, su2 = 1-2-5, su4 = 1-4-5, 6th = 1-3-5-6, ad9 = 1-3-5-9 — degrees of the project scale. pwr = note + fifth (7 semitones), oct = note + octave. With the chromatic scale, the chord is built as in major from that note.

### CND condition

- `FST` — only on the first pass after start or a pattern change.
- `A:B` — on the A-th pass out of every B. For example, `2:4` — on the 2nd, 6th, 10th… B ranges from 2 to 8.
- `PRE` / `!PR` — the step plays if the last condition on this track (CND A:B / FST / FIL / NFL or PRB) was / was not met. `NEI` / `!NE` — the same for the track to the left (on track 1 NEI never triggers). PRE / NEI themselves don't count as the "last condition": handy for building chains of variations — a step with `1:2`, and a few steps later `PRE` plays on exactly the same passes.
- `FIL` — only while fill is held (<kbd>Shift</kbd>+<kbd>Play</kbd> during playback), `NFL` — only while it isn't. They come after 8:8. Steps already scheduled ahead (up to an eighth note) are decided by the state at scheduling time.
- Passes are counted by the `L` counter in the status bar. It resets on start and on a pattern change.

### TIE

- The next note of the same pitch on the same channel continues the sound without a new attack (legato). Its end is set by its gate or by another TIE.
- A different note starts, and the old one is released 1 ms later (overlap).
- TIE is released by: OFF, mute, a failed CND/PRB on a step with a note, a pattern change.
- TIE doesn't work on chords. With RAT only the last hit is tied.

### Step processing order

CND first, then PRB. If any condition fails, the whole step is silent, including CC/PB/PGM. Then the channel (CHN), then controllers (at the start of the step, NDG included), then notes. Controllers are sent on steps without a note and on OFF too. A muted track sends nothing.

## Fill, Euclid and arp

Quick track filling, like Fill on the Polyend Tracker: notes, velocity or any FX slot on every N-th step, in a Euclidean rhythm or at random. Open it in GRID: long tap on a cell (or long encoder press) → **Fill…**. With a selection, the selection is filled (all its tracks); without one, the track under the cursor for its length (a track's own length is respected). **What** to fill is taken from the column under the cursor: NOTE, VEL or an FX slot (in Detail view); you can change it in the dialog. The first row, **Type**, switches the dialog between filling (`FILL`) and the [arpeggio generator](#arp) (`ARP`).

| Row | Values | Meaning |
|-----|---|---|
| Steps | EVERY N, EUCLID, RANDOM % | Which steps to write to. Steps are counted from the start of the selection. |
| Every / Offset | 1…length / 0…N−1 | EVERY N: steps Offset, Offset+N, Offset+2N… |
| Hits / Length / Rotation | 0…Length / 1…length / ±(Length−1) | EUCLID: hits, rhythm length (repeats), rotation. |
| Density | 0–100 % | RANDOM %: share of steps. |
| Fill | NOTE, VELOCITY, FX 1–6 | Which field to write. |
| Command | any FX command, `...` | For FX: the slot command. `...` clears the slot on these steps. |
| Value | CONST, RAMP, RANDOM | One value, a smooth From→To ramp across the hits, or random within From…To. |
| Value / From, To | note, 1–127 or FX value | For notes, RAMP and RANDOM move through scale notes between From and To (From above To — downward). |
| Mode | OVERWRITE, EMPTY ONLY, NOTES ONLY | OVERWRITE writes to all chosen steps; EMPTY ONLY — only where the field is empty (no note / track velocity / free slot); NOTES ONLY — only to steps with a note. |
| Seed / Reseed | — | Variant for RANDOM. Reseed (or <kbd>Shift</kbd>+click) — a new random one. |

- Steps Fill didn't hit stay as they were. To rewrite a track completely, Clear track first.
- VELOCITY is written only to steps with a note: velocity without a note doesn't sound. Accents are done like this: Fill VELOCITY, EVERY 4, Value 127.
- On a [drum track](#drumtrack) NOTE sets a lane (the **Lane** row, 1–8; by default the lane under the cursor), other lanes are left alone; new steps get the track velocity. VELOCITY writes the step velocity.
- Every change is written to the track immediately and sounds. **OK** keeps the result (one undo step). **CANCEL**, a long press or leaving GRID restore everything as it was.
- Settings are remembered until power-off; they are not saved to a file.

The list works the same as in PROJ: turn — row, click — edit, turn in edit mode — value. A tap selects a row, a second tap edits, dragging in edit mode changes the value.

### Arp (Type: ARP)

The first row of the Fill dialog is **Type**: `FILL` (filling, see above) or `ARP`, an arpeggio generator in the spirit of the Access Virus. It does not play live: it writes the arpeggio as notes and fx onto one track (**Dest**). A rhythm pattern (factory or your own) runs over the "held" notes: the chord from the Root and Chord rows, or the notes of the selection. The step range is the same as Fill's: the selection or, without one, the track under the cursor for its length. Preview, **OK** (one undo step, toast `ARP`) and **CANCEL** work as in Fill. The header shows where it writes and where it reads: `ARP T4 1-16`, with Source SELECTION `ARP T4 1-16 < T1-3`.

| Row | Values | Default | Meaning |
|-----|---|---|---|
| Type | FILL, ARP | FILL | Filling or arp. Each has its own set of rows and its own settings. |
| Source | CHORD, SELECTION | CHORD | Where the notes come from: the chord from Root + Chord, or the notes of the selected tracks (see below). |
| Root | any note | the track's last entered note | CHORD: the chord's bottom note. The default is taken on the first open. CHORD only. |
| Chord | tri 7th su2 su4 6th ad9 pwr oct | tri | CHORD: the chord, as in [CHD](#fx), built on the project's scale degrees. CHORD only. |
| Dest | T1–T16 and the track name | the first track of the selection | The track written. It may lie inside or outside the selection. A drum track turns the row red and nothing is written. |
| Mode | UP, DOWN, UP/DN, DN/UP, PLAYED, RANDOM, CONVERGE, DIVERGE, PEDAL, CHORD | UP | Note order, see below. |
| Octaves | 1–4 | 1 | How many octaves: the notes repeat an octave up, one octave after another (above 127 dropped). |
| Pattern | factory, then your own | 16THS | The rhythm pattern. Your own (from `/presets/ARP`) follow the factory ones, alphabetically. |
| Rate | ×1–×4 | ×1 | Track steps per arp step: ×2 runs the arp in eighths on a 1/16 track. The steps in between are left empty. |
| Rotate | 0…pattern length − 1 | 0 | The pattern step to start from. |
| Gate | 5–100 % | 50 % | Length of a normal note. Short (`s`) is half, long (`l`) is 100 %. All × Rate. |
| Swing | 0–100 % | 0 % | NDG = Swing / 2 on the odd arp steps (100 % shifts them by half a step). |
| Vel Lo | 1–127 | 60 | Velocity of ghost notes (`o`). |
| Vel Hi | 1–127 | 120 | Velocity of accents (`X`). A normal note gets the middle between Lo and Hi. |
| Slide | SLD value | 16 | SLD time on slide notes (`~`). |
| Roll | 0–100 % | 0 % | Share of notes with a random RAT 2–4 (slide notes are left alone). |
| Ghost PRB | OFF, 0–99 % | OFF | PRB on ghost notes: they don't play every pass. OFF (100 %) writes no PRB. |
| Mutate | 0–100 % | 0 % | Pattern variations: hits dropped and added, accents and pitches changed. Depends on Seed. |
| Seed / Reseed | — | — | Variant of the random parts (RANDOM, Roll, Mutate); the rows show only when one of them is on. Reseed (or <kbd>Shift</kbd>+click) picks a new random one. |
| Capture | SAVE DEST AS PATTERN | — | Save Dest's rhythm as your own pattern, see below. |

**Modes.** The notes are sorted bottom to top (except PLAYED); Octaves adds copies of them in the octaves above.

| Mode | Order |
|---|---|
| UP | Bottom to top. |
| DOWN | Top to bottom. |
| UP/DN | Up, then down; the end notes are not repeated. |
| DN/UP | Down, then up; the end notes are not repeated. |
| PLAYED | As the notes were taken: a CHORD chord from its bottom note; SELECTION track by track from the top, each with its step note, then the notes of its CHD. |
| RANDOM | A random note on every hit (from Seed). |
| CONVERGE | From the edges to the middle: bottom, top, second from the bottom, second from the top… |
| DIVERGE | From the middle to the edges (CONVERGE backwards). |
| PEDAL | The bottom note every other hit, the others in turn: 1-2-1-3-1-4… |
| CHORD | The whole chord on every hit: the bottom note + CHD (the Chord row; with SELECTION, tri). |

The note cycle runs on continuously: the pattern repeats over the range, and the note cycle restarts neither on a pattern repeat nor on a chord change.

**SELECTION.** The notes of all selected tracks together with their CHD form the held chord. A step with notes on at least one of the tracks replaces the whole chord, which then holds until the next such step. An OFF with no notes on that step releases the chord: the arp is silent until new notes. The source is read from step 1 of the pattern, not from the start of the range: a chord set before the selected steps already sounds on the first of them. The source is taken as it was when the dialog opened, so Dest may lie inside the selection too: the arp is written over the chord it is built from. Drum tracks in the selection are not a source.

**What is written to Dest.** On every step of the range the note and velocity are replaced, and the arp's own fx GAT, TIE, SLD, NDG, RAT, PRB, CHD, ARS and ARP are cleared; other locks (FLT, DLY…) stay. Then on every hit:

- **Note and velocity:** Vel Lo / the middle / Vel Hi by accent.
- **Length:** always GAT. A normal note is Gate %, a short one half of it, a long one 100 %; all × Rate.
- **Tie (`-`):** TIE on the previous note and OFF on the first rest after it. A tie that runs to the end of the range becomes a long GAT to the range's end instead of TIE (up to 800 %); otherwise the note would hang past the range.
- **Slide (`~`):** SLD (the Slide row) on the note, and the previous note's GAT is stretched into the next one so the voice glides legato. After a rest SLD is written too: the synth takes the note from the last pitch. A slide on the first note of the range is not written.
- **Swing:** NDG on the odd arp steps. **Ghost PRB:** PRB on ghost notes. **Roll:** RAT 2–4. **CHORD mode:** CHD.
- No free fx slot: that fx is skipped.

**Pattern format.** A pattern is a line of tokens separated by spaces (or commas), one token per step, up to 32 steps (the rest are ignored). The first character is the step type, followed without a space by note modifiers in any order:

| Token | Meaning |
|---|---|
| `x` | note |
| `X` | accented note (Vel Hi) |
| `o` | ghost note (Vel Lo, Ghost PRB) |
| `.` | rest |
| `-` | tie: the previous note holds |
| `s` | after a note: short (half of Gate) |
| `l` | after a note: long (100 %) |
| `~` | after a note: slide into it from the previous one |
| `r` | after a note: repeat the previous note (the cycle does not move) |
| `p` | after a note: the lowest held note, a "pedal" (the cycle does not move) |
| `^` / `v` | after a note: an octave up / down |

Example: `X x~ x . X x~ X x`: 8 steps, an accent, a slide note, a note, a rest, and again. Unknown tokens are skipped.

**Capture** saves Dest's rhythm as your own pattern: a name from the keyboard (up to 16 characters: A–Z, 0–9, `-`, `_`), file `/presets/ARP/NAME.arp`. It takes Dest's range as it was before the dialog opened (your own line, not the preview), at most 32 steps. A note becomes `x` / `X` / `o` (velocity split into three levels within the range's spread; with a spread under 6 or the track velocity, a normal note), GAT under 35 % `s`, from 90 % `l`, SLD `~`, empty steps after a TIE note `-`, everything else `.`; the same pitch as the previous note becomes `r`, the range's lowest note `p`. The first note is always a plain one (NEXT); octaves are not captured. GAT is captured as written, so capture a line written at Rate ×1: the arp's GAT at Rate ×2–×4 is multiplied by Rate and captures as long notes. After saving, the pattern is selected in Pattern right away (toast `SAVED`). No notes in the range: `NO NOTES`; no valid characters in the name: `BAD NAME`; the write failed (no card etc.): a toast with the error. `.arp` is plain text in the format above, so it can be edited on a computer (card reader). A broken file shows an error toast when selected and plays the first factory pattern. The Pattern list holds up to 32 of your own patterns.

**Factory patterns** (42), by style:

| Style | Patterns |
|---|---|
| BASIC | 16THS, 8THS, TRIPLET, DOTTED, QUARTERS, OFFBEAT, ACCENT 4 |
| TR (trance) | TR GATE, TR OFFBT, TR ROLL, TR PEDAL, TR UPLIFT, TR 332, TR CHUG |
| PSY (psytrance) | PSY GALOP, PSY TRIPL |
| TE (techno) | TE STAB, TE HYPNO3, TE MINIMAL, TE RUMBLE, TE ROLLER |
| HO (house) | HO OFFBT, HO ORGAN, HO PIANO, HO SHUFFLE |
| DNB | DNB ROLL, DNB STAB, DNB AMEN, DNB REESE, DNB 2STEP |
| ACID | ACID 1, ACID 2, ACID 3 |
| EL (electro) | EL FUNK, EL ROBOT |
| BR (breaks) | BR BREAK |
| SW (synthwave) | SW 8THS, SW DRIVE |
| DUB | DUB STAB, DUB ECHO |
| CHIP | CHIP OCT, CHIP RUN |

TRIPLET, PSY TRIPL and TE HYPNO3 are 12 steps long (over 16 steps they make a polyrhythm), the rest 16.

- Dest is a [drum track](#drumtrack): nothing is written, the Dest row is red.
- Slides (SLD) sound only on INT tracks; on a MIDI track SLD is written but does nothing (grey).
- Like Fill's, the arp settings are remembered until power-off; your own patterns live on the card.

## TRACK: track settings

The track is the one under the cursor in GRID. To switch: tap the arrows in the header or <kbd>Shift</kbd>+turn outside edit mode. The mixer for all tracks is the neighboring [MIX](#mixer) tab.

Parameters are on three pages: **MAIN**, **NOTE**, **MIDI**. To pick a page, tap its tab below the header; with the encoder, a turn cycles through the rows and the page tabs (above the first row, framed); a click on the page tabs goes to the next page, <kbd>Shift</kbd>+click to the previous one (the cursor stays on the page tabs).

| Parameter | Values | Default |
|---|---|---|
| **MAIN** | | |
| Name | up to 8 characters: A–Z 0–9 - \_ space | TRK1…TRK16 |
| Out | MIDI / INT | INT |
| Instr | 1–16 (instrument number and name), INT only | 1 |
| Volume | 0–127, INT only | 100 |
| Mute / Solo | ON / OFF | OFF |
| **NOTE** | | |
| Def vel | 1–127 | 100 |
| Def gate | 1–800% | 50% |
| Pat len | OFF or 1…length−1 (in the playing pattern) | OFF |
| Humanize | OFF, 1–100: each note of the track is randomly shifted in time (up to ±10% of a step at 100) and in velocity (up to ±20) — a "live" feel | OFF |
| **MIDI** | | |
| Channel | 1–16 | track number |
| CC A / CC B | CC number 0–127 | 74 / 71 |
| Program | --- or 0–127 | --- (don't send) |

- **Name:** click to edit. A turn changes the character; <kbd>Shift</kbd>+turn or tapping a character moves the cursor.
- **Program** is sent immediately when changed and at every start. The value is "raw": 0 = the first patch.
- **Out:** MIDI — the track plays to MIDI OUT; INT — to the built-in synthesizer (see [Built-in sound](#sound)). You can switch during playback: sounding notes are released, and the following steps go to the new output.
- **Instr / Volume** work only on INT; on MIDI they are gray. On INT, Channel, CC A, CC B and Program are gray. Def vel and Def gate apply to both outputs.
- **Solo:** if solo is on for at least one track, only the soloed tracks play. Mute takes priority over solo.

### MIX

A separate tab at the bottom of the screen, next to TRACK: tap **MIX**. Eight strips for the half of the tracks where the cursor is (1–8 or 9–16, as in Overview GRID), with the **MAIN** strip on the right.

- **Strip:** name (colored as in GRID: yellow means solo, gray means not audible), the track's Volume fader, a level meter next to it (−48…0 dB post-fader, at MAIN 100%; yellow above −6 dB, a red mark for one second means a full-scale peak), the value, its instrument's sends to delay (`S`) and reverb (`R`) — display only, edited in INST — and the **M** (mute) and **S** (solo) buttons. On a MIDI track the fader is empty and `MIDI` is shown instead of the value.
- **MAIN** — the overall volume of the built-in sound, 0–200%, default 100% (it used to live in PROJ). Above 100% you get up to +6 dB, and loud peaks are soft-clipped (the fill turns yellow). It is project data: saved with the project, applied before the soft clip and included in Render WAV. The headphone / speaker level of the device is a separate setting: PROJ → SYS → Phones.
- **Encoder:** turn — **MAIN** volume; <kbd>Shift</kbd>+turn — half **A** (tracks 1–8) / **B** (9–16), shown as a letter on the MAIN strip. Hold a track button and turn — that track's volume (with <kbd>Shift</kbd>, step ×10); <kbd>Shift</kbd>+track button — mute. Solo is only by tapping S. An encoder click does nothing on MIX; there is no strip selection.
- **Touch:** tap or drag on a fader — volume set by finger position (in 8 px steps; for precise values use the track button and encoder); tap M / S.
- **Scope** across the full width at the bottom: the last ≈ 14 ms of the speaker output, ~20 frames per second. Auto-gain (up to ×32, value at top left) stretches a quiet signal to the full height; the real level is the meter on the right (yellow near the top); `CLIP` means a full-scale sample occurred (shown for one second).
- Track volume without going to MIX: hold its button and turn the encoder (see [track buttons](#trackkeys)).

## INST: instruments

32 instruments per project, INS1–INS32 (projects saved before 32 open with INS17–INS32 at their defaults). The instrument for a track is chosen in TRACK → Instr (with Out = INT) or with fx PGM. When you enter the tab, the current track's instrument opens.

Parameters are spread over 5 pages (6 for SYNTH). Below the header are the page tabs: **MAIN**, **ENV**, the type page (**OSC** for CHIP, **SMPL** for SAMPLE, **FM**, **DRUM**; SYNTH has two — **OSC** and **MOD**), **FILT**, **LFO**. The current page is highlighted.

| Input | Action |
|---|---|
| Tap the page tabs | Open the page (cursor on the tabs). |
| Turn | Cycles through the page's rows and the tab strip above the first row (framed when selected). |
| Click / <kbd>Shift</kbd>+click on the tabs | Next / previous page (wraps: after LFO comes MAIN); the cursor stays on the tabs. |
| Tap the arrows in the header | Previous / next instrument (wraps). |
| <kbd>Shift</kbd>+turn outside edit mode | Also changes the instrument. The open page stays the same. |
| **PREVIEW** button / encoder long press | Audition the instrument: note C-4, 0.3 s. Works during playback too. On the SMPL page with Slices = NOTE and a slice selected, that slice plays. |
| **PRESET** button / <kbd>Shift</kbd>+encoder long press | Load / Save menu — [presets](#presets). |
| Turn, click, tap | As in PROJ: row, edit, value. |

The page is remembered when you switch instruments and when you change Type: for example, from FILT of one instrument you land on FILT of the next.

| Page | Rows |
|---|---|
| MAIN | Name, Type, Volume, Transpose, Fine, Mode, Glide, Dly send, Rvb send |
| ENV | Attack, Decay, Sustain, Release, Vel\>Cut, Vel\>Dec and an ADSR graph on the right |
| OSC / SMPL / FM / DRUM | Type parameters: [CHIP](#chip) — Wave, Duty, PWM rate, PWM depth; [SAMPLE](#sample) — sample editor; [FM](#fm) and [DRUM](#drum) — Machine and 5 macros; [SYNTH](#synth) — oscillators and tables |
| MOD (SYNTH only) | Sub, Sub oct, Noise, Env\>Shp, Env atk, Env dec |
| FILT | Drive, Bit crush, Downsample, Filter, Cutoff, Reso, Flt env, Flt attack, Flt decay, Key track — [drive, lo-fi and filter](#filter) |
| LFO | LFO (1–4), Wave, Sync, Retrig, Rate, Depth, Dest |

### MAIN and ENV

| Parameter | Values | Default |
|---|---|---|
| Name | up to 8 characters, edited like a track name; empty becomes INSn | INS1…INS32 |
| Type | FM / SYNTH / DRUM / SAMPLE / CHIP / KIT | FM |
| Volume | 0–127 | 100 |
| Transpose | −24…+24 semitones | 0 |
| Fine | −50…+50 cents | 0 |
| Mode | POLY (up to 4 voices per track) / MONO (one voice, legato) | POLY |
| Glide | OFF, 4–1020 ms; MONO only | OFF |
| Dly send | 0–127, all types | 0 |
| Rvb send | 0–127, all types (for KIT — for the whole kit) | 0 |
| Vel\>Cut (ENV) | −64…+63; gray without a filter | 0 |
| Vel\>Dec (ENV) | −64…+63; FM, DRUM, SYNTH | 0 |
| Attack / Decay / Release (ENV) | 0 ms … 10 s (exponential scale, 128 values) | 0 / 18 ms / 9 ms |
| Sustain (ENV) | 0–100% | 79% |

**Dly send** — how much of the instrument's sound goes to the shared [delay](#delay) (the dry sound does not get quieter). For individual steps, use fx [DLY](#synthfx).

**Rvb send** — send to the shared [reverb](#reverb); for steps, use fx RVB.

**Velocity.** Vel\>Cut shifts the filter cutoff by note velocity: at +63 a note with velocity 127 is opened ≈ 6 octaves higher, and one with velocity 1 the same amount lower; velocity 64 changes nothing. Vel\>Dec shifts the DECAY macro (for SYNTH, the first macro, SHP1) the same way by ±63 steps. 0 means off.

**Glide** — portamento between overlapping notes in MONO (legato). For individual steps there is fx [SLD](#synthfx).

**The ADSR graph** on the ENV page follows the values: the widths of the attack, decay and release segments are logarithmic in time, the height of the plateau is Sustain. If the type has no envelope (FM drums, DRUM), the graph is gray, like the rows.

### CHIP (OSC page)

| Parameter | Values | Meaning |
|---|---|---|
| Wave | PULSE, TRI, SAW, NOISE, METAL, WT1–WT16 | Waveform. NOISE is noise (higher note — brighter, lower — darker), METAL is "metallic" noise with a tone at the note's pitch, WT1–WT16 are wavetables built into the firmware. |
| Duty | 1–99% | PULSE duty cycle. |
| PWM rate | 0–127 | Speed of the duty cycle sweep (0 — off). |
| PWM depth | 0–49% | Sweep depth. |

Duty, PWM rate and PWM depth are active only for PULSE; for other waves they are gray.

### SAMPLE (SMPL page)

**A sample plays to the end.** On pattern tracks SAMPLE ignores note off: GAT and TIE are not needed, the sample (or slice) plays to the end of its region, and with a loop — forever. The envelope works (Sustain 0 silences it after Decay). The sound is stopped by: OFF in the note column, fx `OFF` and `CUT`, stop, and **choke** — a new sample note on this track silences its previous samples within 3 ms. Notes of the same step (chord CHD, STR) do not choke each other; a repeat of the same note (RAT) does. In MONO the next note always restarts the sample from the beginning; legato (continuing from the same position) is only possible with SLD; Glide does not work for samples. Auditioning (Preview, the editor) still cuts off on release.

The SMPL page is the sample editor: a large waveform with markers at the top, a button strip below it, and below that a list of rows (2 rows visible, the list scrolls).

| Parameter | Values | Meaning |
|---|---|---|
| Marker | `S`, `E`, `L` or `#n` and position in % | The selected marker (see below). Click to edit: turning moves the marker. |
| Sample | --- or a project sample | Steps through the [project samples](#samples) (FILE → SAMPLES); samples from other projects are not visible. Selecting a sample sets its Root and Loop and erases the slices. A red name means the sample is unavailable (MISSING or removed from the project): the voice is silent, and after importing it again under the same name it plays again. |
| Root | C-m…G-9 | The note at which the sample plays at its original pitch. With Slices = NOTE, this note plays slice 1. |
| Start / End | 0–100%, step 0.1% | The played region of the sample. Start cannot exceed End. |
| Loop | OFF, FWD, PING | No loop, forward loop, ping-pong. With a loop the sample plays until it is stopped (see below). |
| Loop start | 0–100% | Loop start as a fraction of the Start–End region (loop end = End). Gray with Loop OFF. |
| Reverse | ON / OFF | Play backwards; the loop is mirrored. |
| Slices | OFF, NOTE, FX | How [slices](#slices) are played: OFF — not played (the whole region, as before), NOTE — by notes from Root, FX — with the `SLC` command. |
| Chop | EQUAL, TRANS | Auto-slicing method for the CHOP button: equal parts or by transients (attacks). |
| Chop N / Sens | 2–32 / 0–100% | With EQUAL the row is called Chop N — the number of parts (default 8). With TRANS it is Sens, the sensitivity: 0% — strong attacks only, 100% — all detected ones (default 50%). |

**Waveform:** the Start–End region is light, everything outside it is gray. Markers: green Start, red End, yellow Loop start (only if Loop is not OFF), cyan slices numbered 1, 2, 3… (labels that don't fit are skipped). The selected marker is thicker. In the top right corner is the zoom: `x1`, `x2`, `x4` … and `1:1` at maximum (one sample per pixel). Without a sample — `NO SAMPLE`; if the sample is unavailable — a red `MISSING`.

| Button | Action |
|---|---|
| **\<** / **\>** | Select the previous / next marker by position on the waveform (Start, End, Loop and slices mixed, in the order they sit). |
| **−** / **+** | Halve / double the zoom. Centered on the selected marker. |
| **CHOP** | Re-slice the Start–End region according to the Chop and Chop N / Sens rows; old slices are erased. EQUAL — Chop N equal parts. TRANS — the first slice at Start, the rest on attacks, up to the 31 strongest. After chopping, slice 1 is selected. |
| **CLR** | Tap — delete the selected slice (selection moves to the previous one). Long press — delete all slices. |

| Input on the waveform | Action |
|---|---|
| Tap | Select the nearest marker (within ~16 px). |
| Horizontal drag of a marker | Move it. With <kbd>Shift</kbd> the marker snaps to the nearest transient. |
| Drag on empty space | At zoom above x1 — scroll the waveform. |
| Long tap | New slice at that point (with <kbd>Shift</kbd> — at the nearest transient). Not added if there are already 32 slices or the point is taken. |
| Marker row in edit mode: turn | Move the selected marker by 1 pixel at the current zoom (at 1:1 — by one sample); the waveform scrolls to follow the marker. |
| Marker row in edit mode: <kbd>Shift</kbd>+turn | Jump to the next / previous transient. |

- The Marker row is the first on the SMPL page, Chop N / Sens the last: turning wraps around through the tabs; for other pages click on the tabs.
- A slice can only move between its neighboring slices; it cannot overtake them. Slices are stored as a fraction of the whole sample and do not depend on Start / End.
- Transients (attacks) are detected automatically from rising loudness, no closer than 40 ms to each other. They are used both for <kbd>Shift</kbd> snapping and for Chop TRANS.
- Changing the sample (Sample row) erases the slices.

### Slices: playback

Up to 32 slices per instrument. Slice n plays from its marker to the next slice; the last one plays to End (if End is to its left — to the end of the sample). While there are no slices, NOTE and FX sound like OFF.

- **NOTE:** the Root note plays slice 1, Root+1 plays slice 2 and so on (slice number = note − Root + 1). Notes below Root and above the last slice are silent. The slice plays at its original pitch (Transpose and Fine work) — handy for laying a break out across the keys.
- **FX:** notes play the whole Start–End region at normal pitch, and fx [SLC](#fx) on a step picks the slice for that step's note: `SLC 0` — slice 1, `SLC 31` — slice 32. The slice plays at the note's pitch (like a regular sample from Root). Without SLC, or with a number not less than the slice count — the whole region.
- You can audition slices with the [track buttons](#trackkeys) right in the editor: 1 — the selected slice, 2 — the next one, etc.
- A slice plays once: Loop and Loop start are ignored. Reverse works within the slice (from its end to its start), and so does OFS.

### FM

**FM** — 8 machines in the style of Model:Cycles: KICK, SNARE, METAL, PERC, TONE, CHORD, CLAP, HAT. Instead of operators there are 5 macros: DECAY (length), COLOR (brightness / index), SHAPE (timbre variant; for CHORD — the chord type), SWEEP and CONTOUR (pitch or index envelope). Drums play one-shot (note length and ADSR don't matter, a new note cuts off the previous one); TONE and CHORD hold the note (attack / sustain / release from the ADSR). TONE can be POLY; the other machines are mono per track. The LFO is on the shared [FILT and LFO](#filter) pages; for FM it can also drive the macros.

P-lock: fx `DEC`, `COL`, `SHP`, `SWP`, `CON` (0–127) set a macro for the note on their step; on a step without a note — for the sounding note until the next one (see [synth fx](#synthfx)).

| Parameter | Values | Meaning |
|---|---|---|
| Machine | KICK, SNARE, METAL, PERC, TONE, CHORD, CLAP, HAT | The machine. Changing the machine sets its default macro values. |
| DECAY | 5 ms … 4 s | Length: for drums — the sound's decay; for TONE and CHORD — the decay to Sustain (replaces Decay). |
| COLOR / SHAPE / SWEEP / CONTOUR | 0–127 | Meaning depends on the machine, see the table below. |

| Machine | COLOR | SHAPE | SWEEP | CONTOUR |
|---|---|---|---|---|
| KICK | index: from sine to punch and click | "body" (modulator ratio 0.5–2); the upper half adds feedback | pitch drop, up to 48 semitones | drop time 5–200 ms |
| SNARE | tone / noise balance | noise filter: lower half — BP 0.8–4 kHz, upper half — HP 2–8 kHz | tone pitch drop, up to 12 semitones | noise length relative to the tone |
| METAL | index | frequency set: bell → cowbell → gong → cymbal | slight pitch drop, up to 5 semitones | modulator fades faster than the carriers |
| PERC | index: tom → wood, rim, click | modulator ratio 1–7, including inharmonic ones | pitch drop, up to 24 semitones | drop time 5–200 ms |
| TONE | brightness (constant part of the index) | 5 zones: sine, "saw", "square", stack, bell | decaying part of the index (pluck) | its time 20 ms … 2 s |
| CHORD | from sine to saw (feedback) | chord type, 12 zones | decaying brightness boost | its time 20 ms … 2 s |
| CLAP | noise filter frequency (BP 0.6–3 kHz, higher with the note) | number of claps 2–5 and spacing 5–15 ms | filter resonance | tail level relative to the claps |
| HAT | HP cutoff 3–12 kHz | metal / noise balance | metal frequency spread | metal and noise length relative to DECAY |

Base pitch at C-4: KICK 55 Hz, SNARE 180 Hz, PERC 200 Hz, METAL 400 Hz, HAT 3.5 kHz; TONE and CHORD follow the note pitch. Closed / open hat — short and long DECAY (for example, a `DEC` lock).

- **Drums** (KICK, SNARE, METAL, PERC, CLAP, HAT): Attack, Sustain, Release are gray; length is set by DECAY. Always mono per track: a new note restarts the voice without a click (choke) — open and closed hats on the same track cut each other off.
- **TONE and CHORD:** Attack, Sustain, Release come from the shared parameters; Decay is always gray for FM — DECAY replaces it. Mode and Glide work only for TONE; CHORD is mono, the whole chord in one voice.
- **The note** sets the machine's pitch relative to C-4; Transpose and Fine work as for CHIP. PREVIEW plays note C-4.
- The LFO phase (with Retrig ON) resets on every new note except legato: TONE in MONO and CHORD (always mono, overlapping notes play legato).

### DRUM (808 / 909)

**DRUM** — 16 "analog" machines in the spirit of the TR-808 and TR-909, with their own synthesis (tones with a pitch envelope, a click, "metal" from 6 squares, filtered noise, drive). The same 5 macro slots as FM and the same `DEC`, `COL`, `SHP`, `SWP`, `CON` locks, but each machine has its own slot names (table below). A slot that does nothing is shown as a gray "-". All values are 0–127; DECAY is a number too — its range differs between machines.

- All machines are one-shot and mono per track: a new note cuts off the previous one without a click (choke); note length and note-off don't matter. Attack, Decay, Sustain, Release, Mode and Glide are gray.
- **Note** C-4 plays the machine's base pitch, other notes are relative to it (tones and metal; clap noise does not depend on the note). Transpose and Fine work as for CHIP.
- Closed / open hat — short and long DECAY (for example, a `DEC` lock); on the same track they cut each other off.
- Changing the machine sets its default macro values. When switching Type to FM or DRUM, the machine and macros are reset as well: the slots mean different things in each.
- FM, DRUM and SYNTH with a wavetable (at least one oscillator in WT mode) together play no more than 8 voices: a ninth steals the oldest of them (releasing ones first); CHIP, SAMPLE and SYNTH without WT are not affected.
- The timbres are approximations. On the 909 the hats and cymbals are samples in the original; here they are synthesized: a different inharmonic frequency set and more noise.

| Machine | Pitch at C-4 | DECAY | 2 | 3 | 4 | 5 |
|---|---|---|---|---|---|---|
| BD8 | 55 Hz | decay, 5 ms … 4 s | TONE: click | DRIVE | SWEEP: pitch drop up to 12 st | TIME: drop time 5–100 ms |
| SD8 | 180 + 330 Hz, noise HP 1.8 kHz | tone decay | TONE: low / high tone balance | SNAPPY: noise level | SWEEP: up to 7 st | N.DEC: noise length 0.3–2 × DECAY |
| TOM8 | 110 Hz | tone decay | NOISE: noise amount | DRIVE | SWEEP: up to 7 st | TIME: 10–200 ms |
| CP8 | noise, BP | tail | FREQ: 600–2500 Hz | SPREAD: 3 claps, spacing 6–14 ms | Q: 1–6 | TAIL: tail level |
| RS8 | 500 + 1700 Hz | 10–120 ms | TONE: tone balance | NOISE: noise click | SWEEP: up to 5 st | \- |
| CL8 | 2.5 kHz | 10–120 ms | TONE: ±1 octave | DRIVE | SWEEP: up to 3 st | \- |
| CB8 | 540 + 800 Hz (squares) | decay | FREQ: BP 1.5–4 kHz | BAL: 540 ↔ 800 Hz | ACCENT: peak at the start of the hit | \- |
| HH8 | 808 metal (205–800 Hz) | 20 ms … 2 s | HP: 4–12 kHz | NOISE: metal ↔ noise | SPREAD: frequency spread ×0.8–1.25 | N.DEC: noise length 0.3–1.5 × DECAY |
| CY8 | 808 metal × 0.7 | 0.3–4 s | HP: 2–8 kHz | NOISE | SPREAD | N.DEC |
| BD9 | 50 Hz | decay, 5 ms … 4 s | ATTACK: beater click | DRIVE | SWEEP: up to 24 st | TIME: 10–80 ms |
| SD9 | 190 + 345 Hz, noise HP 1 kHz | tone decay | TONE | SNAPPY | SWEEP: up to 7 st | N.DEC |
| TOM9 | 120 Hz | tone decay | NOISE | DRIVE | SWEEP: up to 12 st | TIME: 10–200 ms |
| CP9 | noise, BP | tail | FREQ: 800–3000 Hz | SPREAD: 4 claps | Q | TAIL |
| RS9 | 1700 + 3400 Hz | 10–80 ms | TONE | NOISE | SWEEP: up to 5 st | \- |
| HH9 | 909 metal | 20 ms … 2 s | HP: 6–14 kHz | NOISE | SPREAD | N.DEC |
| CY9 | 909 metal × 0.6 | 0.4–4 s | HP: 3–10 kHz | RIDE/CR: ride (lower metal) → crash (brighter noise) | SPREAD | N.DEC |

Columns 2–5 are the COLOR, SHAPE, SWEEP, CONTOUR slots (locks `COL`, `SHP`, `SWP`, `CON`); the first slot is always DECAY (`DEC`). "st" means semitones. In the LFO dest list for DRUM the slots use the generic names DECAY…CONTOUR.

### SYNTH: oscillators and wavetables

**SYNTH** — an "analog" synthesizer: 2 oscillators, a sub-oscillator, noise, hard sync and a dedicated envelope on SHAPE, followed by the shared ADSR, [filter and LFO](#filter). Each oscillator's mode: **SAW**, **SQR**, **TRI** — classic alias-free waveforms (PolyBLEP), or **WT** — a wavetable (64 frames of 256 points, the frame position is SHAPE). The amplitude envelope is Attack, Decay, Sustain, Release from the ENV page; Mode (POLY / MONO) and Glide work as for CHIP. A SYNTH with a wavetable (at least one oscillator in WT) shares the limit of 8 "heavy" voices with FM and DRUM; a SYNTH using only SAW / SQR / TRI is light and has the whole pool of 16 available.

SYNTH has 6 pages: **MAIN**, **ENV**, **OSC**, **MOD**, **FILT**, **LFO**. When Type is changed to another type, the MOD page becomes the type page.

| Parameter | Values | Default | Meaning |
|---|---|---|---|
| **OSC page** | | | |
| Osc1 / Osc2 | SAW, SQR, TRI, WT | SAW | Oscillator mode. When switching to WT without a table, the first built-in one, `*SAWSQR`, is set. |
| Table1 / Table2 | table name or "-" | — | The oscillator's table in WT mode (in other modes the row is gray). Click or tap — [table selection](#wtpick). A red name means the table is neither in flash nor in the project folder: the oscillator is silent. |
| Shape1 / Shape2 | 0–127 | 0 | Macro **SHP1** / **SHP2**. For SQR — pulse width 50 → 95%; for WT — table frame 0 → 63 (smooth crossfade between frames). For SAW and TRI the row is gray. |
| Semi2 | −24…+24 | 0 | Osc 2 offset in semitones. |
| Detune | −50…+50 cents | 0 | Macro **DET** (0–127, center 64 = 0): osc 2 detune. |
| Sync | OFF / ON | OFF | Hard sync: osc 2's phase is reset on every period of osc 1. Pitch is set by osc 1, timbre by osc 2's Semi2 and Detune (the classic sync lead). For SAW and SQR the discontinuity is smoothed; for WT there is no correction (slight aliasing possible); osc 2 in TRI mode does not accept sync. |
| Mix | 0–100% | 0% | Macro **MIX**: 0% — osc 1 only, 100% — osc 2 only. |
| **MOD page** | | | |
| Sub | 0–127 | 0 | Sub-oscillator level: a square below osc 1. 0 — off (Sub oct is gray). |
| Sub oct | −1 / −2 | −1 | How many octaves the sub is below osc 1. |
| Noise | 0–127 | 0 | White noise level. |
| Env\>Shp | −64…+63 | 0 | Macro **SENV**: envelope depth on SHAPE of both oscillators (± the full range at its peak). 0 — no envelope (Env atk and Env dec are gray). |
| Env atk | 0 ms … 10 s | 0 ms | SHAPE envelope rise. |
| Env dec | HOLD, 1 ms … 10 s | 18 ms | SHAPE envelope decay. HOLD — stays at the peak. |

On the right of the OSC page is the waveform of the oscillator under the cursor (OSC1 or OSC2): a pulse with the current width, triangle, saw, or the table frame at the current SHAPE. The SHAPE envelope and oscillator phases restart on every new note except legato (MONO with overlap) — like the filter envelope.

**Macros and p-locks.** SYNTH has 5 macros in the same slots as FM and DRUM, so the fx locks [DEC…CON](#synthfx) and the LFO destinations work. In the FX column the names are generic; in INST and in LFO dest they have their own names:

| fx | SYNTH macro | LFO dest | What it changes |
|---|---|---|---|
| `DEC` | SHP1 | SHP1 | pulse width (SQR) or frame (WT) of osc 1 |
| `COL` | SHP2 | SHP2 | the same for osc 2 |
| `SHP` | MIX | MIX | osc 1 ↔ osc 2 balance |
| `SWP` | DET | DET | osc 2 detune, ±50 cents (64 = 0) |
| `CON` | SENV | SENV | SHAPE envelope depth (64 = 0) |

A lock on a step with a note applies to that note; on a step without a note — to the track's sounding note until the next note. An LFO on SHP1 / SHP2 gives PWM or wavetable "scanning".

### Wavetables

A table is 64 frames of 256 points (one period per frame). In flash it is stored with mipmaps: 8 levels with a decreasing number of harmonics (128, 64, 32…); the level is chosen by note pitch, so high notes play without aliasing. One table in flash takes 96 KB, in the same partition as samples (shared cache and eviction, see [SAMPLES](#samples)).

**Built-in tables** (names with an asterisk) are always available, without a card and without importing. They are generated in flash on the firmware's first start (≈ 770 KB, a few seconds) and are never evicted:

| Name | Frame 0 → frame 63 |
|---|---|
| `*SAWSQR` | saw → square (even harmonics fade out) |
| `*PWM` | pulse 50% → 5% |
| `*SINSAW` | sine → saw (harmonics come in one by one) |
| `*TRISQR` | triangle → square |
| `*FORMANT` | fundamental + a formant sweeping across harmonics 2–32 |
| `*ORGAN` | organ "drawbars" (harmonics 1, 2, 3, 4, 6, 8) with rotating levels |
| `*SYNC` | hard-sync saw, ratio 1 → 8 |
| `*BELL` | FM 1:3, index 0 → 4 (bell) |

**Table selection.** A click or tap on the Table1 / Table2 row opens a list over the whole tab area: built-in tables, then project tables, and the last row is **IMPORT…**. On the right is frame 0 of the table under the cursor.

| Input | Action |
|---|---|
| Turn, tap a table | The table is set on the oscillator immediately and plays C-4 (audition; a new table sounds from the next note). |
| Click, **OK** button | Keep the selection and close. |
| **CANCEL** button, long press | Restore the previous table. |
| **IMPORT…** | The `/wavetables` list: folders first (up to 4 levels), then `.wav` files; the `..` row goes up (from the root — back to the table list). Click or tap a file — import with progress, toast "IMPORTED name", the table is set on the oscillator. Buttons **OPEN** and **BACK**. |

- **Library on the card:** `/wavetables` (created automatically), subfolders up to 4 levels are allowed. Files are copied with a card reader or over [Wi-Fi](#wifi). Importing does not copy the file: the table goes into the project folder when you save.
- **Formats:** WAV PCM 8 / 16 / 24 bit, mono or stereo (mixed down to mono); the sample rate in the header doesn't matter. The frame layout is detected by length:
  - **WaveEdit** and similar — frames of 256 points, up to 64 frames (up to 16,384 samples);
  - **Serum / Vital** — frames of 2048 points (or the size from the `clm` chunk), up to 256 frames; each frame is reduced to 256 points.

  More than 64 frames — 64 are taken evenly; fewer — the missing frames are smoothly interpolated. DC offset is removed from each frame, and the table is peak-normalized. If the length fits no layout — "UNSUPPORTED WAV"; silence — "NOT A WAV FILE".
- **Name** of the table — the file name without extension (up to 16 characters, A–Z a–z 0–9 \_ -). If the project already has a table with this name and different data, the new one gets a suffix `-2`, `-3`…; the same data under the same name — the existing one is used. Up to 32 tables per project ("TABLE LIST FULL").
- **Project:** Save writes the tables selected in instruments to `/projects/name/wt/<table>.wav` (mono, 16 bit, 64 × 256); tables not used by any instrument are removed from the project. Load pulls missing tables from this folder into flash; if the file is missing or holds different data, the table is absent (name red, oscillator silent) and counts toward "N SAMPLES MISSING".
- **A SYNTH preset** stores table names. If a table is neither built-in nor in the project, loading the preset imports it from `/wavetables/<name>.wav` (only from the root and only with playback stopped); otherwise the name stays red.

> Importing a table writes to flash and works only with playback stopped ("STOP PLAYBACK FIRST"). Selecting an already imported or built-in table works during playback too.

### Filter and LFO

The FILT and LFO pages exist for all types. Voice chain: sound → **Drive** → **Bit crush** → **Downsample** → filter. The filter is a 12 dB/oct SVF after the whole voice (for FM and DRUM — after their own sound).

| Parameter | Values | Default | Meaning |
|---|---|---|---|
| Drive | OFF, 1–127 | OFF | Saturation (tanh) before the filter: the higher it is, the denser the sound and the louder the quiet parts. Lock — fx `DRV`, LFO destination — DRIVE. |
| Bit crush | OFF, 1–127 | OFF | Bit depth reduction: from 16 bits (1) to 2 bits (127); the number in brackets is how many bits remain. Step lock — fx `BIT`. |
| Downsample | OFF, 1–127 | OFF | Sample rate reduction: each sample is held for up to ~64 samples at 127, the sound becomes "digital" and ringing. Step lock — fx `SRR`. |
| Filter | OFF, LP, BP, HP | OFF | Mode. OFF — bypass: the sound is as without a filter, the other filter rows are gray. |
| Cutoff | 20 Hz … 14 kHz (128 values, exponential) | 14 kHz | Cutoff frequency. Lock — fx `FLT`. |
| Reso | 0–127 | 0 | Resonance (Q 0.5–20). High resonance is loud — lower the Volume. Lock — fx `RES`. |
| Flt env | −64…+63 | 0 | Filter envelope depth: ±6 octaves at its peak. 0 — no envelope (attack and decay are gray). |
| Flt attack | 0 ms … 10 s | 0 ms | Envelope rise. |
| Flt decay | HOLD, 1 ms … 10 s | 18 ms | Envelope decay (exponential). HOLD — the envelope stays at the peak. |
| Key track | 0–100% | 0% | Cutoff follows the note from C-4: 100% — one octave per octave. |
| LFO | 1–4 | 1 | Which of the instrument's four LFOs the rows below edit; the number in brackets is how many are on. All four run at once; their effects on the same destination add up (VOL — multiplies). |
| Wave | SINE, TRI, SAW, SQR, RND | SINE | LFO shape; RND — a random value each period. |
| Sync | FREE / TEMPO | FREE | TEMPO — the rate is set as a fraction of a bar and follows the project BPM. |
| Retrig | ON / OFF | ON | ON — the LFO phase restarts on every new note (except legato). OFF — one phase per instrument, shared by all its voices and all tracks playing it: a note lands in the running phase. With FREE the LFO runs continuously; with TEMPO it restarts when playback starts, so a 1 BAR LFO always begins at the start of the bar and every run sounds the same. RND with OFF gives one shared value per period. |
| Rate | 0.05–30 Hz or 1/32 … 8 BARS | ≈ 1.3 Hz | Rate: in FREE — an exponential Hz scale; in TEMPO — 1/32, 1/16T, 1/16, 1/8T, 1/8, 1/4T, 1/4, 1/2, 1, 2, 4, 8 bars per period. |
| Depth | −64…+63 | 0 | Depth; 0 — LFO off (then wave, sync, retrig, rate and dest are gray). Full depth: PITCH ±12 semitones, VOL ±100%, CUTOFF ±64 Cutoff steps (≈ ±4.8 octaves), macro ±64; RESO, FENV, DLY, RVB, BIT, SRR, SUB, NOISE ±64 steps; FINE ±1 semitone; DUTY ±49%; SEMI2 ±24 semitones; L1–L4 RATE ×/÷16; L1–L4 DEPTH 0…×2. |
| Dest | PITCH, DECAY, COLOR, SHAPE, SWEEP, CONTOUR, VOL, CUTOFF, DRIVE, RESO, FENV, DLY, RVB, BIT, SRR, FINE, DUTY, SUB, NOISE, SEMI2, L1–L4 RATE, L1–L4 DEPTH, L1–L4 RTRG | PITCH | Destination. DECAY…CONTOUR (macros) — only for FM, DRUM and SYNTH (for SYNTH they are called SHP1, SHP2, MIX, DET, SENV); DUTY — only for CHIP; SUB, NOISE and SEMI2 (oscillator 2) — only for SYNTH. Other types skip targets they lack; changing Type turns a missing target into PITCH. CUTOFF acts when the filter is on. DRIVE — ±64 Drive steps at full depth. RESO, FENV, DLY, RVB, BIT, SRR, SUB, NOISE shift Reso, Flt env, Dly send, Rvb send, Bit crush, Downsample, Sub, Noise; FINE — fine pitch; DUTY — the PULSE Duty; L1–L4 — another LFO of the instrument (see below). |

- The filter envelope (and the LFO phase with Retrig ON) restart on every new note except legato (MONO with overlap, FM CHORD): there the envelope keeps running, like on a 303.
- Cutoff = Cutoff (or FLT lock) + envelope + Key track + LFO CUTOFF, limited to 20 Hz … 14 kHz.
- Old projects load with Filter OFF and sound as before.

**LFO to LFO.** An LFO can modulate another LFO of the same instrument. **L1–L4 RATE** speeds up / slows down the target: its rate × 2^(±4), ≈ ×/÷16 at full depth, in FREE and TEMPO. **L1–L4 DEPTH** scales the target's depth: × (1 + value), limited to 0…2 — −64 silences the target, +63 nearly doubles it. **L1–L4 RTRG** restarts the target at phase 0 on each cycle of the source (RND gets a new value); only depth ≠ 0 matters, its amount doesn't. An LFO can't pick its own RTRG. Modulation reaches the target with a 1 ms lag, so any routing works, loops included. A Retrig OFF target (one phase per instrument) takes RATE and RTRG only from Retrig OFF LFOs — a per-voice LFO has no single phase to give; DEPTH works from any LFO. While playback is stopped, a TEMPO + Retrig OFF target holds and ignores restarts.

### KIT (drum kit)

**KIT** — a set of 8 lanes for a [drum track](#drumtrack). It makes no sound on its own: each lane is either its own mini-sampler on a project sample or a reference to one of the 16 instruments. There are two pages: **MAIN** (Name, Type, Dly send — the delay send for the whole kit) and **LANES** — a scrolling list of lanes.

| Row | Values | Meaning |
|---|---|---|
| L1…L8 Src | SAMPLE / INST | Lane source. Rows for the other mode are hidden. |
| Sample | --- or a project sample | SAMPLE: what the lane plays. Red — the sample is not in flash (the lane is silent). |
| Volume | 0–127 | SAMPLE: lane volume. |
| Pitch | −24…+24 | SAMPLE: offset in semitones from the sample's original pitch. |
| Decay | FULL, 1 ms … 10 s | SAMPLE: FULL — the sample plays to the end, otherwise it fades out over this time. |
| Instr | INS1…INS32 | INST: the lane's instrument (with its own parameters, macros, filter). A KIT inside a KIT is silent and shown in red. Selecting a SAMPLE instrument sets the lane's Note to its Root. |
| Note | 0–127 | The lane's note: sent to MIDI on a MIDI track, and used by the lane to play its INST instrument. Lanes in a kit have different notes — turning skips taken ones. Default C-4…G-4. |

- Each lane is mono: a repeated hit cuts off its own previous one (choke); different lanes sound at the same time — up to 8 voices per track.
- PREVIEW plays a lane with note C-4 (the first one by default).
- KIT has factory presets only: **PRESET** opens Load straight away, `[FACTORY]` → KIT. A factory kit fills the lanes and writes its drums (factory DRUM / FM / CHIP presets) into **INS25…INS32**, or INS17…INS24 when the kit itself is in INS25…INS32; lane k plays note C-4 + k. Whatever was in those slots is overwritten on OK (CANCEL brings them back). Your own KIT presets cannot be saved yet.
- Renaming a sample in FILE → SAMPLES also updates the lanes; Delete leaves the name in the lane (the lane is silent, like MISSING) and asks for confirmation if the sample is used in a lane.

### Presets

The **PRESET** button in the INST header (or <kbd>Shift</kbd>+long press of the encoder) opens a **Load** / **Save** menu (on a KIT — Load right away), then a preset browser that fills the whole tab. A preset is the entire instrument: type, parameters, filter, LFO, machine and macros, slices and their modes, SYNTH oscillators and wavetable names, and the name.

**Browser header:** the path and three buttons (Save: the type, then the path inside the type folder). Load always opens at the top: a `[FACTORY]` row, then a folder per type (FM, SYNTH, DRUM, SAMPLE, CHIP) with your own folders (`name/`) and files; inside a folder the first row is `..` (up one level). `[FACTORY]` holds the factory presets built into the firmware, by type (including KIT) and category; they cannot be changed or deleted. A preset of another type changes the instrument's type. Save opens in the folder of the instrument's type.

| Input | Load | Save |
|---|---|---|
| Turn | Row; the preset under the cursor is applied to the instrument at once and plays C-4 (audition, marked `>`). | Row. |
| Tap on a preset | Audition (same as turning). | Write over it (asks Overwrite). |
| Click on a preset | Take it and close. | Write over it (asks Overwrite). |
| Click / tap on a folder | Enter; `..` goes up. | |
| Buttons | **OK** keeps the selected preset, **DEL** deletes your own preset under the cursor (with confirmation), **CANCEL** restores the instrument as it was. | **SAVE**: name on the keyboard (defaults to the instrument name; if the file exists, asks Overwrite), **+DIR**: new folder inside the current one, **CANCEL**: close. |
| Long press of the encoder | Same as CANCEL. | Close. |

- **Load** changes the instrument immediately; CANCEL brings the previous one back. Auditioning works during playback too: tracks using this instrument play with the new sound.
- **Save** always writes to the folder of the instrument's type; `[FACTORY]` is not shown. File name: up to 16 characters, A–Z 0–9 \_ -; the first 8 characters also become the instrument name.
- A **SAMPLE preset** stores the sample name. If that sample is in the project, it is applied together with the preset's Root and slices; otherwise the instrument's sample, Root and slices stay as they were. The Slices, Chop and Chop N / Sens modes are always taken from the preset. There are no factory SAMPLE presets.
- A **SYNTH preset** stores the oscillator wavetable names: built-in tables are always available, a project table is matched by name, and a missing one is imported from `/wavetables` (see [wavetables](#wavetables)). Factory SYNTH presets use only built-in tables.
- **Format:** presets are saved in v3 format, including slices and SYNTH parameters; older presets (v1, v2) load as before.
- **Folders:** up to 4 levels inside a type folder (deeper gives "TOO DEEP").
- Without a card, Load shows only `[FACTORY]` and Save does not open ("NO SD CARD").

| Type | Category | Factory presets |
|---|---|---|
| CHIP | LEAD | SQ LEAD, ARP PLK |
| CHIP | BASS | TRI BASS, ACID |
| CHIP | PAD | PWM PAD, WT PAD |
| CHIP | KEYS | WT BELL |
| CHIP | PERC | NOIS HH, NOIS SN, METALBL |
| FM | DRUMS | KICK, SNARE, CLAP, HAT C, HAT O, WOODBLK |
| FM | KEYS | BELL, E.PIANO, CHORD M7 |
| FM | BASS | FM BASS |
| DRUM | 808 | BD808, BD808 L, SD808, CH808, OH808, CP808, CB808 |
| DRUM | 909 | BD909, SD909, CH909, OH909, CP909 |
| SYNTH | BASS | BASS, ACID, SUBBASS |
| SYNTH | LEAD | LEAD, SYNCLD |
| SYNTH | PAD | PAD, PWMSTR, WTSWEEP |
| SYNTH | KEYS | PLUCK, BELL |
| KIT | DRUM | 808 KIT, 808 DEEP, 909 KIT, 909 HARD, LOFI KIT, HARD KIT |
| KIT | FM | FM KIT, FM PUNCH, FM PERC |
| KIT | CHIP | CHIP KIT |
| KIT | MIX | HYBRID, DUB KIT |

## PROJ: project and pattern

Five pages: **SONG** (tempo, scale, pattern, groove), **FX** (delay, reverb, DJ filter), **COMP** (compressor, sidechain), **PERF** (button effects), **SYS** (Phones, Preview, theme, autosave, version). Switch pages as in TRACK and FILE: tap a page tab, or put the encoder on the page tabs and click (<kbd>Shift</kbd>+click goes back).

| Parameter | Values | Scope |
|---|---|---|
| **SONG** | | |
| BPM | 20–300 | project |
| Scale root | C…B | project |
| Scale | 13 scales | project |
| Length | 4–128 | playing pattern |
| Resolution | 1/4, 1/8, 1/16, 1/32, 1/8T, 1/16T | playing pattern |
| Swing | 50–75% | playing pattern (grayed out when a Groove is selected) |
| Groove | OFF, MPC 54/58/62/66, SHUFFLE, PUSH, LAID BACK, DRUNK, BOOM BAP, HOUSE | playing pattern: a template of timing offsets and accents for every 16 steps, used instead of swing. MPC: sixteenth-note swing with accents; SHUFFLE: triplet feel; PUSH: off-beats slightly early; LAID BACK: slightly late; DRUNK: uneven (the same on every pass); BOOM BAP: hip-hop; HOUSE: accent on the off-beats. OFF: Swing applies. |
| **FX** | | |
| Delay | 1/16–16/16, default 3/16 | project: [delay](#delay) time in sixteenths, follows the tempo |
| Feedback | 0–127, default 50 | project: how much of the echo is fed back for repeats; 0 is a single echo, 127 a long tail (it always decays) |
| Tone | 0–127, default 90 | project: echo brightness (low-pass 300 Hz … 16 kHz, 127 is unfiltered); each repeat is darker than the previous one |
| Dly level | 0–127, default 100 | project: echo volume; 0 turns the delay off (the rows above are grayed out) |
| Reverb | 0–127, default 60 | project: [reverb](#reverb) size, i.e. tail length |
| Rvb damp | 0–127, default 70 | project: high-frequency damping in the tail (higher is darker) |
| Rvb level | 0–127, default 80 | project: reverb volume; 0 turns it off |
| DJ filter | LP 64 … OFF … HP 63 | project: a filter on all internal sound, before the compressor. Turning left closes a low-pass (20 kHz → 100 Hz), turning right opens a high-pass (20 Hz → 8 kHz), with a little resonance. Handy for live tweaking. |
| **COMP** | | |
| Comp | OFF, 1–127, default OFF | project: [compressor](#comp) on all internal sound; higher means a lower threshold (−6 … −30 dB) |
| Comp rel | 20 ms … 1 s, default ≈ 90 ms | project: compressor release |
| SC track | OFF, T1–T16, default OFF | project: sidechain key track: its sound ducks the whole mix |
| SC depth | 0–127, default 64 | project: sidechain amount |
| **PERF** | | |
| Button 1 … Button 8 | [PERF](#live) effects or --- | project: what track button N holds in PERF mode |
| **SYS** | | |
| Phones | 0–100%, default 100% | device: live output level (headphones / speaker), attenuation only; not in Render WAV, the project's master is MIX → MAIN. Stored in the board's memory one second after a change |
| Preview | ON / OFF, default ON | project: entering a note in GRID on an INT track sounds it immediately |
| Theme | 17 themes, default CLASSIC | device: interface colors (see below) |
| Autosave | OFF, 1, 2, 5, 10 min, default 5 | device: [autosave](#file) interval |
| Firmware | build commit | display only: firmware version ("+" means built with local changes) |
| Last reset | POWER ON, SOFTWARE, PANIC, WATCHDOG, BROWNOUT… | display only: reason for the last reboot (crashes are logged to crashlog.txt) |
| Audio RAM | INTERNAL / SYNTH IN PSRAM / SEQ IN PSRAM, RVB INT / PSRAM, free K | display only: the synth and sequencer should be in internal memory; in PSRAM, audio costs noticeably more CPU. The reverb buffer goes into internal memory if 24 KB remain free after it; while Wi-Fi is on it moves to PSRAM |
| CPU profile | CLICK TO START / RUNNING | diagnostics: click to start, click again and the audio time broken down by part (queue, events, voice management, voices by type, delay, reverb, master) is appended to /diag/cpuprof.txt |

**Themes.** They change as soon as you turn the encoder. The choice is a device setting, like MAIN volume: it is stored in the board's memory after a second (when the transport is stopped); the project and file are not changed. Themes: CLASSIC (the original), AMBER and PHOSPHOR (monochrome terminals), NORD, DRACULA, SOLARIZED, GRUVBOX, MONOKAI, TOKYO, MOCHA, ROSE PINE (inspired by well-known editor palettes), GAMEBOY, C64 (retro), SYNTHWAVE, OCEAN, CONTRAST (maximum contrast) and PAPER (light).

**Reverb** is a shared mono reverb (4 comb filters and 2 allpasses, like Freeverb). Instruments send to it with the Rvb send parameter, steps with the RVB fx. Delay echoes do not go into the reverb. Changing the size on the fly jumps.

The **compressor** sits on the sum of the internal sound after the delay and reverb, before the master volume: 4:1, 1 ms attack; Comp sets the threshold and the makeup gain (half of the threshold reduction). **Sidechain:** SC track = the kick track, Comp 60–100, SC depth 100+, and the whole mix ducks on every hit ("pumping"); Comp rel sets how fast it comes back. The key is that track's internal sound (INT); the track itself plays as usual. Comp OFF: the compressor leaves the sound untouched.

**Delay** is a single shared mono delay for the internal sound (it does not affect the MIDI output). Instruments send sound to it with the Dly send parameter, individual steps with the DLY fx. The time is synced to BPM: 1/16 at 120 BPM = 125 ms. The line is sized for 4 s, i.e. 16/16 down to 60 BPM; at slower tempos the time is capped at 4 s. Changing the time or tempo on the fly jumps (a click on the tail is possible). On stop, the echo rings out.

**Scales:** Chromatic, Major, Minor, Dorian, Phrygian, Lydian, Mixolydian, Locrian, Harmonic minor, Melodic minor, Pentatonic major, Pentatonic minor, Blues. The default is C Chromatic, i.e. no restriction.

**How the scale works.** Notes are not filtered; the scale defines the scale degrees. These move by scale degree: note entry with the encoder, Transpose in SCALE mode, NRN, CHD and Fill (RAMP and RANDOM for notes). An out-of-scale note is first snapped to the nearest lower scale note on the first move. Octave shifts and the mini keyboard ignore the scale. Changing the scale does not rewrite notes already entered.

**Swing** delays every second step: 75% means by half a step.

## BANK: pattern bank

A 4×4 grid of tiles: patterns P01–P16. Each tile shows the number, length, resolution and 16 small squares in two rows (tracks 1–8 on top, 9–16 below): a filled square means the track has data.

- The playing pattern is filled with a yellow border. A queued one has a blinking double border. A copy source has a red border.

| Input | Action |
|---|---|
| Tap / click | **Queue**: during playback switches at the end of the pass, when stopped switches at once. |
| <kbd>Shift</kbd>+tap / click | **Immediately**: switches from the next step, keeping the position. |
| Long tap / press | Pattern menu. |
| Turn | Select a tile. |

**Pattern menu:**

- **Copy to…**, then tap the target tile. Everything is copied: steps, length, resolution, swing. Tapping the same tile cancels.
- **Clear**, with confirmation. Also resets length (16), resolution (1/16), swing (50).
- **Length 16 / 32 / 64**: quick length change.
- **Song mode**: turns on song mode.

Any pattern change clears TIE. The pass counter is reset.

## Song mode

A chain of up to 64 entries. An entry is a pattern, a transposition, a number of passes and a mute scene. To turn it on: tile menu → **Song mode**. In song mode the BANK tab shows the chain list instead of the tiles.

- Header: `SONG n/64`, the **+ ADD** button (append the playing pattern at the end) and **SONG OFF**.
- Row: `>` next to the playing entry, the number and four fields, `P05 +3 x2 S1`: pattern, transposition, passes, scene; default values (`+0 x1 S-`) are gray. On the right, the pattern's length and resolution.
- Turn to select a row. Click to edit the row: turning or dragging changes the field (red), <kbd>Shift</kbd>+turn selects the field. Tapping a field of the selected row edits that field directly. On an empty chain, a click adds the playing pattern.
- **Transposition** −24…+24 semitones: notes on melodic tracks sound shifted while the entry plays (clamped to 0 and 127). Drum tracks, OFF and the pattern's steps themselves are not changed.
- **Passes** x1…x16: how many times to play the pattern before the next entry. Repeats sound like a loop: TIE and the CND counter carry on.
- **Scene** S1…S8: when the entry starts, track mutes are set from the scene (an empty scene changes nothing). `S-`: leave as is.
- **Scenes**: 8 tiles `S1…S8` below the list. Tap to recall (mute all tracks as in the scene), long tap to store the current mutes, <kbd>Shift</kbd>+tap to clear. A filled tile is highlighted; one matching the current mutes has a yellow border. Scenes are stored in the project.
- Long press opens the row menu: **Insert Pxx before**, **Delete**, **Duplicate**, **Append Pxx**, **Song mode off**. Pxx is the playing pattern.

### How the song plays

- Playback starts from the first entry. At the end of a pass, the next entry follows; after the last one, the first one again.
- Turning the mode on during playback: the chain starts at the end of the current pass. Turning it off: the current pattern keeps looping.
- Chain edits during playback are picked up at the end of the pass. Inserting or deleting a row above the playing one does not disturb the position.
- Two identical entries in a row sound as a repeat: TIE and the CND counter are kept.
- Editing the passes during playback is picked up if the decision to move on has not been made yet. Deleting the playing entry: the next one starts at the end of the pass.
- An empty chain plays the current pattern, as without song mode.
- Pattern queueing does not work in song mode; the tiles are unavailable.
- When stopped, GRID shows and edits the first entry of the chain, and the status bar shows `S01`.

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

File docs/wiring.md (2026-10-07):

# Tracker wiring diagram

Everything you solder to the WT32-SC01 Plus: battery power, MIDI OUT, the encoder, Play and Shift, eight track buttons with LEDs, and a headphone jack. The display, touch and microSD are already routed on the board.

Русская версия: [wiring_ru.md](wiring_ru.md)

## Schematic

Overview: LiPo through IP5306 and the power switch feeds the board 5 V; GPIO10 through 10 Ω to the MIDI jack Tip, 3.3 V through 33 Ω to Ring; encoder on GPIO 11, 12, 13; Play on 14, Shift on 21; PCF8575 on GPIO 43 and 44 of the Debug connector, with eight buttons and eight LEDs.

- red — power (5 V from the IP5306, 3.3 V from the board)
- black (white in dark mode) — GND
- blue — signal to a GPIO
- green — button
- orange — LED cathode

*Every ground symbol is a wire to the board's common GND; every "3.3 V" flag goes to the board's 3V3 pin. All board inputs use internal pull-ups, so the buttons and encoder need no external resistors. The PCF8575 block with the track buttons is optional: the firmware works without it.*

## Connection table

| From | To | Notes |
|---|---|---|
| **Power** | | |
| `LiPo + / −` | `IP5306 B+ / B−` | 103450 battery with a protection board |
| `IP5306 VOUT` | `switch → board 5V` | VOUT and GND are the pads of the desoldered USB-A port |
| `IP5306 GND` | `board GND` | |
| **MIDI OUT** | | |
| `board IO10` | `10 Ω → Tip` | MIDI DIN pin 5 |
| `board 3V3` | `33 Ω → Ring` | MIDI DIN pin 4 |
| `board GND` | `Sleeve` | MIDI DIN pin 2, shield |
| **EC11 encoder and buttons** | | |
| `board IO11 / IO12` | `encoder A / B` | outer pins of the group of three; turns the wrong way — swap them |
| `board GND` | `encoder C` | middle pin of the group of three |
| `board IO13` | `shaft button` | the shaft button's other pin goes to GND |
| `board IO14` | `Play button` | other pin to GND |
| `board IO21` | `Shift button` | other pin to GND |
| **Headphones (optional)** | | |
| `SPK+ connector` | `150 Ω → Tip` | left ear |
| `SPK+ connector` | `150 Ω → Ring` | right ear, its own resistor |
| `SPK− connector` | `Sleeve` | **not GND**: the jack is isolated |
| `SPK+ / SPK− connector` | `speaker + (through a switch) / −`  | 4–8 Ω speaker, switch optional |
| **Track buttons (optional)** | | |
| `board 3V3` | `PCF VCC + 3.3 V rail` | the rail feeds all 8 LED resistors |
| `board GND` | `PCF GND` | do not solder A0, A1, A2: the firmware finds the address 0x20–0x27 itself |
| `Debug TXD0 (IO43) / RXD0 (IO44)` | `PCF SDA / SCL` | Debug connector; 3V3 and GND can be taken from it too |
| `—` | `PCF INT` | leave unconnected: the module is polled every 5 ms |
| `PCF P00 … P07` | `button 1 … 8` | the button's other pin goes to GND |
| `PCF P10 … P17` | `LED 1 … 8 cathode` | anode through its own resistor to 3.3 V |

10 nF capacitors from the encoder's A and B pins to GND are recommended for less bounce. They are not required: the firmware has a filter.

## Power: important

- The switch sits after the IP5306, so the battery charges through the module's Type-C even with the tracker switched off.
- **Flash firmware only with the switch off.** Otherwise two sources meet on the 5V line: the computer's USB and the IP5306.
- Never connect the battery directly to the board's 5V or 3V3 — only through the IP5306.
- The battery, IP5306 and board negatives form the common ground; everything else in the diagram connects to it as well.

## MIDI jack

- TRS pinout **type A**: Tip = pin 5, Ring = pin 4. For type B devices (some Arturia, Novation) use an A→B adapter or swap the Tip and Ring wires.
- For a 5-pin DIN: the same resistors on pin 5 and pin 4, GND on pin 2.

## Headphones

Headphones: SPK+ through two 150 Ω resistors to Tip and Ring of the 3.5 mm jack, SPK− to Sleeve. The speaker is connected in parallel, its plus through a switch. Sleeve is not connected to GND.

- purple — SPK+
- teal — SPK− (not ground)

*The built-in NS4168 amplifier is brought out to the board's SPK connector, so no soldering to GPIOs is needed. The signal is mono, the same in both ears. The switch in the speaker wire is optional: without it the speaker and headphones play together.*

**The SPK output is bridged: neither of its two pins is ground.** The jack's Sleeve goes to SPK−, never to the board's GND. The jack must not touch GND, the MIDI jack body or USB. Plug only headphones into this jack: a cable to a mixer, audio interface or powered speakers would tie SPK− to their ground and short the amplifier output.

- Resistors 100–220 Ω, 0.25 W, one each on Tip and Ring. Below 100 Ω it is loud with high current through the headphones; above that it gets quieter. 150 Ω is the middle ground.
- Mount the jack in a plastic enclosure or a plastic wall: the printed case works.
- The jack's built-in switching contact is no good for cutting the speaker: on ordinary jacks it is tied to Tip, and Tip goes through a resistor. You need a separate switch.
- Power up the first time with PROJ → Volume at minimum and without wearing the headphones.

## Which track button is which

Button layout: Shift, Play and the encoder under the screen; below them buttons 1–4, and 5–8 at the front edge. The bottom view is mirrored: button 1 is on the right.

*Button number = track number = pin number + 1 (button 1 is P00 and P10). While soldering, the lid lies face down, so the left-to-right order is reversed: button 1 ends up on the right.*

## LED polarity

LED: the long leg is the anode, to the resistor and 3.3 V; the short leg on the flat side is the cathode, to pin P1x.

*The LED goes into the window of the MX switch housing, with the legs passing straight through. A reversed LED will not burn out, it just won't light.*

## LED resistors

| LED colour | Drop | Resistor | Current |
|---|---|---|---|
| red, yellow, orange | `≈ 2.0 V` | `330 Ω` | `≈ 4 mA` |
| green (yellow-green) | `≈ 2.1 V` | `330 Ω` | `≈ 3.5 mA` |
| white, blue, bright green  | `≈ 2.9–3.1 V` | `47–68 Ω`  | `≈ 3–8 mA` |

With white and blue LEDs at 3.3 V the voltage headroom is only 0.2–0.4 V, and brightness varies noticeably from one LED to the next. Red or yellow with 330 Ω are more reliable. Do not go below 47 Ω: the PCF8575 handles up to 25 mA per pin, but all 8 LEDs together should not draw more than ~80 mA.

## Before powering up

1.  Continuity check: the board's 5V and GND are not shorted; the switch in the "off" position breaks VOUT.
2.  If the headphone jack is fitted: Sleeve has no continuity with the board's GND; Tip and Ring read through 150 Ω to SPK+.
3.  A0, A1, A2 on the module can be left alone. If the module is found only sometimes (the address "floats"), bridge all three pads to GND.
4.  Check whether the module has pull-up resistors on SDA and SCL (usually 4.7–10 kΩ to VCC). If not, add 4.7 kΩ from each line to 3.3 V.
5.  Power the module only from 3.3 V, not 5 V: otherwise 5 V reaches the board's GPIOs.
6.  Check that TXD0 and RXD0 are not shorted to each other or to GND. Do not touch GPIO 1, 2, 42: they are used by the built-in RS485.
7.  After flashing, open the serial monitor: the line `trackio: PCF8575 not found` means the module is not responding — check SDA/SCL and power; `trackio: PCF8575 at 0x..` means it was found.

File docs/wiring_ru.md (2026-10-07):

# Схема пайки трекера

Всё, что паяется к WT32-SC01 Plus: питание от аккумулятора, MIDI OUT, энкодер, Play и Shift, восемь кнопок дорожек со светодиодами, гнездо для наушников. Дисплей, тач и microSD уже разведены на плате.

English: [wiring.md](wiring.md)

## Принципиальная схема

Общая схема: LiPo через IP5306 и тумблер питает плату 5 В; GPIO10 через 10 Ом на Tip MIDI-гнезда, 3,3 В через 33 Ом на Ring; энкодер на GPIO 11, 12, 13; Play на 14, Shift на 21; PCF8575 на GPIO 43 и 44 разъёма Debug с восемью кнопками и восемью светодиодами.

- красная — питание (5 В от IP5306, 3,3 В от платы)
- чёрная (в тёмной теме белая) — GND
- синяя — сигнал на GPIO
- зелёная — кнопка
- оранжевая — катод LED

*Каждый знак «земли» — провод на общий GND платы, флаг «3,3 В» — на вывод 3V3 платы. Все входы платы с внутренней подтяжкой, внешние резисторы к кнопкам и энкодеру не нужны. Блок PCF8575 с кнопками дорожек необязателен: без него прошивка работает.*

## Таблица соединений

| Откуда | Куда | Примечание |
|---|---|---|
| **Питание** | | |
| `LiPo + / −` | `IP5306 B+ / B−` | аккумулятор 103450 с платой защиты |
| `IP5306 VOUT` | `тумблер → плата 5V` | VOUT и GND — площадки выпаянного USB-A модуля |
| `IP5306 GND` | `плата GND` | |
| **MIDI OUT** | | |
| `плата IO10` | `10 Ом → Tip` | MIDI DIN pin 5 |
| `плата 3V3` | `33 Ом → Ring` | MIDI DIN pin 4 |
| `плата GND` | `Sleeve` | MIDI DIN pin 2, экран |
| **Энкодер EC11 и кнопки** | | |
| `плата IO11 / IO12` | `энкодер A / B` | крайние выводы тройки; крутится наоборот — поменять местами |
| `плата GND` | `энкодер C` | средний вывод тройки |
| `плата IO13` | `кнопка вала` | второй вывод кнопки вала — на GND |
| `плата IO14` | `кнопка Play` | второй вывод — на GND |
| `плата IO21` | `кнопка Shift` | второй вывод — на GND |
| **Наушники (необязательно)** | | |
| `разъём SPK+` | `150 Ом → Tip` | левое ухо |
| `разъём SPK+` | `150 Ом → Ring` | правое ухо, свой резистор |
| `разъём SPK−` | `Sleeve` | **не GND**: гнездо изолировано |
| `разъём SPK+ / SPK−` | `динамик + (через выключатель) / −` | динамик 4–8 Ом, выключатель по желанию |
| **Кнопки дорожек (необязательно)** | | |
| `плата 3V3` | `PCF VCC + шина 3,3 В` | шина питает все 8 резисторов LED |
| `плата GND` | `PCF GND` | A0, A1, A2 не паять: прошивка сама найдёт адрес 0x20–0x27 |
| `Debug TXD0 (IO43) / RXD0 (IO44)` | `PCF SDA / SCL` | разъём Debug; 3V3 и GND можно взять с него же |
| `—` | `PCF INT` | не подключать: модуль опрашивается каждые 5 мс |
| `PCF P00 … P07` | `кнопка 1 … 8` | второй вывод кнопки — на GND |
| `PCF P10 … P17` | `катод LED 1 … 8` | анод — через свой резистор на 3,3 В |

Желательно конденсаторы 10 нФ с выводов A и B энкодера на GND — меньше дребезга. Не обязательно: в прошивке есть фильтр.

## Питание: важное

- Тумблер стоит после IP5306, поэтому аккумулятор заряжается через Type-C модуля и при выключенном трекере.
- **Прошивать только с выключенным тумблером.** Иначе на линии 5V встретятся два источника: USB компьютера и IP5306.
- Аккумулятор не подключать напрямую ни к 5V, ни к 3V3 платы — только через IP5306.
- Минусы аккумулятора, IP5306 и платы — общая земля; всё остальное на схеме садится на неё же.

## MIDI-гнездо

- Распиновка TRS **тип A**: Tip = pin 5, Ring = pin 4. Для устройств с типом B (некоторые Arturia, Novation) — переходник A→B или поменять местами провода на Tip и Ring.
- Для 5-контактного DIN: те же резисторы на pin 5 и pin 4, GND на pin 2.

## Наушники

Наушники: SPK+ через два резистора 150 Ом на Tip и Ring гнезда 3,5 мм, SPK− на Sleeve. Динамик подключён параллельно, плюс через выключатель. Sleeve не соединяется с GND.

- фиолетовая — SPK+
- бирюзовая — SPK− (не земля)

*Встроенный усилитель NS4168 выведен на разъём SPK платы, пайка к GPIO не нужна. Сигнал моно, на оба уха одинаковый. Выключатель в проводе динамика необязателен: без него динамик и наушники звучат вместе.*

**Выход SPK мостовой: ни один из двух выводов не земля.** Sleeve гнезда — на SPK−, никогда на GND платы. Гнездо не должно касаться GND, корпуса MIDI-гнезда и USB. В это гнездо — только наушники: кабель в микшер, звуковую карту или активные колонки соединит SPK− с их землёй и замкнёт выход усилителя.

- Резисторы 100–220 Ом, 0,25 Вт, по одному на Tip и Ring. Меньше 100 Ом — громко и большой ток через наушники, больше — тише. 150 Ом — середина.
- Гнездо — в пластиковом корпусе или в пластиковой стенке: печатный корпус подходит.
- Встроенный размыкающий контакт гнезда для отключения динамика не подходит: у обычных гнёзд он соединён с Tip, а Tip идёт через резистор. Нужен отдельный выключатель.
- Первое включение — с громкостью PROJ → Volume на минимуме и не надевая наушники.

## Какая кнопка дорожки какая

Расположение кнопок: под экраном Shift, Play, энкодер; ниже кнопки 1–4, у переднего края 5–8. Вид снизу зеркален: кнопка 1 справа.

*Номер кнопки = номер дорожки = номер вывода +1 (кнопка 1 — P00 и P10). При пайке крышка лежит лицом вниз, поэтому слева направо порядок обратный: кнопка 1 оказывается справа.*

## Полярность светодиода

Светодиод: длинная ножка — анод, к резистору и 3,3 В; короткая ножка со стороны среза — катод, к выводу P1x.

*Светодиод вставляется в окно корпуса свича MX, ножки проходят насквозь. Перевёрнутый светодиод не сгорит, просто не будет светить.*

## Резисторы светодиодов

| Цвет светодиода | Падение | Резистор | Ток |
|---|---|---|---|
| красный, жёлтый, оранжевый | `≈ 2,0 В` | `330 Ом` | `≈ 4 мА` |
| зелёный (жёлто-зелёный) | `≈ 2,1 В` | `330 Ом` | `≈ 3,5 мА` |
| белый, синий, ярко-зелёный | `≈ 2,9–3,1 В` | `47–68 Ом` | `≈ 3–8 мА` |

С белыми и синими при 3,3 В запас по напряжению всего 0,2–0,4 В, и яркость заметно гуляет от экземпляра к экземпляру. Красные или жёлтые с 330 Ом надёжнее. Не меньше 47 Ом: PCF8575 держит до 25 мА на вывод, но 8 светодиодов вместе не должны брать больше ~80 мА.

## Перед включением

1.  Прозвонить: 5V и GND платы не закорочены; тумблер в положении «выкл.» размыкает VOUT.
2.  Если стоит гнездо наушников: Sleeve не звонится с GND платы, Tip и Ring звонятся с SPK+ через 150 Ом.
3.  A0, A1, A2 на модуле можно не трогать. Если модуль то находится, то нет (адрес «плавает»), замкнуть все три площадки на GND.
4.  Посмотреть, есть ли на модуле резисторы подтяжки SDA и SCL (обычно 4,7–10 кОм к VCC). Если нет — поставить 4,7 кОм от каждой линии на 3,3 В.
5.  Питать модуль только от 3,3 В, не от 5 В: иначе на GPIO платы придёт 5 В.
6.  Прозвонить, что TXD0 и RXD0 не закорочены между собой и на GND. GPIO 1, 2, 42 не трогать: они заняты встроенным RS485.
7.  После прошивки открыть монитор порта: строка `trackio: PCF8575 not found` значит, что модуль не отвечает — проверить SDA/SCL и питание; `trackio: PCF8575 at 0x..` — найден.

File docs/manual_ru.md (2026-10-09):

# D-TRK — руководство

Трекер со встроенным синтезатором на WT32-SC01 Plus: 16 дорожек, банк из 16 паттернов, цепочка песни, Fill с Euclid и генератором арпеджио, импорт MIDI-файлов. Каждая дорожка играет во встроенный синтезатор (FM, драм-машины 808 / 909, синтезатор с wavetable, сэмплер, chiptune) на динамик платы или во внешний MIDI. Управление — сенсорный экран, энкодер и две кнопки, Play и Shift.

English: [manual.md](manual.md)

1. [Быстрый старт](#start)
2. [Органы управления](#hw)
3. [Экран и статус-бар](#screen)
4. [GRID: редактор паттерна](#grid)
5. [Эффекты (fx)](#fx)
6. [Fill, Euclid и арп](#euclid)
7. [TRACK: настройки дорожки](#track)
8. [INST: инструменты](#inst)
9. [PROJ: проект и паттерн](#proj)
10. [BANK: банк паттернов](#bank)
11. [Song mode](#song)
12. [FILE: сохранение и загрузка](#file)
13. [Импорт MIDI](#import)
14. [MIDI-выход](#midi)
15. [Встроенный звук](#sound)
16. [Лимиты](#limits)

## Быстрый старт

1.  Вставьте microSD-карту в формате **FAT32** со схемой разделов **MBR** и включите устройство. Если карты нет, загрузится демо-бит на дорожках 1–3.
2.  Нажмите <kbd>Play</kbd>. Секвенсор пошлёт MIDI Start и начнёт играть с первого шага. Повторное нажатие — Stop.
3.  Во вкладке **GRID** тапните клетку, тапните её ещё раз — включится правка. Нажимайте клавиши мини-клавиатуры внизу или крутите энкодер.
4.  Во вкладке **FILE** выберите **Save As…**, введите имя и нажмите OK. При следующем включении проект загрузится сам.

## Органы управления

| Действие | Что делает |
|---|---|
| <kbd>Play</kbd> | Старт с первого шага / стоп. На паузе тоже перезапускает с начала. |
| <kbd>Shift</kbd>+<kbd>Play</kbd> | Пауза и продолжение: стоп → старт, игра → пауза, пауза → продолжить с того же места. Во время игры пауза срабатывает при отпускании Play, если его держали меньше 0,5 с. |
| <kbd>Shift</kbd>+<kbd>Play</kbd>, держать | Во время игры: **fill**, пока Play нажат (шаги с [CND FIL](#cnd) играют, с NFL — нет). Отпускание после 0,5 с только заканчивает fill, без паузы. |
| <kbd>Shift</kbd> | Модификатор, сам по себе ничего не делает. Пока зажат, вместо вкладки FILE горит жёлтое `SHIFT`. |
| Поворот энкодера | Перемещение курсора или выбор строки. В режиме правки — изменение значения. С Shift — крупный шаг (обычно ×10). |
| Клик энкодера | Включить или выключить правку, выбрать пункт меню. |
| Долгое нажатие энкодера | 0,5 с: контекстное меню или закрытие диалога. |
| Тап | Выбор. Повторный тап по выбранному — правка. |
| Долгий тап | 0,5 с: контекстное меню. |
| Перетаскивание | Прокрутка. В режиме правки — изменение значения: вверх больше, вниз меньше. |

Play работает на любом экране, даже поверх открытого меню.

### Кнопки дорожек

В GRID кнопки ещё пишут ноты вживую (REC) и держат эффекты (PERF) — см. [REC и PERF](#live).

Необязательный блок из 8 кнопок со светодиодом в каждой. Дорожек 16, поэтому кнопки работают с **видимой половиной** — 1–8 или 9–16, той же, что показывает [Overview](#grid). Половина — не режим: её выбирает курсор. Ушёл за 8-ю дорожку (<kbd>Shift</kbd>+поворот, тап по имени дорожки в Detail, кнопка дорожки) — кнопки и светодиоды переключаются на 9–16; вернулся — на 1–8. Какая половина активна, показывает шапка GRID: `1-8` или `9-16` слева над номерами шагов.

| Действие | Что делает |
|---|---|
| <kbd>N</kbd> | Выбрать дорожку N видимой половины (при 9–16 кнопка 1 — дорожка 9): курсор GRID переходит на неё, TRACK показывает её. |
| <kbd>Shift</kbd>+<kbd>N</kbd> | Mute / unmute той же дорожки (N видимой половины), на любом экране. Toast `TRACK n MUTE` / `TRACK n ON` показывает настоящий номер, 1–16. |
| <kbd>N</kbd> держать + поворот | Громкость дорожки N (Volume, INT) на любом экране, с <kbd>Shift</kbd> ×10; toast `TRK5 VOL 100`. Поворот при этом экрану не достаётся. Нажатие само по себе работает как обычно (выбор дорожки). Не действует в правке GRID, в REC и PERF — там кнопки играют. На MIDI-дорожке — `TRK5 MIDI`, ничего не меняется. |
| <kbd>N</kbd> в правке GRID | Записать в шаг под курсором ступень лада проекта и сдвинуть курсор на шаг вниз. На INT-дорожке нота сразу звучит, если в PROJ включён Preview. Кнопки 1–7 — ступени I–VII, 8 — I октавой выше. У ладов короче 7 нот (пентатоники, блюз) лишние кнопки продолжают лад в следующую октаву; Chromatic вводит ступени мажора. Октава — по ноте под курсором, на пустом шаге — по последней введённой ноте дорожки. |
| <kbd>N</kbd> в редакторе сэмпла (INST, страница SMPL) | Сыграть слайс до конца: 1 — выбранный слайс (если выбран не слайс — первый), 2 — следующий за ним и так далее. Работает при любом Slices (OFF, NOTE, FX), в исходной высоте. Toast «SLICE n»; нет такого слайса — «NO SLICE n», слайсов нет — «NO SLICES». |
| <kbd>Shift</kbd>+<kbd>N</kbd> в правке GRID | Та же ступень октавой выше. |
| <kbd>N</kbd> в правке GRID на [драм-дорожке](#drumtrack)  | Включить / выключить лейн N в шаге под курсором. Курсор не двигается, Shift не нужен. |

Светодиоды показывают ту же половину, что и кнопки: LED N — дорожка N половины 1–8 или 9–16. Дорожка вспыхивает на каждой своей ноте; заглушённая молчит. Выбранная дорожка горит постоянно и на своих нотах гаснет. Активность дорожек другой половины не показывается. Ввод ступеней и слайсы в редакторе сэмпла от половины не зависят — там работает номер кнопки. OFF и очистка шага — как раньше, через меню.

### Подключение

| GPIO | Назначение |
|---|---|
| `10` | MIDI TX (UART, 31250 бод) |
| `11 / 12` | Энкодер A / B (EC11) |
| `13` | Кнопка энкодера |
| `14` | Play |
| `21` | Shift |
| `43 / 44` | Кнопки дорожек: PCF8575 SDA / SCL, разъём Debug (TXD0 / RXD0; необязательно, схема — в README) |
| `41 / 40 / 39 / 38` | microSD: CS / MOSI / CLK / MISO (встроенный слот) |

Кнопки замыкают вывод на GND, внутренняя подтяжка включена. MIDI OUT — TRS тип A, 3,3 В:

- +3,3 В → 33 Ом → Ring (контакт 4 DIN)
- GPIO10 → 10 Ом → Tip (контакт 5 DIN)
- GND → Sleeve (контакт 2 DIN)

Буфер 74HC14 (два инвертора подряд) ставить по желанию. MIDI-входа нет, устройство всегда ведущее по клоку.

## Экран и статус-бар

    S03 P05*  >P07  120 BPM  5/16  PLAY  L3  CPU  42%
    рабочая область вкладки
    GRID  TRACK  MIX  BANK  INST  PROJ  FILE

| Элемент | Значение |
|---|---|
| `P05` | Паттерн, который сейчас звучит. В song mode — `S03 P05`: третий элемент цепочки, паттерн 5. `S--` — цепочка ещё не началась. |
| `*` | Есть несохранённые изменения. |
| `>P07` | Паттерн в очереди: переключится в конце прохода. В song mode не показывается. |
| `120 BPM` | Темп. Тап включает правку темпа (красный): энкодер ±1, с Shift ±10, диапазон 20–300. Выход — клик, тап по рабочей области или смена вкладки. |
| `5/16` | Шаг / длина паттерна. |
| `PLAY` | Состояние: PLAY, PAUSE, STOP. Тап работает как кнопка Play, с Shift — как Shift+Play. |
| `L3` | Счётчик проходов паттерна. По нему работает условие CND. Пока держится fill — `FILL`. |
| `CPU 42%` | Нагрузка встроенного синтезатора: среднее время расчёта блока звука за последние 0,5 с в % от длительности блока (4 мс). Серый до 60%, жёлтый 60–84% или если за эти 0,5 с хоть один блок считался дольше 4 мс (запас очереди DMA это покрывает), красный от 85% или 2 с после срыва звука (DMA опустел — слышимый щелчок). Пока звук не считается, показывается последнее значение. |

Вкладки переключаются только тапом по нижней панели. Жёлтые сообщения (toast) на 1,5 секунды закрывают правую часть статус-бара.

**Меню** открываются по центру экрана, видно до 12 пунктов, длинные списки прокручиваются перетаскиванием. Энкодер: поворот — выбор (по кругу: после последнего пункта — первый), клик — выполнить, долгое нажатие — закрыть. Так же по кругу листаются все списки параметров и файлов. Тап вне меню тоже закрывает его. Серые пункты сейчас недоступны.

## GRID: редактор паттерна

GRID всегда редактирует паттерн, который звучит. Когда паттерн меняется (очередь, цепочка, загрузка), курсор переходит на шаг 1, правка выключается, выделение снимается.

### Два вида

- **Overview** (по умолчанию): 8 колонок — половина из 16 дорожек, та, где стоит курсор: 1–8 или 9–16. Какая половина на экране, написано слева над номерами шагов: `1-8` или `9-16`. Половина — не отдельный режим: курсор ушёл с 8-й дорожки на 9-ю (<kbd>Shift</kbd>+поворот, тап по имени дорожки в Detail, [кнопка дорожки](#trackkeys)) — показывается вторая половина, вернулся — первая. [Кнопки и светодиоды дорожек](#trackkeys) следуют за той же половиной. В клетке — нота, полоска громкости и жёлтая точка, если в шаге есть fx. Точка серая, если все fx шага — синт-fx на MIDI-дорожке (там они не действуют). Каждый четвёртый шаг подсвечен, строка воспроизведения выделена.
- **Detail**: одна (текущая) дорожка на всю ширину, 14 полей: NOTE, VEL и шесть пар FX1…FX6 с их значениями. Номер дорожки (`T3`) — над номерами шагов, имя — над NOTE/VEL. <kbd>Shift</kbd>+поворот за последним полем переходит на следующую дорожку, кнопки дорожек тоже переключают её. Тап по строке имён — mute (с <kbd>Shift</kbd> — solo) этой дорожки. Синт-fx на MIDI-дорожке показаны серым.

Цвет имени дорожки: жёлтый — solo, серый — не слышна, белый — обычная.

### Энкодер

| Ввод | Без правки | В правке |
|---|---|---|
| Поворот | Шаг вверх/вниз (по кругу) | Изменить значение поля |
| <kbd>Shift</kbd>+поворот | Overview: другая дорожка. Detail: другое поле | Крупный шаг |
| Клик | Включить правку (toast с именем поля) | Выключить правку |
| <kbd>Shift</kbd>+клик | Переключить Overview / Detail | |
| Долгое | Контекстное меню | |
| <kbd>Shift</kbd>+долгое  | Undo | |

### Что меняет поворот в правке

- **NOTE.** На пустом шаге ставится последняя введённая на дорожке нота (сначала C-4). Дальше нота двигается по ступеням лада проекта, с Shift — на октаву. Энкодером нельзя очистить шаг или поставить OFF, для этого есть меню. На INT-дорожке каждая введённая нота (энкодер, мини-клавиатура, кнопки дорожек) сразу звучит инструментом дорожки, если в PROJ включён Preview.
- **VEL.** 0–127, с Shift ×10. Значение 0 показано как `...` и означает «громкость дорожки по умолчанию».
- **FX1…FX6.** Перебор команд по группам, близкие рядом: `...`; ноты и арп CHD, STR, ARP, ARM, ARS; время RAT, NDG, GAT, TIE, OFF, CUT; случайность PRB, CND, VRN, NRN; высота и громкость SLD, VIB, PBN, VSL, ACC; звук FLT, RES, DRV, DEC, COL, SHP, SWP, CON; сэмпл OFS, SLC; посылы DLY, RVB; только MIDI CHN, CCA, CCB, PGM (поворот назад с пустого слота сразу даёт PGM). Порядок тот же, что в [таблице](#fx). Выбор команды ставит её значение по умолчанию и показывает её полное название в строке статуса (например, VIBRATO). На пустом слоте первый поворот ставит последний записанный на этой дорожке в этот слот fx с тем же значением — удобно повторять fx шаг за шагом; дальше повороты перебирают команды как обычно.
- **FX VAL.** ±1, с Shift ×10. У CND с Shift шаг тот же. На пустом слоте первый поворот так же подставляет последний fx дорожки; если его ещё не было, значение не меняется.

Одна сессия правки (от включения до выключения) — один шаг undo.

### Мини-клавиатура

Появляется внизу экрана в правке поля NOTE. Двенадцать клавиш — октава текущей ноты. Жёлтая полоска отмечает ноты лада, красная рамка — текущую ноту. Тап по клавише записывает ноту, любую, лад здесь не ограничивает. Октаву меняет <kbd>Shift</kbd>+поворот энкодера.

### Драм-дорожка

Дорожка, у которой в TRACK → Instr выбран инструмент типа [KIT](#kit), — драм-дорожка: в шаге не нота, а набор из 8 лейнов (бочка, малый, хэты…). Шаг хранит маску лейнов и одну громкость на все лейны шага.

- **Overview:** в клетке 8 квадратиков, закрашенный — лейн звучит. Полоски громкости нет, точка fx — в верхнем углу клетки.
- **Detail:** поле NOTE — те же квадратики, поле VEL — громкость шага (`...` — Def vel дорожки).
- **Правка NOTE:** поворот двигает красную рамку по лейнам, <kbd>Shift</kbd>+поворот включает / выключает лейн под рамкой. Вместо мини-клавиатуры внизу — **пэд из 8 кнопок** с именами сэмплов (или инструментов) лейнов, горящая — лейн есть в шаге; тап переключает лейн. [Кнопки дорожек](#trackkeys) 1–8 в правке делают то же. Включённый лейн сразу звучит (Preview в PROJ).
- **Правка VEL:** 1–127, с Shift ×10.
- Шаг, у которого выключили все лейны, остаётся (молчит, fx работают) — убрать его можно через Clear step. OFF ставится как обычно, через меню, и отпускает все лейны.
- Fx шага действуют на все его лейны: RAT повторяет каждый, NDG сдвигает, PRB и CND решают за весь шаг, DEC / FLT / DLY и прочие локи — для каждого голоса. CHD, NRN, STR, TIE, ARP, SLD, VIB и SLC на драм-дорожке ничего не делают. Fx **ACC** — только для драм-дорожек.
- **Transpose** драм-дорожки пропускает (toast «DRUM TRACK», если в выделении только они).
- Copy / Paste между драм- и обычными дорожками копирует байты как есть: маска лейнов станет громкостью и наоборот. Так же смена инструмента дорожки KIT ↔ не-KIT переосмысливает уже записанные шаги.
- На MIDI-дорожке каждый лейн уходит своей нотой (Note лейна) на канал дорожки — так KIT управляет внешней драм-машиной (карта GM: 36 — бочка, 38 — малый, 42 — закрытый хэт…).

### Касания

| Жест | Действие |
|---|---|
| Тап по клетке | Курсор туда. Тап по клетке с курсором — правка вкл/выкл. Снимает выделение. |
| <kbd>Shift</kbd>+тап | Выделение: первый тап ставит угол, следующие двигают противоположный. |
| Долгий тап | Курсор туда и контекстное меню. |
| <kbd>Shift</kbd>+долгий тап | Undo. |
| Тап по имени дорожки | Mute. С Shift — solo. |
| Перетаскивание | Прокрутка строк. Отключает follow до следующего старта. |

**Follow**: во время игры, если курсор не трогали 2 секунды, экран сам листает к играющему шагу. Включается и выключается в контекстном меню.

### Выделение энкодером

Меню → **Select** ставит угол выделения на клетке под курсором. Пока выделение есть, любое движение курсора (поворот — по шагам, <kbd>Shift</kbd>+поворот — по дорожкам или полям) двигает противоположный угол. Долгое нажатие открывает меню выделения, клик снимает выделение. После **Copy sel** выделение снимается: уведите курсор и выберите **Paste**. Clear, Note OFF и Transpose выделение оставляют.

### Контекстное меню

| Без выделения | С выделением |
|---|---|
| Copy step · Paste · Clear step · Note OFF · Select · Copy track · Clear track · Transpose track… · **Fill…** · **Resample track** · **Resample pattern** · **Rec: ON/OFF** · **Perf: ON/OFF** · Detail view / Overview · Follow: ON/OFF · Undo | Copy sel · Paste · Clear sel · Note OFF sel · Transpose… · **Fill…** · Undo · Clear selection |

- **Transpose…** открывает диалог: **Amount** и **Mode** (SCALE — ступени лада, CHROMATIC — полутона), кнопки OK / CANCEL. Диапазон — две октавы вверх и вниз (в SCALE это 2 × число нот лада, у мажора ±14). <kbd>Shift</kbd>+поворот меняет Amount на октаву. Долгое нажатие — Cancel. Затрагивает только шаги с нотой, без выделения — всю дорожку; один шаг undo. Это сдвиг, а не состояние: Amount при каждом открытии начинается с 0, вернуть ноты — применить обратный сдвиг (+12, потом −12). Mode запоминается до выключения.
- Paste вставляет в позицию курсора или в левый верхний угол выделения. Не выходит за 16-ю дорожку и длину паттерна; выделение тоже обрезается на 16-й дорожке.
- Буфер обмена переживает загрузку другого проекта — так можно переносить куски между проектами.
- Если за время открытого меню паттерн сменился, действие не выполнится (toast «PATTERN CHANGED»).

### REC и PERF: кнопки дорожек вживую

Два режима из контекстного меню GRID. Они исключают друг друга и правку: включение одного выключает остальные. В шапке над номерами шагов — `REC` (красным) или `PERF` (жёлтым). Работают во время игры; на остановке кнопки ведут себя как обычно.

- **REC** — запись с кнопок дорожек в текущую дорожку. Кнопка N пишет ступень N лада (в октаве последней ноты дорожки) в звучащий шаг; нажатие во второй половине шага попадает в следующий. <kbd>Shift</kbd>+N стирает ноту этого шага. На драм-дорожке кнопка N ставит лейн N, <kbd>Shift</kbd>+N снимает его. Каждый проход паттерна — один шаг undo. Дорожку для записи выбирают тапом по имени (в REC это не mute) или <kbd>Shift</kbd>+поворотом. Записанная нота сразу звучит, если включён Preview.
- **PERF** — эффект, пока кнопка держится, на текущую дорожку; нажатие показывает его название (`PERF FILTER LOW`). Какой эффект на какой кнопке — в [PROJ → PERF](#proj), хранится в проекте. Отпустили — эффект снят. Нажатие другой кнопки заменяет эффект. <kbd>Shift</kbd>+N по-прежнему mute.

| Эффект | Что делает | Выход |
|---|---|---|
| RAT 2 / RAT 3 / RAT 4 / RAT 8 | ретриггер (по умолчанию RAT 2 — кнопка 1, RAT 4 — кнопка 2) | оба |
| ROLL UP | RAT 8 с нарастающей громкостью — «разгон» | оба |
| FILTER LOW / FILTER HIGH | FLT 30 / FLT 120 (кнопки 3, 4) | INT |
| DELAY MAX / REVERB MAX | DLY 127 (кнопка 5) / RVB 127 | INT |
| CRUSH / DOWNSAMPLE / DRIVE | BIT 100 (кнопка 6) / SRR 90 / DRV 100 | INT |
| SHORT DECAY | DEC 20 — короткий макрос DECAY | INT |
| FADE | затухание VSL −16, на MIDI — половина громкости (кнопка 7)  | оба |
| MUTE | mute дорожки (кнопка 8) | оба |
| --- | кнопка ничего не делает | |

Эффект добавляется к шагам, как они играют: собственные fx шага остаются, та же команда в шаге заменяется. Шаги, уже запланированные наперёд (до восьмой ноты), играют как были. Стоп снимает все эффекты, уход с GRID — удерживаемый.

### Resample

**Resample track** и **Resample pattern** в меню GRID записывают звучащий паттерн встроенным звуком в новый сэмпл проекта: только текущую дорожку или все слышимые (с учётом mute / solo). Сэмпл называется `RS1`, `RS2`… (первое свободное имя), громкость приводится к −1 dBFS, тишина в конце обрезается, хвоста delay / reverb после конца паттерна нет. Дальше его можно выбрать в INST (SAMPLE или лейн KIT) и сохранить вместе с проектом.

- Только при остановке (`STOP FIRST`). Паттерн рендерится дважды (замер, затем запись), примерно в реальном времени каждый проход — прогресс `RENDER nn%`; долгое нажатие энкодера или Play — отмена (`CANCELLED`).
- Длиннее 60 с не пишется: `SAMPLE CAP`, сэмпл всё равно добавлен. Нет места во flash — `BANK FULL`; в списке уже 128 сэмплов — тоже.
- Результат — `RS3 2.1s`. Рендер совпадает с воспроизведением (без задержки выхода 14 мс); ноты, сдвинутые NDG / swing за конец паттерна, обрезаются.

### Undo

8 шагов. Каждый шаг — снимок целого паттерна (с 16 дорожками снимок стал вдвое больше, поэтому глубина — 8, а не 32). Отменяет правки в GRID, операции меню, Fill, а также Copy-to, Clear и Length в BANK. Параметры TRACK и PROJ, темп, mute/solo и правки цепочки не отменяются. Redo нет. Load, New и импорт очищают историю.

### Шаг

- Нота: `C-4` = 60, диезы — `C#4`. Октава −1 показана как `m`.
- `---` — пустой шаг, `OFF` — явное снятие ноты (обрывает TIE и звучащую ноту дорожки; на INT-дорожке отпускает все её голоса, включая сэмплы).
- Громкость 1–127 или `...` (по умолчанию дорожки). Шесть слотов fx, пустой — `...`.

## Эффекты (fx)

В каждом шаге шесть слотов. Если одна команда стоит в нескольких, работает первая. Колонка «Выход»: MIDI — только на MIDI-дорожках, INT — только на INT-дорожках (встроенный звук), оба — везде.

| Код | Значение | Выход | Что делает |
|---|---|---|---|
| **Ноты и арпеджио** | | | |
| `CHD` | tri 7th su2 su4 6th ad9 pwr oct | оба | Аккорд от ноты: до 4 нот, ноты выше 127 отбрасываются. |
| `STR` | 1–50 | оба | Страм: k-я нота аккорда позже на k×STR% шага. |
| `ARP` | 00–FF (xy) | INT | Арпеджио: нота, +x, +y полутонов по кругу, три переключения на шаг (порядок и скорость меняет ARM) — быстрый «чиптюн»-арп внутри звучащей ноты. С CHD в том же шаге арпеджирует ноты аккорда — см. ниже. Арп по шагам секвенсора — ARS. |
| `ARM` | U1…R8 | INT | Режим ARP: буква — порядок (U вверх, D вниз от верхней, B вверх-вниз без повтора крайних, R случайно), цифра — нот на шаг (1–8). Поворот сначала меняет цифру, потом букву. По умолчанию U3 = обычный ARP. Без ARP ничего не делает; держится вместе с ARP до следующего шага с нотой. |
| `ARS` | U1…R84 | оба | Шаговый арп: каждая нота — отдельный удар на сетке секвенсора (см. [ниже](#ars)). Буква — порядок, как у ARM; первая цифра — через сколько шагов следующая нота (1 — каждый шаг, 2 — через шаг …, до 8); вторая цифра, если есть, — диапазон в октавах (2–4, без неё — 1 октава): `U12` — вверх, каждый шаг, 2 октавы. Поворот меняет сначала шаги, потом октавы, потом букву. |
| **Время и длина** | | | |
| `RAT` | 2–8, 2^…8^, 2v…8v | оба | Ретриггер: N равных ударов внутри шага. Gate — доля подшага, максимум 95%. После 8 поворот идёт в `2^…8^` — громкость ударов нарастает до громкости шага, затем `2v…8v` — спадает от неё. |
| `NDG` | −50…+50 | оба | Сдвиг всего шага на ±% длины шага. Отрицательный сдвиг работает. |
| `GAT` | 1–800% | оба | Длина ноты в % от шага. До 100% — шаг 1%, дальше 107, 114 … 800%. |
| `TIE` | — | оба | Нота не снимается и тянется через пустые шаги (см. ниже). |
| `OFF` | 0–96 | оба | Note off через N тиков от начала шага (с учётом NDG). Ноты этого шага снимаются не позже (удары RAT после этого момента не звучат, TIE отменяется; на шаге с нотой — не раньше чем через 1 мс), висящий TIE дорожки снимается. На INT-дорожке отпускаются все голоса дорожки, включая сэмплы и DRUM, — с обычным release (CUT — без release). На пустом шаге `OFF 0` = OFF в колонке ноты. |
| `CUT` | 1–96 | INT | Оборвать ноту через N тиков, без release. Тик — 1/96 четверти: шаг 1/16 = 24 тика. |
| **Случайность и условия** | | | |
| `PRB` | 0–100 | оба | Вероятность срабатывания шага, %. |
| `CND` | FST, A:B, FIL, NFL, PRE, !PR, NEI, !NE | оба | Условие по проходам и по другим условиям (см. ниже). |
| `VRN` | 0–64 | оба | Случайный разброс громкости ±N. |
| `NRN` | 1–7 | оба | Случайный сдвиг ноты на ±N ступеней лада. |
| **Высота и громкость** | | | |
| `SLD` | 1–255 | INT | Глайд, время ≈ значение × 4 мс (4 мс … 1,02 с). |
| `VIB` | 00–FF (xy) | INT | Вибрато: x — скорость (x × 0,5 Гц), y — глубина (до ±2 полутонов при F). |
| `PBN` | −64…+63 | оба | Pitch bend: 8192 + v×128. Сам не сбрасывается, верните 0 отдельным шагом. На INT — сдвиг высоты голосов дорожки до ±2 полутонов. |
| `VSL` | −64…+63 | INT | Плавное изменение громкости за один шаг: ±64 — на всю шкалу. |
| `ACC` | 00–FF | оба | Только [драм-дорожки](#drumtrack): маска лейнов с полной громкостью шага (бит 0 — лейн 1), остальные лейны шага звучат на 60 %. На других дорожках показан серым и не действует. |
| **Звук (локи инструмента)** | | | |
| `FLT` | 0–127 | INT | Cutoff [фильтра](#filter) для ноты шага, любой тип инструмента. |
| `RES` | 0–127 | INT | Reso фильтра для ноты шага, любой тип инструмента. |
| `DRV` | 0–127 | INT | Drive (перегруз) для ноты шага, любой тип инструмента; на шаге без ноты — для звучащей ноты. |
| `BIT` | 0–127 | INT | Bitcrusher для ноты шага: разрядность от 16 бит (0 — выключен) до 2 бит (127). После Drive, перед фильтром. Постоянное значение — INST → FILT → Bit crush; лок шага его заменяет. |
| `SRR` | 0–127 | INT | Понижение частоты дискретизации для ноты шага: 0 — выключено, 127 — каждый отсчёт держится ≈ 64 отсчёта (грубый «цифровой» звук). Вместе с BIT — классический lo-fi. Постоянное значение — INST → FILT → Downsample. |
| `DEC` | 0–127 | INT | FM, DRUM, SYNTH: макрос DECAY для ноты шага (у DRUM — слот машины с тем же номером, у SYNTH — SHP1). |
| `COL` | 0–127 | INT | FM, DRUM, SYNTH: макрос COLOR для ноты шага (у DRUM — слот машины с тем же номером, у SYNTH — SHP2). |
| `SHP` | 0–127 | INT | FM, DRUM, SYNTH: макрос SHAPE для ноты шага (у DRUM — слот машины с тем же номером, у SYNTH — MIX). |
| `SWP` | 0–127 | INT | FM, DRUM, SYNTH: макрос SWEEP для ноты шага (у DRUM — слот машины с тем же номером, у SYNTH — DET). |
| `CON` | 0–127 | INT | FM, DRUM, SYNTH: макрос CONTOUR для ноты шага (у DRUM — слот машины с тем же номером, у SYNTH — SENV). |
| **Сэмпл** | | | |
| `OFS` | 0–255 | INT | Старт сэмпла с доли значение/256 области Start–End. Только SAMPLE. |
| `SLC` | 0–31 | INT | Слайс сэмпла для ноты шага: 0 — первый слайс, 31 — 32-й. Только SAMPLE с Slices = FX (см. [слайсы](#slices)). |
| **Посылы** | | | |
| `DLY` | 0–127 | INT | Посыл в [delay](#delay) для ноты шага (заменяет Dly send инструмента), любой тип инструмента. |
| `RVB` | 0–127 | INT | Посыл в [reverb](#reverb) для ноты шага (заменяет Rvb send инструмента). |
| **Только MIDI** | | | |
| `CHN` | 1–16 | MIDI  | MIDI-канал этого шага: ноты, CC, PB, PGM. |
| `CCA` | 0–127 | MIDI  | CC с номером «CC A» дорожки (по умолчанию 74). |
| `CCB` | 0–127 | MIDI  | CC с номером «CC B» дорожки (по умолчанию 71). |
| `PGM` | 0–127 | оба | Program Change. На INT — инструмент дорожки: 0 = INS1 … 31 = INS32, больше 31 — INS32. Действует до конца игры, в TRACK → Instr не записывается. |

### Шаговый арп (ARS)

ARP играет ноты арпеджио внутри одной звучащей ноты, быстро и без новой атаки. ARS — арп на сетке секвенсора: каждая нота арпеджио звучит как отдельная нота шага, со своей атакой, и работает и на INT, и на MIDI.

- **Какие ноты.** С CHD в шаге — ноты аккорда; иначе с ARP (не 00) — нота, +x, +y; иначе — сама нота. Диапазон 2–4 октавы повторяет эти ноты на октаву, две, три выше (C E G → C E G C' E' G' …); одна нота без CHD и ARP всегда идёт минимум на 2 октавы. Ноты выше 127 берутся октавой ниже.
- **Как идёт.** Шаг с ARS играет первую ноту (U — нижнюю, D — верхнюю во всём диапазоне октав; B идёт вверх и обратно через весь диапазон). Следующие шаги дорожки без ноты играют следующие ноты: каждый шаг при цифре 1, каждый второй при 2 и так далее. Пустые шаги можно не заполнять — арп идёт сам.
- **Когда останавливается.** На следующем шаге с нотой (новый арп или просто нота), на OFF (в колонке ноты или fx OFF), при смене паттерна, на стопе. Повтор того же паттерна арп не прерывает.
- **Длина нот** — GAT шага с ARS (или Gate дорожки) от промежутка между нотами арпа; нота всегда снимается до следующей. Громкость — как у шага с ARS.
- **Fx на шагах арпа.** Fx пустого шага, на который приходится нота арпа, действуют на эту ноту (например, FLT или DLY). ARP, ARM, TIE и STR в шаге с ARS не действуют; на драм-дорожках ARS не действует.

Пример: нота C-4, CHD tri, ARS U1, ниже пустые шаги и OFF на 9-м шаге — восемь шестнадцатых C E G C E G C E.

### Синт-fx на INT-дорожках

**ARP + CHD.** Если в шаге есть и ARP (не 00), и CHD, на INT-дорожке играет одна нота, а ARP перебирает ноты аккорда (в ладу проекта) вместо 0, x, y — в порядке и со скоростью ARM. На MIDI-дорожке аккорд звучит целиком, как раньше. ARP 00 с CHD — обычный аккорд.

SLD, VIB, ARP, VSL, OFS, CUT, DEC, COL, SHP, SWP, CON, FLT, RES, SLC, DLY, DRV, RVB, ARM действуют только на дорожках с Out = INT. На MIDI-дорожках они ничего не отправляют и показаны серым. Значения VIB и ARP — шестнадцатеричные: `47` = x 4, y 7.

- **Шаг с нотой.** Fx относятся к ноте этого шага. Новый шаг с нотой сбрасывает VIB и ARP: чтобы вибрато или арпеджио продолжались, повторите fx.
- **Шаг без ноты** (пустой или OFF). VSL, CUT и ARP действуют сразу на звучащие голоса дорожки, VIB меняет параметры звучащего вибрато. SLD ведёт звучащий голос к последней сыгранной ноте дорожки. VIB и ARP держатся до следующего шага с нотой.
- **SLD на шаге с нотой:** если голос дорожки ещё звучит, он скользит к новой ноте без повторной атаки (легато), иначе новая нота начинается с высоты предыдущей.
- **ARP:** каждое из трёх значений длится треть шага. `00` — выключить.
- **VSL** отсчитывается от громкости ноты; полный подъём или спад занимает ровно один шаг (с учётом разрешения паттерна).
- **CUT:** длина тика берётся из темпа (тик = 1/96 четверти), не зависит от разрешения. Если CUT меньше gate — нота обрывается раньше.
- **OFS** работает только у SAMPLE и только в начале ноты; при Reverse отсчитывается от конца. Если нота играет слайс, OFS отсчитывается внутри слайса.
- **SLC** работает только у SAMPLE с Slices = FX и только в начале ноты, как OFS: первый note-on этого шага играет выбранный слайс с высотой ноты (у аккорда и RAT остальные ноты играют всю область). Без SLC или если номер не меньше числа слайсов — играет вся область Start–End. На шаге без ноты SLC ничего не делает.
- **DEC, COL, SHP, SWP, CON** (p-lock макросов) работают только у [FM](#fm), [DRUM](#drum) и [SYNTH](#synth), на CHIP и SAMPLE игнорируются. На шаге с нотой значение заменяет макрос инструмента для этой ноты; на шаге без ноты — для звучащей ноты дорожки до следующей ноты. Следующий шаг лок не наследует. У TONE и CHORD спад огибающей фиксируется в начале ноты: DEC на шаге без ноты (и LFO на DECAY) длину уже звучащей ноты не меняет.
- **FLT, RES** (p-lock фильтра) работают на всех типах, но только при Filter не OFF. Значение заменяет Cutoff или Reso инструмента: на шаге с нотой — для этой ноты, на шаге без ноты — для звучащих голосов дорожки до следующей ноты. Огибающая фильтра, Key track и LFO CUTOFF прибавляются к значению лока.
- **DLY** (p-lock посыла в delay) работает так же: на шаге с нотой — посыл нот этого шага, на шаге без ноты — посыл звучащих голосов дорожки до следующей ноты. Удобно для «бросков» эха на отдельные удары: Dly send инструмента 0, на нужных шагах `DLY 127`.

Остальные fx на INT: RAT, GAT, PRB, TIE, NDG, CHD, STR, CND, VRN, NRN работают как на MIDI; PBN и PGM — см. таблицу; CHN, CCA, CCB игнорируются.

### Аккорды CHD

tri = 1-3-5, 7th = 1-3-5-7, su2 = 1-2-5, su4 = 1-4-5, 6th = 1-3-5-6, ad9 = 1-3-5-9 — ступени лада проекта. pwr = нота + квинта (7 полутонов), oct = нота + октава. При хроматическом ладе аккорд строится как в мажоре от этой ноты.

### Условие CND

- `FST` — только на первом проходе после старта или смены паттерна.
- `A:B` — на A-м проходе из каждых B. Например, `2:4` — на 2-м, 6-м, 10-м… B от 2 до 8.
- `PRE` / `!PR` — шаг играет, если последнее условие на этой дорожке (CND A:B / FST / FIL / NFL или PRB) сработало / не сработало. `NEI` / `!NE` — то же для дорожки слева (на дорожке 1 NEI никогда не срабатывает). Сами PRE / NEI «последним условием» не считаются: удобно строить цепочки вариаций — шаг с `1:2`, а через несколько шагов `PRE` играет ровно в те же проходы.
- `FIL` — только пока держится fill (<kbd>Shift</kbd>+<kbd>Play</kbd> во время игры), `NFL` — только пока не держится. Идут после 8:8. Шаги, уже запланированные наперёд (до восьмой ноты), решаются по состоянию на момент планирования.
- Проходы считает счётчик `L` в статус-баре. Он сбрасывается при старте и при смене паттерна.

### TIE

- Следующая нота той же высоты и на том же канале продолжает звук без повторного удара (легато). Конец определяет её gate или ещё один TIE.
- Другая нота начинается, а старая снимается через 1 мс (перекрытие).
- TIE снимают: OFF, mute, несработавший CND/PRB на шаге с нотой, смена паттерна.
- У аккорда TIE не работает. У RAT связан только последний удар.

### Порядок обработки шага

Сначала CND, потом PRB. Если любое условие не прошло, шаг молчит целиком, вместе с CC/PB/PGM. Затем канал (CHN), затем контроллеры (в начале шага с учётом NDG), затем ноты. Контроллеры отправляются и на шагах без ноты, и на OFF. Заглушённая дорожка не отправляет ничего.

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

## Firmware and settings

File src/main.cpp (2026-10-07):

#include <Arduino.h>
#include <new>
#include "audio/audio.h"
#include "engine/engine.h"
#include "esp_heap_caps.h"
#include "hw/input.h"
#include "hw/lgfx_config.h"
#include "hw/pins.h"
#include "hw/sdcard.h"
#include "hw/trackio.h"
#include "model.h"
#include "storage/crashlog.h"
#include "storage/storage.h"
#include "ui/app.h"

static LGFX lcd;
static mt::Project* project;
static ui::App app;

// Simple 808 beat so Play produces something right after flashing. DRUM machines play their own
// pitch at C-4.
static void loadDemo(mt::Project& p) {
  static const mt::DrumMachine kKit[] = {mt::DrumMachine::Bd8, mt::DrumMachine::Sd8, mt::DrumMachine::Hh8};
  for (int t = 0; t < 3; ++t) {
    mt::instrSetType(p.instruments[t], mt::InstrType::Drum);
    mt::drumSetMachine(p.instruments[t], static_cast<uint8_t>(kKit[t]));
  }
  mt::Pattern& pat = p.patterns[0];
  for (int i = 0; i < 16; i += 4) pat.steps[0][i].note = 60;
  pat.steps[1][4].note = 60;
  pat.steps[1][12].note = 60;
  for (int i = 2; i < 16; i += 4) pat.steps[2][i].note = 60;
}

#ifdef WT_BENCH
namespace audio {
void wtBench();
}
#endif

void setup() {
  Serial.begin(115200);
  // Before anything else: the synth and the sequencer need large blocks of internal RAM (in PSRAM
  // the audio costs far more); the SD card, the screen and Wi-Fi fragment it later.
  audio::reserve();
  engine::reserve();
  void* mem = heap_caps_malloc(sizeof(mt::Project), MALLOC_CAP_SPIRAM);
  if (!mem) mem = heap_caps_malloc(sizeof(mt::Project), MALLOC_CAP_8BIT);
  if (!mem) {
    Serial.println("FATAL: no memory for Project");
    for (;;) vTaskDelay(1000);
  }
  project = new (mem) mt::Project();
  // Engine not running yet: load straight into the live project.
  bool fromBak = false;
  storage::Result autoErr = storage::Result::Ok;
  // Safe boot: Shift held at power-on skips the autoload (a project that crashes the device on load).
  pinMode(pins::kShift, INPUT_PULLUP);
  delay(5);
  const bool safeBoot = digitalRead(pins::kShift) == LOW;
  const bool sd = hw::sdBegin();
  storage::logBoot();  // a crash / watchdog / brownout restart goes into /diag/crashlog.txt
  const bool loaded = sd && !safeBoot && storage::autoload(*project, &fromBak, &autoErr);
  if (!loaded) loadDemo(*project);

  lcd.init();
  lcd.setRotation(1);
  pinMode(pins::kLcdBacklight, OUTPUT);
  digitalWrite(pins::kLcdBacklight, HIGH);

  hw::inputBegin();
  hw::trackioBegin();
  engine::begin(project);
  audio::begin(project);
  app.begin(&lcd, project);
  engine::post(engine::Cmd::ChainEdit, static_cast<uint16_t>(mt::ChainOp::Edit));  // song position display
  // Bank mounted by audio::begin, engine not playing: bring in the samples the cache lacks.
  int missing = 0;
  const bool folderFail = loaded && storage::pullSamples(*project, &missing, ui::App::syncProgress, &app) ==
                                        storage::Result::SamplesNotSaved;
  // One toast: autoload error (nothing loaded), or backup / missing samples / folder not written.
  if (safeBoot) {
    app.toast("SAFE BOOT: NOTHING LOADED");
  } else if (autoErr != storage::Result::Ok) {
    char msg[48];
    snprintf(msg, sizeof(msg), "AUTOLOAD: %s", storage::resultText(autoErr));
    app.toast(msg);
  } else if (fromBak || missing > 0 || folderFail) {
    app.loadedToast(fromBak ? "LOADED BACKUP" : nullptr, missing, folderFail);
  }
#ifdef WT_BENCH
  audio::wtBench();
  app.toast("WT BENCH: /midi/bench.mid");
#endif
}

void loop() {
  hw::InputEvent ev;
  while (hw::inputPoll(ev, 0)) app.onInput(ev);
  app.tick();
  audio::pollLog();
  vTaskDelay(1);
}

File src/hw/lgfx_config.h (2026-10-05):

#pragma once
#define LGFX_USE_V1
#include <LovyanGFX.hpp>

// WT32-SC01 Plus: ST7796 on an 8-bit 8080 bus, FT6336U touch.
class LGFX : public lgfx::LGFX_Device {
  lgfx::Panel_ST7796 panel_;
  lgfx::Bus_Parallel8 bus_;
  lgfx::Touch_FT5x06 touch_;

 public:
  LGFX() {
    {
      auto cfg = bus_.config();
      cfg.freq_write = 40000000;
      cfg.pin_wr = 47;
      cfg.pin_rd = -1;
      cfg.pin_rs = 0;
      cfg.pin_d0 = 9;
      cfg.pin_d1 = 46;
      cfg.pin_d2 = 3;
      cfg.pin_d3 = 8;
      cfg.pin_d4 = 18;
      cfg.pin_d5 = 17;
      cfg.pin_d6 = 16;
      cfg.pin_d7 = 15;
      bus_.config(cfg);
      panel_.setBus(&bus_);
    }
    {
      auto cfg = panel_.config();
      cfg.pin_cs = -1;
      cfg.pin_rst = 4;
      cfg.pin_busy = -1;
      cfg.panel_width = 320;
      cfg.panel_height = 480;
      cfg.offset_x = 0;
      cfg.offset_y = 0;
      cfg.offset_rotation = 0;
      cfg.readable = false;
      cfg.invert = true;
      cfg.rgb_order = false;
      cfg.dlen_16bit = false;
      cfg.bus_shared = false;
      panel_.config(cfg);
    }
    // No Light_PWM: the backlight (pins::kLcdBacklight) is driven high as a plain GPIO, since its
    // 44.1 kHz PWM whined in the audio path.
    {
      auto cfg = touch_.config();
      cfg.i2c_port = 1;
      cfg.i2c_addr = 0x38;
      cfg.pin_sda = 6;
      cfg.pin_scl = 5;
      cfg.pin_int = 7;
      cfg.freq = 400000;
      cfg.x_min = 0;
      cfg.x_max = 319;
      cfg.y_min = 0;
      cfg.y_max = 479;
      cfg.bus_shared = false;
      cfg.offset_rotation = 0;
      touch_.config(cfg);
      panel_.setTouch(&touch_);
    }
    setPanel(&panel_);
  }
};

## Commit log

2026-10-02 docs: README, user manual, stage plans, future plans
2026-10-02 feat(enclosure): OpenSCAD case with IP5306 power, optional 8 track buttons
    [case.scad, case8_bottom.stl, case8_top.stl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]
2026-10-05 feat: Wi-Fi transfer, track buttons, internal audio, FM machines
    - Wi-Fi transfer (FILE -> Wi-Fi): http://tracker.local, /projects /midi /samples,
    OTA via web page and env wt32-ota
    - 8 track buttons + LEDs on PCF8575 (select, Shift = mute, scale degrees in GRID edit)
    - Internal audio on NS4168: 16-voice synth (chip + sampler, sample bank in flash),
    fx SLD/VIB/ARP/VSL/OFS/CUT, INST tab, WAV import/preview, master volume in NVS
    - FM machines (KICK/SNARE/METAL/PERC/TONE/CHORD/CLAP/HAT): macros DECAY/COLOR/
    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
    [knob.scad, knob.stl, knob8.stl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]
2026-10-06 feat: internal synth engine, FM/DRUM/SYNTH types, delay, 16 tracks, KIT drum track (tasks 1-5)
    Everything since the Wi-Fi/FM commit, built and tested on the device unless noted:
    - Internal audio: 16-voice synth (chip + sampler), I2S NS4168, sample bank in
    flash, FILE -> SAMPLES, INST tab, WAV preview, master volume in NVS
    - FM machines (8), DRUM machines (16, 808/909), SVF filter with AD env, LFO,
    factory presets (.mti) for CHIP/FM/DRUM/SYNTH, user presets in /presets
    - SYNTH type: 2 BL oscillators (PolyBLEP) or 64x256 wavetables with mips,
    sub/noise, macros; /wavetables on SD and over Wi-Fi; block-wise voice core
    - Project samples: flash bank as cache keyed by CRC32, SMPL chunk, WAVs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
    [case.scad, case8_bottom.stl, case_bottom.stl]
2026-10-07 Claude/tracker roadmap oa6o90 (#1)
    * docs: add roadmap consolidating done and planned work
    Claude-Session: https://claude.ai/code/session_01JTrBX3zZjp8TcixpdD1Ytm
    * docs: remove roadmap
    Claude-Session: https://claude.ai/code/session_01JTrBX3zZjp8TcixpdD1Ytm
    * feat: KIT drum track, tasks 6-11 (synth lanes, GRID, Euclid, INST, import, docs)
    - Synth: KIT lanes resolve by note; sampler lanes play a scratch SAMPLE
    instrument kept in the voice (Voice::lane / laneInst, Synth::instrOf),
    INST lanes redirect to the referenced instrument; each lane is mono with
    choke, up to 8 voice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
    [case.scad, knob.scad]
2026-10-07 fix(sd): steadier SD bus and recovery after a stuck transfer
    - Mount at 10 MHz instead of 20 MHz (4 MHz fallback unchanged).
    - Internal pull-up on MISO so the line does not float between transfers.
    - resetBus selects the card, drains the pending block and sends CMD12
    before the wake-up clocks, so a card stuck in a multi-block read can
    be remounted without a power cycle.
    - CORE_DEBUG_LEVEL=1: SD driver errors show on the USB serial console.
    [sdcard.cpp]
2026-10-07 fix(synth): sidechain key track bypasses the master compressor
    The SC track was both the key (x4 at full depth) and part of the compressed
    mix, so a kick keying the compressor squashed itself by ~16 dB after the
    1 ms attack: a click and no body. The key track now goes around the
    compressor and is added back after it; only the rest of the mix ducks.
    The DJ filter moves after the compressor so it still sweeps the whole mix.
    Also fix test_synth_drive build (missing <initializer_list>).
    [test_main.cpp]
2026-10-09 feat(enclosure): clamps v2 - 4 lugs pressing the module's corner bosses
    Each lug hangs on an existing clamp post (one M3 screw) and presses a corner
    boss of the WT32-SC01 Plus; a pin in the boss hole stops it from turning.
    No top reprint needed; foam tape under the clamps is no longer used.
    [case.scad, clamp2.stl]
2026-10-09 feat: project master volume + device Phones level; UI cancel, wavetable picker, edit step
    - MIX → MAIN is now project data (saved, included in Render WAV);
    PROJ → SYS → Phones is the device output level.
    - Shift+click cancels a value edit; WtPicker looks and scrolls like file import;
    Edit step setting.
2026-10-09 feat(model): default master volume 100 %
    New projects (and old files without the audio chunk) start at MAIN 100 %
    instead of 40 %, now that the device level is the separate Phones setting.
2026-10-09 feat(fill): arp generator - Virus-style arps written as notes
    FILL gets Type FILL / ARP. ARP runs a rhythm pattern over held notes
    (chord in the project's scale, or the notes + CHD of the selected
    tracks, following chord changes) and writes note, velocity and GAT /
    TIE / SLD / NDG / RAT / PRB / CHD to a Dest track, keeping other locks.
    - 10 modes (UP, DOWN, UP/DN, DN/UP, PLAYED, RANDOM, CONVERGE, DIVERGE,
    PEDAL, CHORD), octaves 1-4, rate x1-x4, rotate, gate, swing,
    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
2026-10-09 feat(synth): LFO Retrig ON/OFF - shared per-instrument phase
    Retrig OFF gives one LFO phase per instrument for all voices and tracks
    (bit 1 of the sync byte, old projects unchanged). FREE runs continuously;
    TEMPO resets on transport start (0xFA to the synth), holds on pause
    (0xFC/0xFB), so a 1 BAR LFO stays on the bar grid. INST screen row
    Retrig after Sync; manuals updated.
    [test_main.cpp]
2026-10-09 feat(synth): more LFO destinations + LFO-to-LFO
    New targets: RESO, FENV, DLY, RVB, BIT, SRR, FINE (all types), DUTY (CHIP),
    SUB, NOISE, SEMI2 (SYNTH), and L1-L4 RATE / DEPTH / RTRG: one LFO modulates
    another's rate (x2^+-4), depth (x0..2) or restarts it on each source cycle.
    LFO-to-LFO reads the previous control tick (1 ms lag, loops allowed); a
    Retrig OFF target takes RATE / RTRG only from Retrig OFF sources.
    Dest row skips targets the type lacks; type change resets them to PITCH.
    File format unchanged (new LfoDest values appended).
    [test_main.cpp]
2026-10-12 Feature/dac (#2)
    * feat(synth): LFO free-running trig mode and LFO step fx
    - LFO Trig NOTE / FREE: FREE keeps one phase per track, reset at playback
    start, bar-locked with TEMPO; flags packed in the sync byte, no format change
    - step fx LFO, LFD, LFS, LFW, LFT, LFR: select an LFO, lock depth / rate /
    wave / dest, reset the phase; LFO is emitted before the other fx
    * feat(hw): external PCM5102A DAC, all buttons on PCF8575
    - sound goes to a PCM5102A on GPIO 13 / 14 / 21 and a headphone amplifier;
    NS4168 and SPK are no longer used
    - encoder button, Play and Shift moved to the PCF8575 (now required)
    - docs: wiring, manual (incl. L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
2026-10-12 docs: battery gauge + FILE system section implementation plans
2026-10-12 feat: INA226 battery gauge, FILE system section, BOM
    - battery gauge: INA226 on the shared I2C bus, charge % and icon in the
    status bar, low-battery toast, voltage/current in FILE -> SYSTEM
    - FILE screen: system section (moved from PROJ screen)
    - docs: bill of materials (docs/bom.md, bom_ru.md), links from README
    and enclosure README; PCF8575 listed as required in both builds
2026-10-12 feat: Polyend-style SONG tab replaces chain song mode (#3)
    - Song = up to 128 slots (pattern + 16-track mute mask), new SNG3 chunk;
    old CHN2/SCNS/PROJ chains migrate (repeats -> slots, scenes -> masks,
    transpose dropped with toast)
    - Sequencer: runtime SONG/LOOP mode, slot masks set mutes, pre-song
    mutes restored on stop / SONG->LOOP, edits during play keep position
    - New SONG tab (grid of slots x tracks, row menu, undo); tab order
    GRID TRACK INST MIX BANK SONG PROJ FILE; status-bar SONG/LOOP toggle
    - BANK: chain list and scenes removed; queue blocked while song plays
    - Render, demos, templates, manuals and README updated
    Co-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
2026-10-13 Feature/perf master (#4)
    * feat: PERF punch-in effects on the master, DJ filter moves into PERF
    PERF buttons are now PO-33 / EP-133 style effects on the whole internal
    mix instead of fx locks on the current track: REPEAT, ROLL, REVERSE,
    SCRATCH, TAPE STOP, GATE, FILTER (the old DJ filter: clockwise HP,
    counter-clockwise LP), CRUSH, DOWNSAMPLE, DRIVE, DELAY THROW, REVERB
    THROW, FREEZE. Held buttons stack (buffer effects share one read head:
    the last pressed plays); the encoder sets the depth of the last pressed
    one, Shift x10 on wide ranges.
    - PROJ -> PERF: each button has an effect and its own start Value.
    - PerfStack / PerfBus in lib/core, synth message 0xF6 through the UI
    queue; the se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
2026-10-13 Feature/perf master (#5)
    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
2026-10-14 fix: CPU guard no longer steals voices on a single late block
    One block over budget is a spike the DMA buffers absorb. A voice now
    fades only after 2 blocks in a row over budget, or one over 150%, and
    the pool keeps its size then. High smoothed load sheds as before.
2026-10-14 fix: send due events before planning a step
    Planning a step takes up to ~2 ms on the device and ran before
    emitDue, so an event reached the synth late and played a block later.
2026-10-14 docs: README keeps only overview, hardware details move to wiring
    README now holds features, a short hardware section, build, structure
    and license. Hardware specifics from README (encoder, PCF8575 buttons,
    MIDI buffer, built-in peripherals) move to docs/wiring. The manual
    links to wiring instead of repeating it, drops third-party brand names
    (Access Virus kept) and fixes the voice count to 24. Enclosure README
    links point to wiring instead of removed README sections.
2026-10-15 feat: track insert chain, drive models, trance gate, envelope follower, master fx
    - Per-track insert (drive, crush, trance gate) moved from the voice to a track strip;
    TINS project chunk with migration from instrument drive / crush.
    - Drive models with ADAA; presets carry a recommended insert.
    - Trance gate and envelope follower per track (FOL page).
    - Master fx: MOD fx (chorus / ensemble / flanger / phaser), delay modes, shimmer,
    master EQ shelves, perf MOD throw and tape wobble.
    - Audio path optimised for the ESP32-S3 (no flash / ROM calls per sample).
    - Internal RAM: UI and sequencer cold data in PSRAM; synth and sequencer share one
    block that the Wi-Fi dialog moves to PSRAM and bac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
2026-10-15 docs: README lists track insert, follower and master fx
2026-10-21 docs: SVG wiring diagram without LEDs; track button 1 back on P00
2026-10-21 feat: PERF visuals on the whole screen, PERF on MIX
    While PERF effects are held the frame goes to the panel row by row through
    their look (mt::perfLook): filter darkens / washes out, crush posterizes
    (panel idle mode at 2-3 bit), downsample pixelates, gate inverts in time,
    repeat / roll tile, reverse mirrors, scratch / mod / wobble shift rows,
    tape stop slides down, delay ghosts, reverb blurs, freeze holds the frame.
    Two static internal line buffers (+1920 B), no heap, pixel code in flash.
    FILE -> SYSTEM -> Perf visuals turns it off.
    MIX joins GRID / SONG as a PERF tab: track buttons hold effects while
    playing, the encoder sets the held depth, B (no pan selected) or the PERF
    box under MAIN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
2026-10-22 feat: generative and performance features
    - GEN shift-register generator per track (PITCH / GATE, Flip, x2 INV, FLP step fx, Capture gen), ported from feature/teensy
    - Scala microtuning: factory tunings, .scl from /presets/TUN, Tuning root; Project : SynthModel split as on teensy
    - Song follow actions (JUMP / RANDOM / PREV / STAY + chance), project Seed, render Max slots
    - Evolve: per-track drift with Home pull, Rhythm / Note, Capture evo
    - XY pad on PERF (A+B), Kaoss-style master axes
    - Dice for the whole project with one-step undo; instrument Mutate 15 / 30 / 60 % with Undo
2026-10-22 feat: scenes and A-B crossfader
    - 8 project scenes of track / master locks, ported from feature/teensy (scene.*, SCEN chunk,
    SynthModel::xfade / sceneLive); the synth morphs A to B on read, smoothed ~30 ms, p-locks above
    the morph, LFO / follower on top; empty scenes render bit-identically
    - MIX: crossfader bar under the strips, A + turn moves it (PERF or not), A / B + track button N
    puts scene N on end A / B; full-width scope
    - SCENE view on Shift + A: big button panel, button-only editing (hold N + turn / click,
    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
2026-10-23 feat: generative 2 (VAR track mode, GEN BYTE, LFO BYTE)
    - VAR track mode: CA1D (Wolfram rules), CA2D on KIT lanes (LIFE, HIGHLIFE,
    SEEDS, DAYNIGHT, MAZE), MARKOV variation; order pattern -> VAR -> EVO -> GEN,
    rewind ring, deterministic per run seed, Capture var with undo
    - GEN modes BYTE PITCH / BYTE GATE: bytebeat formula drives degree and gate
    - LFO wave BYTE: bytebeat formula as LFO shape
    - Files: TVAR chunk, TGEN record grows, LFOB chunk, preset v7
    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
2026-10-27 feat: teensy port (DRUM calibration, DRUM picker, fatter FM, one-shot bake) + voice cost pool
    Ported from feature/teensy:
    - DRUM calibration (808/909 models, 3 tones, two-part envelopes, soft clip); Drum2 not ported
    - INST DRUM picker: group + model rows
    - Fatter FM: TONE detune, SAT, new KICK; FMEX chunk and preset v8 byte-compatible with teensy
    - One-shot bake: preview tap, two-pass deterministic render (Synth::reseed), trim, -0.3 dBFS
    normalize, library copy to /samples/oneshots, KIT bake; Save one-shot in PRESET/SAMPLE/KIT menus
    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
2026-10-27 feat: teensy UI port - MUT one mode per track, piano roll, keycaps
    - MUT: EVO and VAR as one mode per track (OFF / EVO / CA1D / CA2D on KIT /
    MARKOV), one MUT tab in TRACK, one Capture live in GRID; mutFix on load,
    TEVO keeps an inactive EVO mask with bit 0x80, format unchanged
    - GRID: third view Roll (Shift+click cycles Overview, Detail, Roll), KIT
    tracks show 8 drum lanes; A+B clears step or selection, undo only on
    Shift+B, GAT Shift step +-10 of the shown percent
    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
2026-11-10 feat: port Teensy workflows and optimize WT32 audio
    Port editor automation, recording practice, SONG controls, DICE recipes,
    sample and wavetable tools, modulation matrix, and supported Teensy UI.
    Retain classic FM, KIT8 and 32 kHz audio; remove PERF triplet durations.
    Make saves transactional and fix project-load memory failures. Reserve
    internal RAM for Synth and reverb, with Sequencer in PSRAM. Controlled
    WT32 P01 render time drops from 1964 to 1529 us without changing voices.
    Archive implementation plans and benchmark evidence under docs/plans,
    preserving raw captures and their checksums.
    Validation: 2217 native tests, 16 host checks, WT32 release build.
    Python gates: max CRAP 4, no d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
